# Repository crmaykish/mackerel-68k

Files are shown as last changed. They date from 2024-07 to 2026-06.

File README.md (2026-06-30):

# Mackerel 68k



Mackerel 68k is a family of homebrew single-board computers built around the Motorola 68000 line of processors plus a from-scratch effort to run **mainline Linux** on each one.

The project works its way up the 68k family one chip at a time, from the 68008 to the 68040. Each new board adds capability: more memory, faster CPUs, an FPU, an MMU, and richer peripherals. But the throughline is software - every Mackerel runs the **latest mainline Linux kernel**, from a tiny NOMMU uClinux shell on the 68008 up to a full MMU + hardware-FPU install on the 68030.

What's in the box, top to bottom:

- **Bespoke hardware** - custom PCBs with programmable logic chips (22V10 GALs on the 68008, Altera CPLDs on the later boards) handling address decoding, DRAM control, and interrupts.
- **A homegrown bootloader** - a small ROM monitor on every board with debug tools (peek, poke, memtest), YMODEM file transfer, and the ability to boot Linux from IDE or SD.
- **Custom toolchains** - bare-metal and Linux (MMU + NOMMU) GCC cross-compilers built with crosstool-ng.
- **Mainline Linux** - kernel port with drivers for the DUART, IDE storage, and Ethernet-over-SPI, booting to a BusyBox userspace.
- **Fully open source** - every schematic, PCB layout, logic file, and line of code is open, and hobbyists around the world have built their own Mackerel boards.

Three discrete boards are running today (68008, 68010, and 68030), with a 68040 system in the works - plus Mackerel-F, an FPGA build that runs a full Mackerel system on a soft 68000 core.

## Links

1. [Hackaday Project Page](https://hackaday.io/project/183861-mackerel-68k-computer)
2. [Mackerel Linux v7.1.x](https://github.com/crmaykish/mackerel-linux/tree/mackerel)
3. [Mackerel uClinux (deprecated)](https://github.com/crmaykish/mackerel-uclinux-20160919)

## Docs

1. [Mackerel-08 Assembly](docs/mackerel-08-board-assembly.md)
2. [How to Compile Code and Programmable Logic](docs/how-to-compile-everything.md)
3. [Building the Mackerel Toolchains](docs/building-the-mackerel-toolchains.md)
4. [Building and Booting Linux on Mackerel](docs/building-linux-for-mackerel.md)
5. [Building and Running Mackerel-F (FPGA)](docs/building-and-running-mackerel-f.md)

## Hardware

### Mackerel-08

Status: Complete

- MC68008 CPU (52-pin PLCC variant)
- 512 KB of Flash ROM, 3.5MB SRAM
- Two serial ports
- SD card support (bitbang SPI)
- Linux 7.1.x NOMMU

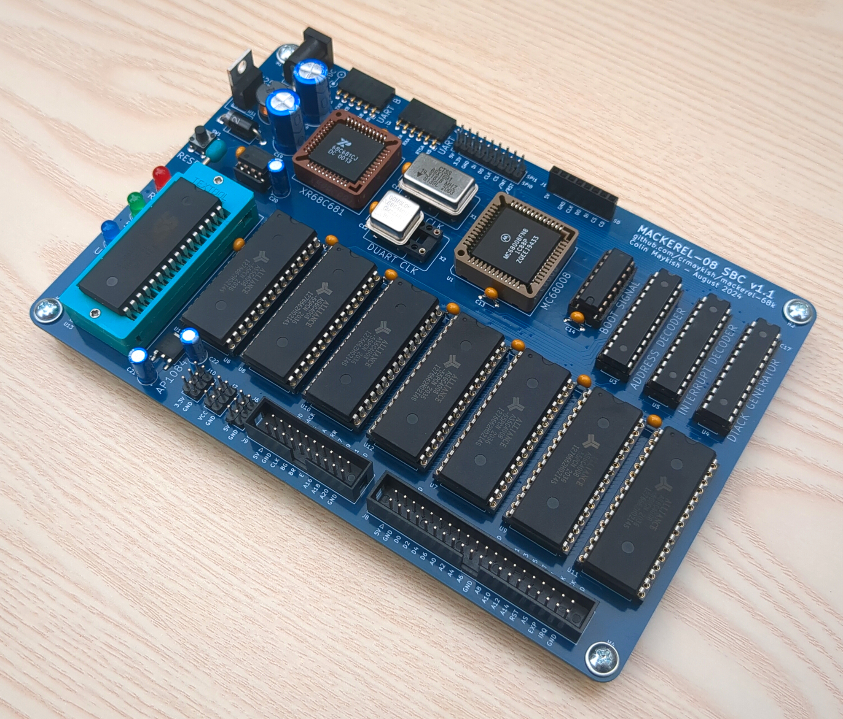
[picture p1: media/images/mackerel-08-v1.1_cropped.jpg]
Mackerel-08 SBC v1


Based on the original prototype hardware, this SBC combines the 52-pin PLCC MC68008, a 512KB Flash ROM, up to 3.5MB of SRAM, and a XR68C681 DUART on a single PCB. The DUART exposes two serial ports and three bit-banged SPI headers. One of these headers is currently used with an SD card breakout board to provide bulk storage.

Three 22V10 PLDs are used for address decoding, interrupt mapping, and DTACK generation. An expansion header breaks out address, data, and control lines to allow additional peripherals to be connected directly to the processor bus.

The address space is mapped as follows:

- RAM:    0x000000 - 0x37FFFF (up to 3.5 MB)
- ROM:    0x380000 - 0x3FBFFF (496/512 KB usable)
- DUART:  0x3FC000 - 0x3FDFFF (8KB)
- Exp:    0x3FE000 - 0x3FFFFF (Expansion header, 8KB)

Mackerel-08 uses a 74HC595 shift register to create a BOOT signal for the first eight /AS cycles of the CPU after reset. This BOOT signal is used by the address decoder PLD to map the ROM to address 0x000000 long enough for the CPU to read the initial stack pointer and program counter vectors from ROM. RAM is mapped to 0x000000 after that.

### Mackerel-10

Status: Complete

- MC68000 or MC68010 CPU
- 1 MB of ROM, 1 MB of SRAM
- Up to 16 MB of 30-pin DRAM (15 usable)
- Two serial ports
- IDE interface
- Linux 7.1.x NOMMU

Mackerel-10 v1

Mackerel-10 is the second SBC in the project. It expands on the design of Mackerel-08 with a MC68010 CPU (or equivalent), the same XR68C681 DUART, 1MB of Flash ROM, 1MB of SRAM, up to 16 MB of DRAM, and an IDE drive interface. Two CPLDs act as the glue logic and DRAM controller for the board. The SRAM is optional and the address space can be filled almost entirely with DRAM.

The memory map looks like this:

- DRAM:     0x000000 - 0xEFFFFF (15MB)
- ROM:      0xF00000 - 0xFF4000 (not quite 1MB)
- I/O:      0xF40000 - 0xFFFFFF

### Mackerel-30

Status: Prototype

- MC68030 CPU at 20 MHz
- MC68882 FPU
- 512 KB ROM, 512 KB SRAM
- 128 MB of 72-pin DRAM
- Two serial ports
- IDE interface
- Ethernet over SPI
- Linux 7.1.x

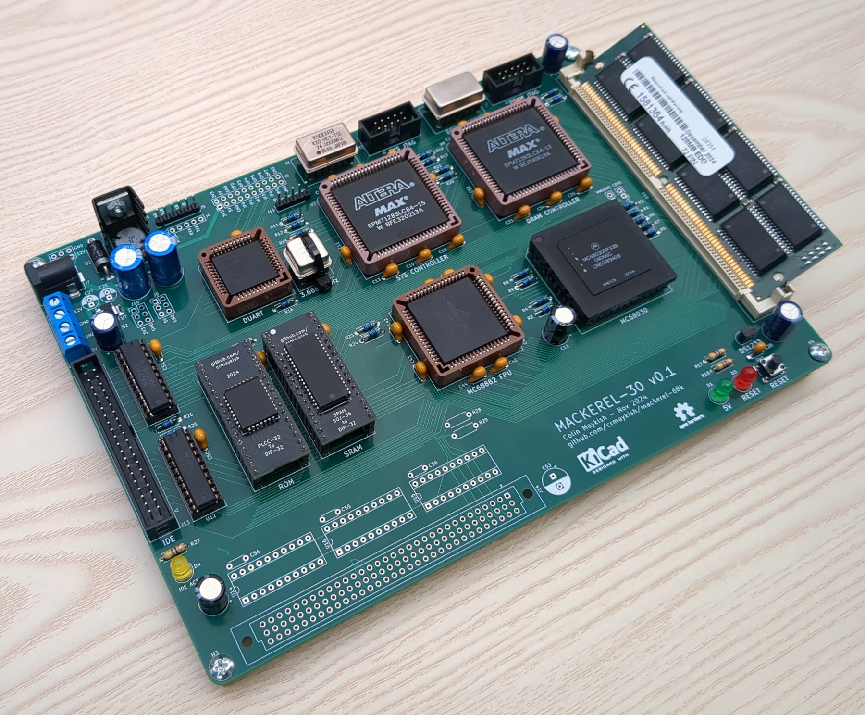
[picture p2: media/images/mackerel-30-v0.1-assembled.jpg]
Mackerel-30 v0.1


Mackerel-30 is based on the 68030 CPU. It includes the DUART and IDE interface from Mackerel-10 and upgrades the DRAM controller to use a 72-pin SIMM. It also includes a MC68882 FPU.

### Mackerel-40
Status: Design

- 68040 CPU at 33 MHz (internal MMU and FPU)
- 2 MB of ROM, 2 MB SRAM
- 2x72 pin SIMMs (up to 256 MB of DRAM)
- Dedicated I/O controller (SPI, I2C, GPIO)
- DUART and IDE from earlier boards

### Mackerel-F

Status: Prototype (FPGA)

- fx68k soft 68000 core at 37.8 MHz, in a Tang Nano 20k
- 8 MB SDRAM
- 30 KB ROM (bootloader) and 32 KB BSRAM
- UART console, programmable timer, and interrupt controller
- microSD (SPI) and W5500 Ethernet
- Linux 7.1.x NOMMU

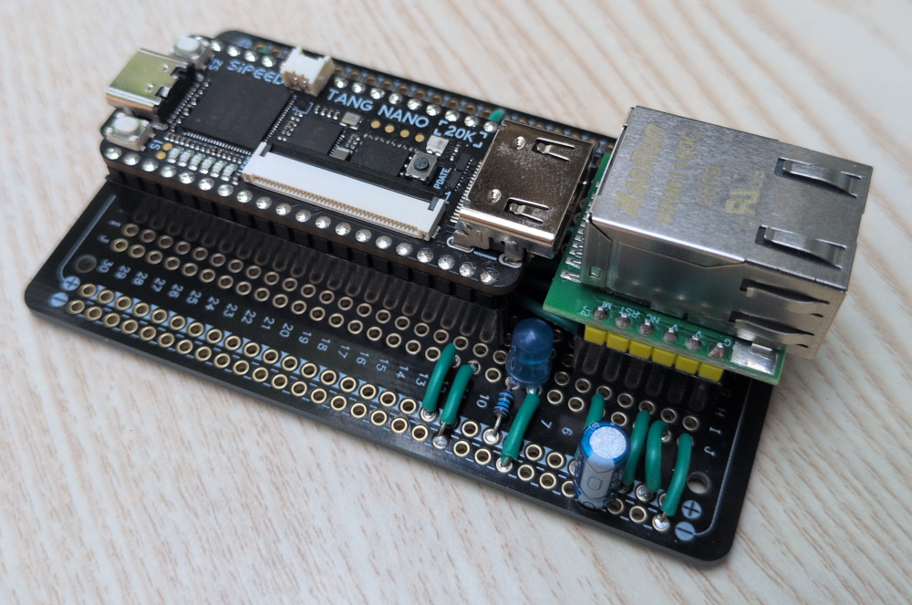
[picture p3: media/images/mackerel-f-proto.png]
Mackerel-F on a Tang Nano 20k


Mackerel-F is an entire Mackerel system implemented inside an FPGA. Everything that is discrete hardware on the other boards - the CPU, glue logic, memory controller, UART, timer, interrupt controller, and SPI masters - is RTL here, built around the [fx68k](https://github.com/ijor/fx68k) soft 68000 core and synthesized for the Tang Nano 20k. The SoC runs at 75.6 MHz with the 68000 core clocked at half that (37.8 MHz).

Unlike the other boards there is no separate ROM chip: the bootloader is baked into the FPGA bitstream as on-chip ROM and its scratch RAM lives in block RAM, so the entire 8 MB of SDRAM is free for Linux. Alongside the usual `boot` (from SD) and YMODEM transfer, the bootloader adds a `netboot` command that pulls the kernel over Ethernet (raw TCP, with a small host server) and a five-second SD autoboot.

The memory map:

- RAM:    0x000000 - 0x7FFFFF (8 MB SDRAM, the top 384 KB holds the execute-in-place root filesystem)
- BSRAM:  0xFF0000 - 0xFF7FFF (32 KB, bootloader RAM)
- ROM:    0xFF8000 - 0xFFF7FF (30 KB, bootloader ROM)
- I/O:    0xFFF800 - 0xFFFFFF (GPIO, UART, timer, two SPI masters, interrupt controller)

It boots mainline NOMMU uClinux to a BusyBox shell from a ROMfs root run in place from SDRAM, with the microSD for storage and the W5500 for networking. See [Building and Running Mackerel-F (FPGA)](docs/building-and-running-mackerel-f.md).

## Software

### Bootloader and Bare-metal Programs
Every version of Mackerel runs a small bootloader program installed on the Flash ROM. This provides a simple set of debugging tools (peek, poke, memtest, etc.) as well as two methods for loading external code.

The bootloader supports the YMODEM protocol for loading programs and data into RAM (see the `ymodem` command), using `lrzsz-sb` on the PC for example. Other terminal programs like TeraTerm should also work.

The `boot` command is used to load the Linux kernel from disk (SD or IDE). It expects a `IMAGE.BIN` file on the first FAT16 partition of the drive. See the `prepare_disk.sh` script in the [mackerel-linux repository](https://github.com/crmaykish/mackerel-linux).

On Mackerel-F the bootloader also supports `netboot` (pulling the kernel over Ethernet) and a five-second SD autoboot on power-up.

### Linux on Mackerel

Every Mackerel board runs the latest mainline kernel (v7.1.x). Mackerel-08, Mackerel-10, and the FPGA-based Mackerel-F run NOMMU and are more limited in their capabilities. Mackerel-30 supports the MMU and the external FPU in Linux and functions more like a traditional headless Linux install. Userspace is made up of busybox (init and shell) with driver support for the DUART, IDE storage, and networking over SPI.

### Compilers and Tools
There are three different toolchains for Mackerel. The baremetal toolchain builds the bootloader and other low level programs in this repo. There are also two variants of the Linux toolchain - one for Mackerel-30 with MMU support and the other for NOMMU/ucLinux on Mackerel-08/10. Prebuilt toolchains are available on the [releases page](https://github.com/crmaykish/mackerel-68k/releases/tag/toolchains-2026-06-06); see [Building the Mackerel Toolchains](docs/building-the-mackerel-toolchains.md) for both the download steps and instructions on building them all with crosstools-ng.

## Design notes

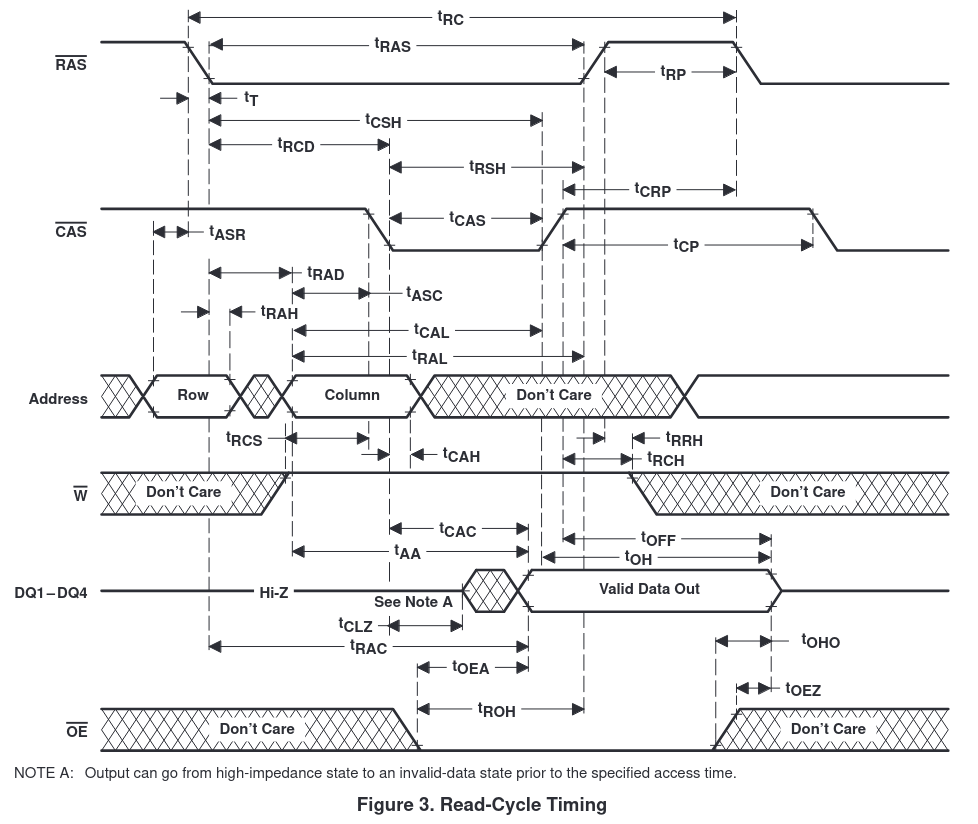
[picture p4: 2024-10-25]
media/images/dram_read_timing.png

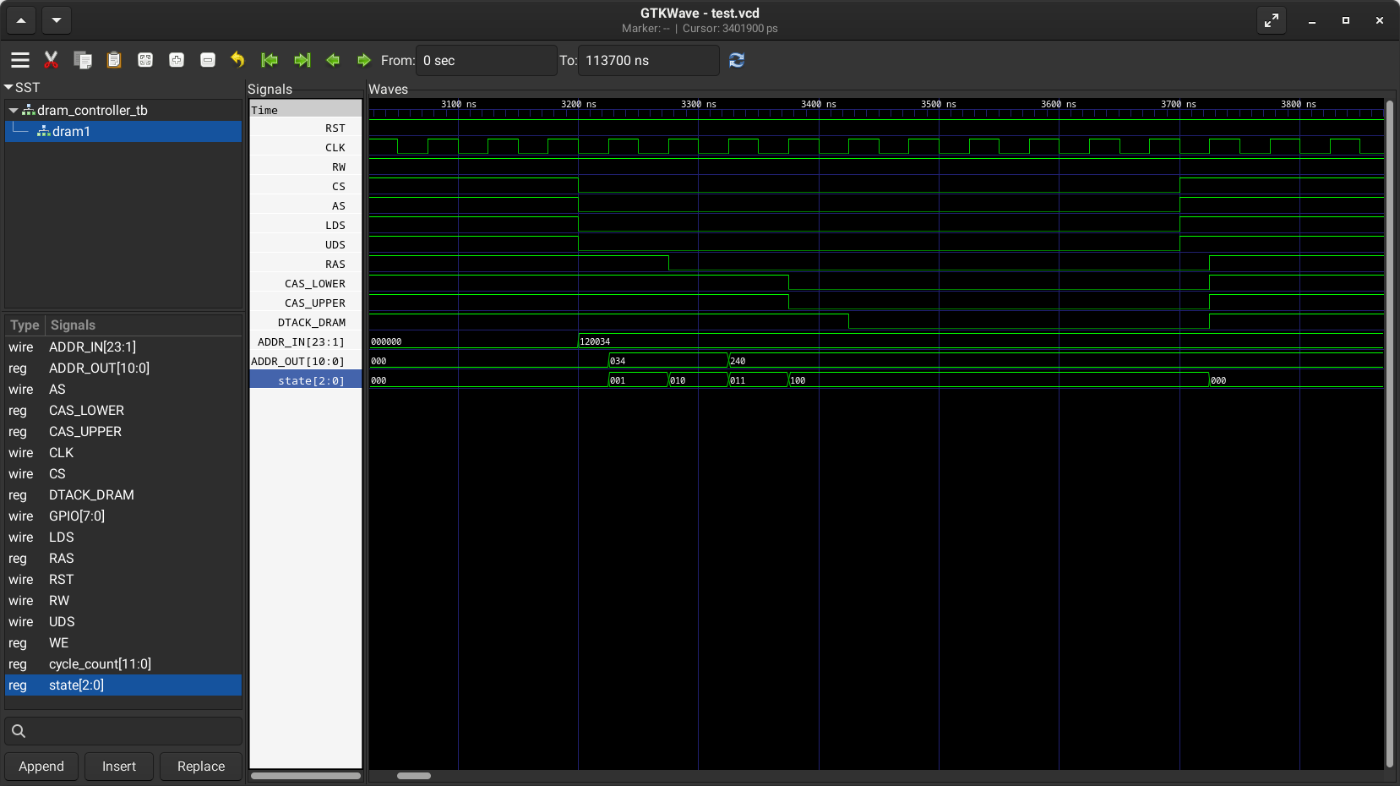
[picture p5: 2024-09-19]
media/images/dram_read_cycle_simulation.png

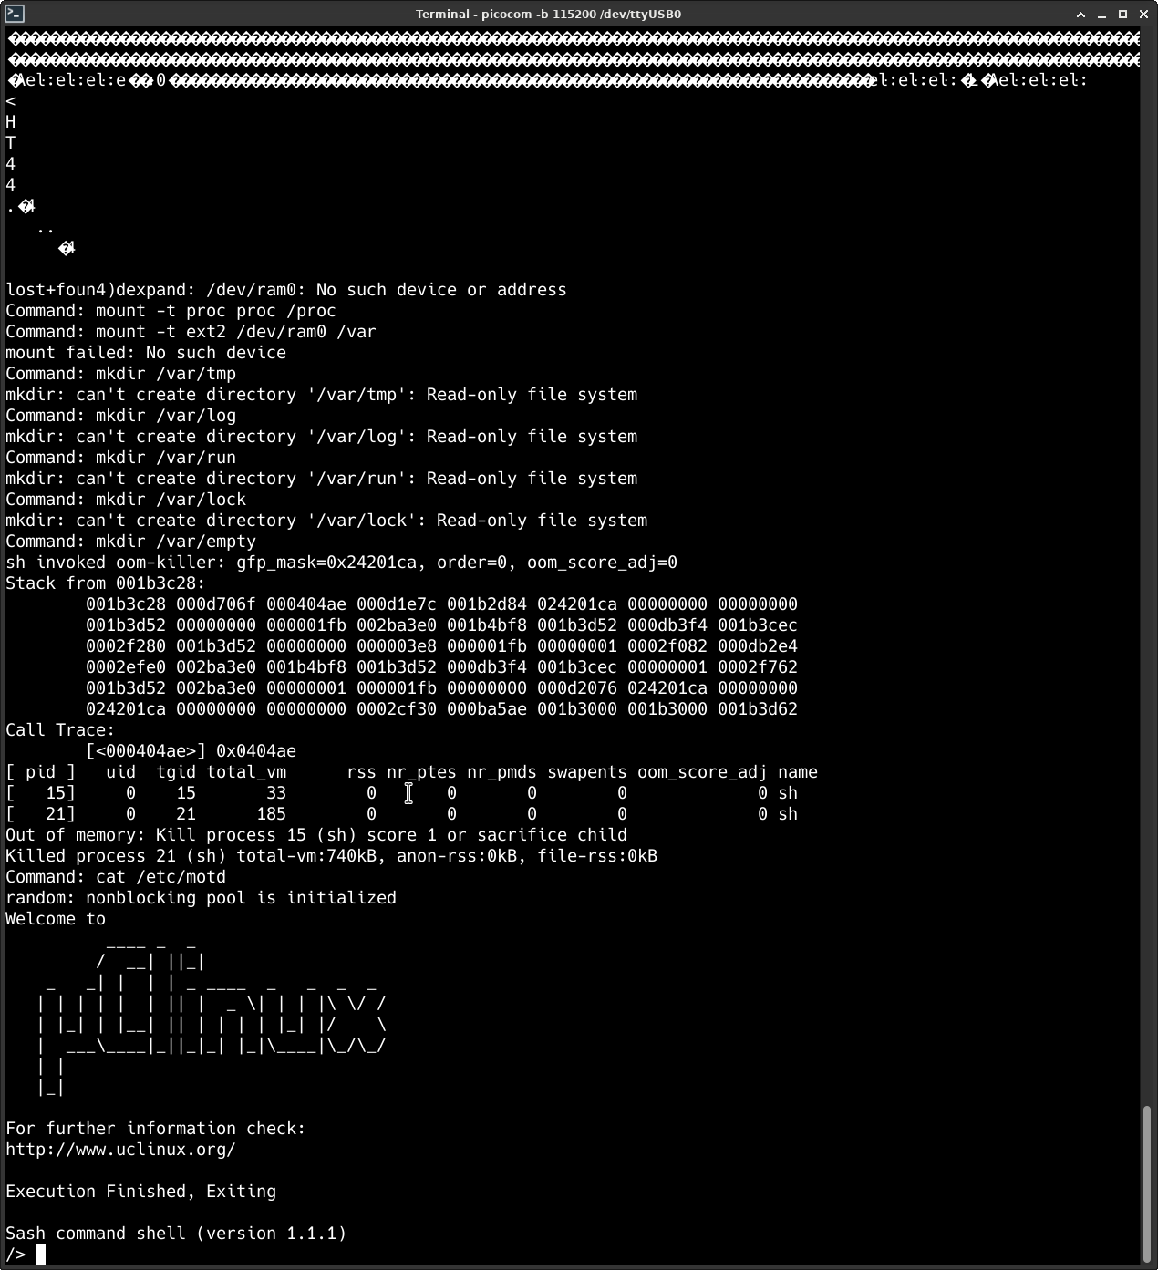
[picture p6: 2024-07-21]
media/images/uclinux-4.4-first-real-boot.png

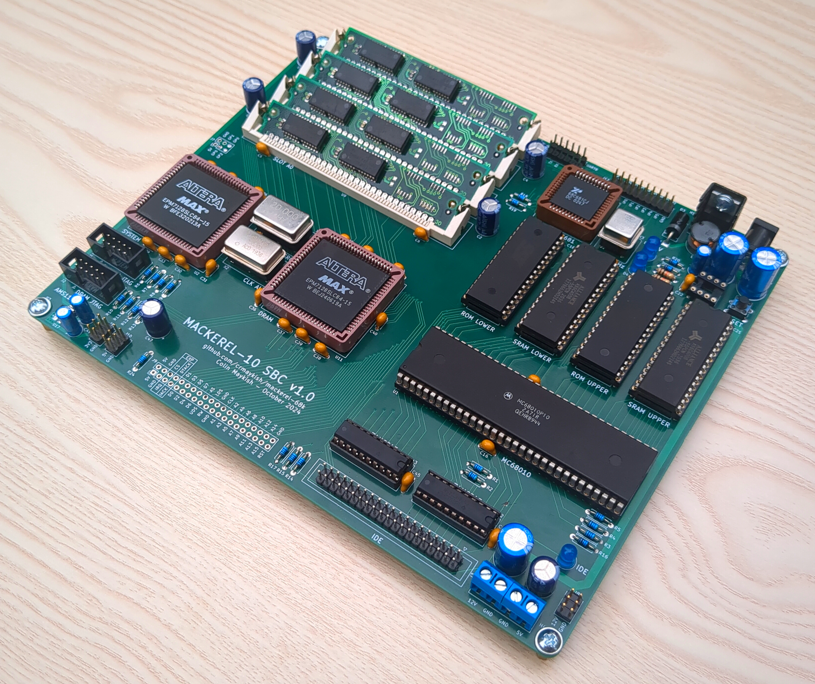
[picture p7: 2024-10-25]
media/images/mackerel-10-v1_cropped.jpg

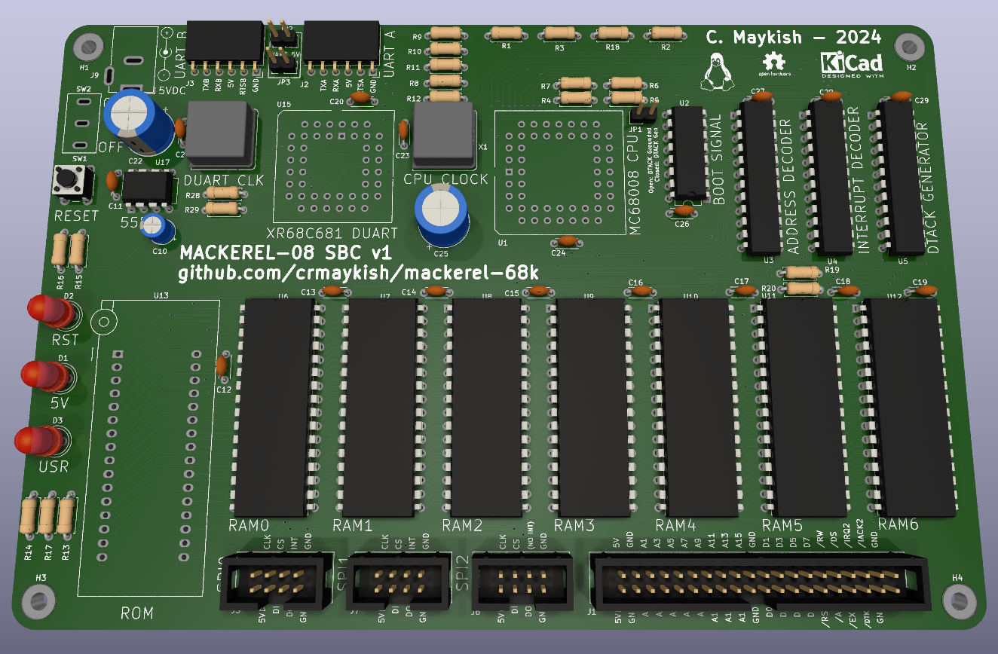
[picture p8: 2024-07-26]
media/images/mackerel-08-sbc-v1-render.png

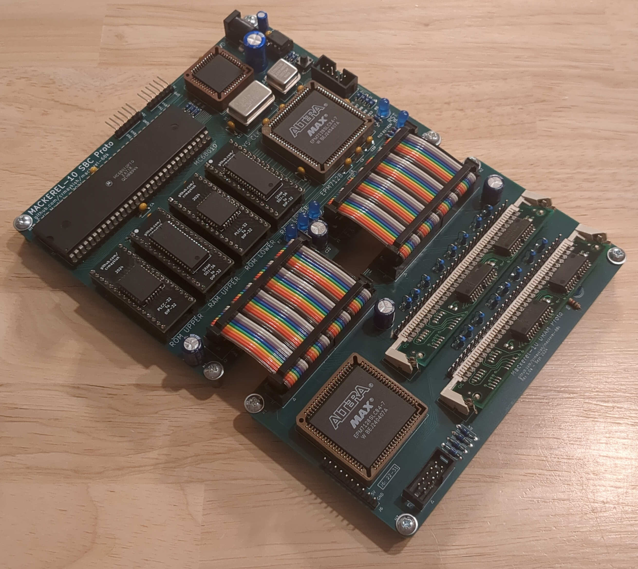
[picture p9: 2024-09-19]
media/images/mack-10-with-dram-controller.jpg

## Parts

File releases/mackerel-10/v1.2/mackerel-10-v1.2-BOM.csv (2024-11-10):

Reference | Value | Datasheet | Footprint | Qty | DNP
C1,C2,C3,C4,C5,C6,C7,C8,C9,C10,C11,C12,C13,C14,C15,C16,C21,C22,C23,C24,C25,C26,C27,C28,C29,C30,C31,C32,C33,C34,C35,C36,C37,C38,C41,C42 | 0.1uF | ~ | Capacitor_THT:C_Disc_D4.3mm_W1.9mm_P5.00mm | 36
C17,C18,C19,C20,C40,C49 | 470uF | ~ | Capacitor_THT:CP_Radial_D8.0mm_P3.50mm | 6
C39,C43,C44 | 1000uF | ~ | Capacitor_THT:CP_Radial_D10.0mm_P5.00mm | 3
C45,C46 | 10uF | ~ | Capacitor_THT:CP_Radial_D5.0mm_P2.00mm | 2
C47 | 0.01uF | ~ | Capacitor_THT:C_Disc_D4.3mm_W1.9mm_P5.00mm | 1
D1,D2,D4 | LED | ~ | LED_THT:LED_D5.0mm | 3
D3 | 1N5822 | ~ | Diode_THT:D_DO-27_P15.24mm_Horizontal | 1
HS1 | Heatsink | ~ | Heatsink:Heatsink_Stonecold_HS-S02_13.21x9.53mm | 1
J1,J3 | Conn_02x05_Odd_Even | ~ | Connector_IDC:IDC-Header_2x05_P2.54mm_Vertical | 2
J2,J10,J11,J12 | Conn_02x03_Odd_Even | ~ | Connector_PinHeader_2.54mm:PinHeader_2x03_P2.54mm_Vertical | 4
J4 | Screw_Terminal_01x04 | ~ | TerminalBlock:TerminalBlock_bornier-4_P5.08mm | 1
J5,J13 | Conn_02x20_Odd_Even | ~ | -- mixed values -- | 2
J6,J7 | Conn_01x06 | ~ | Connector_PinHeader_2.54mm:PinHeader_1x06_P2.54mm_Vertical | 2
J8 | Conn_02x10_Odd_Even | ~ | Connector_PinHeader_2.54mm:PinHeader_2x10_P2.54mm_Vertical | 1
J9 | Barrel_Jack_MountingPin | ~ | Connector_BarrelJack:BarrelJack_Horizontal | 1
L1 | 100uH | ~ | Inductor_THT:L_Radial_D10.0mm_P5.00mm_Fastron_07M | 1
R1,R2,R3,R4,R5,R6,R7,R8,R9,R10,R11,R12,R13,R14,R15,R16,R17,R19,R20 | 4k7 | ~ | Resistor_THT:R_Axial_DIN0207_L6.3mm_D2.5mm_P7.62mm_Horizontal | 19
R18,R21,R22 | 1k | ~ | Resistor_THT:R_Axial_DIN0207_L6.3mm_D2.5mm_P7.62mm_Horizontal | 3
SW1 | SW_Push | ~ | Button_Switch_THT:SW_PUSH_6mm_H5mm | 1
U1 | 68010D | https://www.nxp.com/docs/en/reference-manual/MC68000UM.pdf | Package_DIP:DIP-64_W22.86mm | 1
U2,U7,U8,U9,U10,U11 | ~ |  | -- mixed values -- | 6
U3,U5 | SST39SF040 | http://ww1.microchip.com/downloads/en/DeviceDoc/25022B.pdf | Package_DIP:DIP-32_W15.24mm | 2
U4,U6 | AS6C4008-55PCN | https://www.alliancememory.com/wp-content/uploads/pdf/AS6C4008.pdf | Package_DIP:DIP-32_W15.24mm | 2
U12,U13 | 74HC245 | http://www.ti.com/lit/gpn/sn74HC245 | Package_DIP:DIP-20_W7.62mm_Socket | 2
U14 | XR68C681 |  | Package_LCC:PLCC-44_THT-Socket | 1
U15 | LM2576T-5 | http://www.ti.com/lit/ds/symlink/lm2576.pdf | Package_TO_SOT_THT:TO-220-5_Vertical | 1
U16 | AMS1117-3.3 | http://www.advanced-monolithic.com/pdf/ds1117.pdf | Package_TO_SOT_SMD:SOT-223-3_TabPin2 | 1
U17 | DS1233 |  | Package_TO_SOT_THT:TO-92L_Inline | 1
X1,X2 | 50MHz | http://cdn-reichelt.de/documents/datenblatt/B400/OSZI.pdf | Oscillator:Oscillator_DIP-14 | 2
X3 | 3.6864MHz | http://cdn-reichelt.de/documents/datenblatt/B400/OSZI.pdf | Oscillator:Oscillator_DIP-8 | 1

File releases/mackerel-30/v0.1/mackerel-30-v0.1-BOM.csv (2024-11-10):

Reference | Value | Datasheet | Footprint | Qty | DNP
C1,C2,C3,C4,C5,C6,C7,C8,C9,C10,C12,C13,C14,C15,C16,C17,C18,C19,C20,C21,C22,C23,C29,C30,C31,C32,C33,C34,C35,C36,C38,C39,C40,C42,C43,C44,C45,C46,C47,C48,C49,C50,C51,C54,C55,C56 | 0.1uF | ~ | -- mixed values -- | 46
C11,C37,C41,C52,C53,C57 | 470uF | ~ | Capacitor_THT:CP_Radial_D8.0mm_P3.50mm | 6
C24,C26 | 1000uF | ~ | Capacitor_THT:CP_Radial_D10.0mm_P5.00mm | 2
C25,C27 | 10uF | ~ | Capacitor_THT:CP_Radial_D5.0mm_P2.00mm | 2
C28 | 0.01uF | ~ | Capacitor_THT:C_Disc_D4.3mm_W1.9mm_P5.00mm | 1
D1,D3,D4 | LED | ~ | LED_THT:LED_D5.0mm | 3
D2 | 1N5822 | ~ | Diode_THT:D_DO-27_P15.24mm_Horizontal | 1
HS1 | Heatsink | ~ | Heatsink:Heatsink_Stonecold_HS-S02_13.21x9.53mm | 1
J1,J2 | Conn_01x02 | ~ | Connector_PinHeader_2.54mm:PinHeader_1x02_P2.54mm_Vertical | 2
J3,J11 | Conn_02x05_Odd_Even | ~ | Connector_IDC:IDC-Header_2x05_P2.54mm_Vertical | 2
J4,J5 | Conn_01x06 | ~ | Connector_PinHeader_2.54mm:PinHeader_1x06_P2.54mm_Vertical | 2
J6 | Conn_02x10_Odd_Even | ~ | Connector_PinHeader_2.54mm:PinHeader_2x10_P2.54mm_Vertical | 1
J7 | Barrel_Jack_MountingPin | ~ | Connector_BarrelJack:BarrelJack_Horizontal | 1
J8,J9,J10 | Conn_02x03_Odd_Even | ~ | Connector_PinHeader_2.54mm:PinHeader_2x03_P2.54mm_Vertical | 3
J12 | Screw_Terminal_01x04 | ~ | TerminalBlock:TerminalBlock_bornier-4_P5.08mm | 1
J13 | Conn_02x20_Odd_Even | ~ | Connector_IDC:IDC-Header_2x20_P2.54mm_Vertical | 1
J14 | DIN41612_03x32_ABC | ~ | Connector_DIN:DIN41612_C_3x32_Female_Vertical_THT | 1
J15 | Conn_01x05 | ~ | Connector_PinHeader_2.54mm:PinHeader_1x05_P2.54mm_Vertical | 1
L1 | 100uH | ~ | Inductor_THT:L_Radial_D10.0mm_P5.00mm_Fastron_07M | 1
R1,R2,R3,R4,R5,R6,R7,R8,R9,R10,R11,R12,R13,R14,R15,R16,R19,R20,R21,R22,R23,R24,R25,R26,R28,R29 | 4k7 | ~ | Resistor_THT:R_Axial_DIN0207_L6.3mm_D2.5mm_P7.62mm_Horizontal | 26
R17,R18,R27 | 1k | ~ | Resistor_THT:R_Axial_DIN0207_L6.3mm_D2.5mm_P7.62mm_Horizontal | 3
SW1 | SW_Push | ~ | Button_Switch_THT:SW_PUSH_6mm_H5mm | 1
U1 | MC68030RC |  | mackerel:PGA169 | 1
U2,U9 | EPM7128 |  | Package_LCC:PLCC-84_THT-Socket | 2
U3 | SST39SF040 | http://ww1.microchip.com/downloads/en/DeviceDoc/25022B.pdf | Package_DIP:DIP-32_W15.24mm_Socket | 1
U4 | AS6C4008-55PCN | https://www.alliancememory.com/wp-content/uploads/pdf/AS6C4008.pdf | Package_DIP:DIP-32_W15.24mm_Socket | 1
U5 | XR68C681 |  | Package_LCC:PLCC-44_THT-Socket | 1
U6 | LM2576T-5 | http://www.ti.com/lit/ds/symlink/lm2576.pdf | Package_TO_SOT_THT:TO-220-5_Vertical | 1
U7 | AMS1117-3.3 | http://www.advanced-monolithic.com/pdf/ds1117.pdf | Package_TO_SOT_SMD:SOT-223-3_TabPin2 | 1
U8 | DS1233 |  | Package_TO_SOT_THT:TO-92L_Inline | 1
U10 | SIMM72 |  | mackerel:SIMM-72 | 1
U11 | MC68882 |  | Package_LCC:PLCC-68_THT-Socket | 1
U12,U13,U14,U15,U16 | 74HC245 | http://www.ti.com/lit/gpn/sn74HC245 | Package_DIP:DIP-20_W7.62mm_Socket | 5
X1,X3 | CXO_DIP14 | http://cdn-reichelt.de/documents/datenblatt/B400/OSZI.pdf | Oscillator:Oscillator_DIP-14 | 2
X2 | 3.6864MHz | http://cdn-reichelt.de/documents/datenblatt/B400/OSZI.pdf | Oscillator:Oscillator_DIP-8 | 1

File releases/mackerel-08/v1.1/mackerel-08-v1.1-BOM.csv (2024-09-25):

Reference | Value | Datasheet | Footprint | Qty | DNP
C1,C2,C3,C4,C5,C6,C7,C8,C9,C10,C11,C12,C13,C14,C15,C16,C17 | 0.1uF | ~ | Capacitor_THT:C_Disc_D4.3mm_W1.9mm_P5.00mm | 17
C18,C19 | 1000uF | ~ | Capacitor_THT:CP_Radial_D10.0mm_P5.00mm | 2
C20,C21,C22 | 10uF | ~ | Capacitor_THT:CP_Radial_D5.0mm_P2.50mm | 3
D1,D2,D4 | LED | ~ | LED_THT:LED_D5.0mm | 3
D3 | 1N5822 | ~ | Diode_THT:D_DO-27_P15.24mm_Horizontal | 1
H1,H2,H3,H4 | MountingHole | ~ | MountingHole:MountingHole_3.2mm_M3_Pad | 4
HS1 | Heatsink | ~ | Heatsink:Heatsink_Stonecold_HS-S02_13.21x9.53mm | 1
J1 | Conn_01x08 | ~ | Connector_PinSocket_2.54mm:PinSocket_1x08_P2.54mm_Vertical | 1
J2 | Conn_02x09_Odd_Even | ~ | Connector_PinHeader_2.54mm:PinHeader_2x09_P2.54mm_Vertical | 1
J3,J4 | Conn_01x06 | ~ | Connector_PinSocket_2.54mm:PinSocket_1x06_P2.54mm_Horizontal | 2
J5 | Barrel_Jack_MountingPin | ~ | Connector_BarrelJack:BarrelJack_Horizontal | 1
J6,J7,J10 | Conn_02x03_Odd_Even | ~ | Connector_PinHeader_2.54mm:PinHeader_2x03_P2.54mm_Vertical | 3
J8 | Conn_02x20_Odd_Even | ~ | Connector_IDC:IDC-Header_2x20_P2.54mm_Vertical | 1
J9 | Conn_02x10_Odd_Even | ~ | Connector_IDC:IDC-Header_2x10_P2.54mm_Vertical | 1
L1 | 100uH | ~ | Inductor_THT:L_Radial_D10.0mm_P5.00mm_Fastron_07M | 1
R1,R2,R3,R4,R5,R6,R7,R8,R9,R10,R11,R12,R13,R14,R16,R17,R18,R19 | 4k7 | ~ | Resistor_SMD:R_1206_3216Metric_Pad1.30x1.75mm_HandSolder | 18
R15,R20,R23 | 1k | ~ | Resistor_SMD:R_1206_3216Metric_Pad1.30x1.75mm_HandSolder | 3
R21,R22 | 10k | ~ | Resistor_SMD:R_1206_3216Metric_Pad1.30x1.75mm_HandSolder | 2
SW1 | SW_Push | ~ | Button_Switch_THT:SW_PUSH_6mm_H5mm | 1
U1 | MC68008 |  | Package_LCC:PLCC-52_THT-Socket | 1
U2 | 74HC595 | http://www.ti.com/lit/ds/symlink/sn74hc595.pdf | Package_DIP:DIP-16_W7.62mm | 1
U3,U4,U5 | ATF22V10C |  | Package_DIP:DIP-24_W7.62mm | 3
U6,U7,U8,U9,U10,U11,U12 | AS6C4008-55PCN | https://www.alliancememory.com/wp-content/uploads/pdf/AS6C4008.pdf | Package_DIP:DIP-32_W15.24mm | 7
U13 | SST39SF040 |  | Socket:DIP_Socket-32_W11.9_W12.7_W15.24_W17.78_W18.5_3M_232-1285-00-0602J | 1
U14 | XR68C681 |  | Package_LCC:PLCC-44_THT-Socket | 1
U15 | LM2576T-5 | http://www.ti.com/lit/ds/symlink/lm2576.pdf | Package_TO_SOT_THT:TO-220-5_Vertical | 1
U16 | NE555P | http://www.ti.com/lit/ds/symlink/ne555.pdf | Package_DIP:DIP-8_W7.62mm | 1
U17 | AP1084 |  | Package_TO_SOT_SMD:TO-252-2 | 1
X1,X2 | CXO_DIP14 | http://cdn-reichelt.de/documents/datenblatt/B400/OSZI.pdf | Oscillator:Oscillator_DIP-14 | 2

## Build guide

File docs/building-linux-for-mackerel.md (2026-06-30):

# Building and Booting Linux on Mackerel

## Quick reference

```sh
# Replace '30' with '10', '08', or 'f' depending on your target
bash clean_all.sh
bash build_busybox.sh 30
bash build_rootfs.sh 30
bash build_kernel.sh 30
sudo bash prepare_disk.sh /dev/sdX # First time only
sudo bash install_disk.sh /dev/sdX 30
minipro -p SST39SF040 -s -w rom08.bin # Mackerel-08 only
# Insert card, power on, run `boot` from the bootloader
```
---

Every Mackerel board runs the **same mainline Linux kernel** (currently 7.1). There is a single in-tree platform, `arch/m68k/mackerel/`, shared by every board; the per-board differences (CPU, MMU vs. NOMMU, memory map, root filesystem) are selected by a defconfig. Everything is built from the [mackerel-linux](https://github.com/crmaykish/mackerel-linux) repo through the **same handful of scripts**, each of which takes a single board argument:

| Board | Argument | CPU | MMU | Root filesystem | Storage |
|---|---|-----|-----|---|---|
| Mackerel-30 | `30` (default) | 68030 | yes | ext4 on disk (`/dev/sda2`) | IDE / CompactFlash |
| Mackerel-10 | `10` | 68000/68010 | no | embedded initramfs, optional ext root on `/dev/sda2` | IDE / CompactFlash |
| Mackerel-08 | `08` | 68008 | no | ROMfs flashed to the ROM chip | (none) |
| Mackerel-F | `f` | 68000 (fx68k softcore) | no | ROMfs run in place from SDRAM | microSD (SPI) |

Every board boots the same way: the bootloader's `boot` command reads `IMAGE.BIN` from the boot partition of the storage device into RAM and jumps to it. (Mackerel-F can also pull the image over Ethernet with `netboot`; see [Building and Running Mackerel-F (FPGA)](building-and-running-mackerel-f.md).)

In every command below, swap the board argument (`30`, `10`, `08`, or `f`) to target a different board. The argument defaults to `30` if omitted.

## Prerequisites

1. **Toolchains.** Mackerel-30 uses the musl toolchain (`m68k-mackerel-linux-musl-`); Mackerel-08, Mackerel-10, and Mackerel-F share the uClibc NOMMU toolchain (`m68k-mackerel-uclinux-uclibc-`). The build scripts pick the right one from the board argument. See [Building the Mackerel Toolchains](building-the-mackerel-toolchains.md).

2. **The kernel source.**

   ```sh
   git clone https://github.com/crmaykish/mackerel-linux
   cd mackerel-linux
   git checkout mackerel
   ```

3. **Host tools.** `parted` + `mkfs.fat`/`mkfs.ext4` for preparing the storage media. Building the Mackerel-08 root filesystem also needs `genromfs` (on Arch it is in the AUR). `lrzsz` (the `lrzsz-sb` sender) is only needed for the YMODEM fallback described at the end. The `tools/install_reqs_*` scripts in the main repo install these.

## Building

The build is the same three steps for every board - BusyBox, then the root filesystem, then the kernel - run from the repo root:

```sh
bash build_busybox.sh 30    # build BusyBox (bFLT on NOMMU)
bash build_rootfs.sh  30    # assemble the root filesystem for this board
bash build_kernel.sh  30    # distclean + defconfig + build -> image.bin
```

Run them in that order - `build_rootfs.sh` needs the BusyBox binary, and `build_kernel.sh` embeds the root filesystem into the image. Each script prints what it produced; the final artifact is always **`image.bin`** in the repo root.

What each board's scripts produce:

- **Mackerel-30** - BusyBox `busybox` (dynamic musl), a full root tree in `rootfs_mackerel30/` (written to disk separately), and a ~5 MB `image.bin` that loads and runs at `0x1000`.
- **Mackerel-10** - BusyBox `busybox_nommu` (bFLT), an XIP ROMfs root appended into `image.bin` (via `MTD_UCLINUX`; bare ROMfs intermediate is `rom.bin`), which loads and runs at `0x400`.
- **Mackerel-08** - BusyBox `busybox_mackerel08` (bFLT), also assembles `rom08.bin`.
- **Mackerel-F** - BusyBox `busybox_mackerelf` (bFLT), an XIP ROMfs root appended into `image.bin` (via `MTD_UCLINUX`; bare ROMfs intermediate is `rom.bin`), which loads and runs at `0x400`.

To start completely fresh, `bash clean_all.sh` removes all build products and intermediate trees.

## Booting

Write `image.bin` to the storage media, put it in the board, and run `boot` from the bootloader prompt. The two disk scripts handle the media for every board and take the same board argument as the build (replace `/dev/sdX` with your card's device - double-check it, this erases the media):

```sh
sudo bash prepare_disk.sh /dev/sdX        # FAT16 16 MB (boot) + ext4 100 MB (root)
sudo bash install_disk.sh /dev/sdX 30     # IMAGE.BIN -> boot partition, rootfs -> root partition
```

`prepare_disk.sh` only needs to be run once per card and should support any drive 128 MB or bigger. After rebuilding the kernel or rootfs, re-run `install_disk.sh` to update the media. What gets written depends on the board:

- **Mackerel-30** - `IMAGE.BIN` to the FAT16 boot partition and the full ext4 root tree to `sda2`. `boot` reads the image into RAM, writes the Linux bootinfo records after it, and jumps to the kernel, which mounts `sda2` as root.
- **Mackerel-10** - `IMAGE.BIN` to the boot partition and the ext root to `sda2`. The image carries a self-contained initramfs, so it boots without a root on `sda2`; if one is present, `/init` `switch_root`s into it (falling back to the RAM initramfs if the disk is absent).
- **Mackerel-08** - just `IMAGE.BIN` to the SD card's FAT partition; the root filesystem is a ROMfs file that gets flashed to the actual ROM chip.
- **Mackerel-F** - `IMAGE.BIN` and `ROMFS.BIN` to the FAT16 boot partition (`install_disk.sh f`); the kernel runs the ROMfs root in place from SDRAM. The image can also be pulled over Ethernet - see [Building and Running Mackerel-F (FPGA)](building-and-running-mackerel-f.md).

> **NOTE:** Mackerel-08 expects its root filesystem to be in the 512KB ROM alongside the bootloader. The `rom08.bin` file can be flashed with minipro any time after running the `build_rootfs.sh` script. This is required to boot Linux.

In every case the board reads the image off its storage device and starts Linux with the `boot` command - no host connection required beyond the serial console.

## Transferring the image over serial (fallback)

Alternatively, the Linux image can be sent to the board over the serial console with YMODEM instead of reading it from storage. This avoids pulling the card, but it is **much slower** (the image is several MB at 115200 baud) and is really just a backup path. From the bootloader prompt:

1. Run `ymodem` to enter receive (default load address: `0x1000` on Mackerel-30, `0x400` on Mackerel-08/10/F).
2. Send `image.bin` with a YMODEM sender, e.g. `lrzsz-sb --ymodem -k -b image.bin`.
3. Run `run` to jump to the kernel.

The repo's `boot08.sh` automates the whole power-cycle → transfer → run → capture loop for Mackerel-08, and the scriptable transfer sequence (holding the serial fd open across `lrzsz-sb`, etc.) is documented in the top-level `CLAUDE.md` under *Automated Hardware-in-the-Loop Workflow*.

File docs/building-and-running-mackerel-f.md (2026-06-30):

# Building and Running Mackerel-F (FPGA)

Mackerel-F is an entire Mackerel system - a soft 68000 core plus all of its glue
logic, memory controller, and peripherals - implemented in RTL and synthesized for
a [Tang Nano 20k](https://wiki.sipeed.com/hardware/en/tang/tang-nano-20k/nano-20k.html)
development board. It runs the same bootloader and the same mainline Linux kernel as
the discrete boards.

The design lives in [`pld/mackerel-f/`](../pld/mackerel-f/). The firmware target is
`BOARD=mackf` (see [How to Compile Everything](how-to-compile-everything.md) and the
firmware [Makefile](../firmware/Makefile)).

## Prerequisites

- **Gowin EDA** (the free "Education" edition is fine) for synthesis and place &
  route. The build calls its command-line tool, `gw_sh`.
- **[oss-cad-suite](https://github.com/YosysHQ/oss-cad-suite-build)** for `sv2v`
  (the fx68k core is SystemVerilog and is converted to Verilog before synthesis) and
  `openFPGALoader` (loads the bitstream over the onboard JTAG). Add its `bin/` to your
  `PATH` before running `make`.
- The **bare-metal toolchain** (`m68k-mackerel-elf-`) to build the bootloader ROM
  image. See [Building the Mackerel Toolchains](building-the-mackerel-toolchains.md).

## Fetch the soft cores

The third-party cores (fx68k, the uart16550 and tiny_spi OpenCores blocks, and the
nand2mario SDRAM controller) are pulled in by a script rather than vendored:

```sh
cd pld/mackerel-f
./get_cores.sh        # clones the cores into pld/mackerel-f/cores/
```

## Build the bootloader ROM and the bitstream

The bootloader is baked into the bitstream as on-chip ROM, so it is built first and
copied into the FPGA project, then the whole thing is synthesized.

```sh
# 1. Build the ROM image from the firmware and copy it into the FPGA project
cd firmware
make BOARD=mackf bootloader.hex
cp bootloader.hex ../pld/mackerel-f/rom.hex

# 2. Synthesize, place & route, and load
cd ../pld/mackerel-f
make                  # sv2v + Gowin synth/PnR -> impl/pnr/mackerel_f.fs
make prog             # load into SRAM (volatile, fast to iterate; lost on power cycle)
make flash            # OR: write the SPI flash (persists across a power cycle)
```

Re-run step 1 (and the `cp`) whenever the firmware changes - the Makefile does not
regenerate `rom.hex` automatically, but it does treat `rom.hex` as a synthesis input,
so a changed ROM forces a re-synth on the next `make`.

Other self-contained bare-metal programs can be built the same way and dropped in as
the ROM for bring-up testing, e.g. `make BOARD=mackf sdramtest.hex` for an 8 MB SDRAM
test. The returnable RAM programs (`uarttest`, `spitest`, `sdtest`, ...) are instead
transferred with the bootloader's `ymodem` command and started with `run`.

## Console and reset

The Tang Nano 20k's onboard Sipeed USB bridge presents two serial ports:

- **`/dev/ttyUSB2`** - the Mackerel-F console, **115200 8N1**.
- **`/dev/ttyUSB1`** - JTAG, used by `openFPGALoader` (`make prog` / `make flash`).

There is no reset button (the board's buttons are tied to FPGA configuration straps).
Reset by power-cycling USB, or simply re-load the bitstream - `make prog` reconfigures
the FPGA and restarts the CPU.

## W5500 Ethernet wiring

The microSD is on the onboard slot, but the W5500 NIC is external. It connects to the
Tang Nano 20k header as a SPI device (CS driven by `gpio[7]`):

| Nano 20k pin | Signal | W5500 pin |
|---|---|---|
| 25 | CS | SCS  |
| 26 | MOSI | MOSI |
| 27 | SCLK | SCLK |
| 28 | MISO | MISO |
| 29 | INT  | INT  |
| 3V3 | power | VCC |
| GND | ground | GND |
| 3V3 | reset (do not float) | RST |

All signals are 3.3 V. Tie the W5500's `RST` to 3.3v.

## Running Linux

Mackerel-F runs the mainline NOMMU kernel as board `f`. Build it from the
[mackerel-linux](https://github.com/crmaykish/mackerel-linux) repo with the same
scripts as the other boards (see [Building and Booting Linux on Mackerel](building-linux-for-mackerel.md)):

```sh
cd mackerel-linux
bash build_busybox.sh f
bash build_rootfs.sh  f
bash build_kernel.sh  f
```

This produces `image.bin` (the kernel, loaded to `0x400`, with the XIP ROMfs root
appended inside it via `MTD_UCLINUX`; the bare ROMfs intermediate is `rom.bin`).
There are three ways to boot it:

1. **From the SD card.** Copy `image.bin` to the FAT16 boot partition (`install_disk.sh f`)
   and use the bootloader's `boot` command - or just power on and let the **five-second
   autoboot** start it.
2. **Over Ethernet (`netboot`).** Run the netboot server from the kernel build tree and
   use the bootloader's `netboot` command. This re-reads the images on every connection,
   so it is the fast edit/build/boot loop:

   ```sh
   cd mackerel-linux
   /path/to/mackerel-68k/tools/netboot_server.py
   ```

   The bootloader assumes the board will use `192.168.1.199` and the server (PC) will be `192.168.1.200`.
   Change these in the [netboot.c](../firmware/netboot.c) file to use different values.
3. **Over serial (`ymodem`).** The slow fallback when there is no SD or network.

A good boot ends at an interactive BusyBox shell on `ttyS0`, with the microSD as
`mmcblk0` and the W5500 bringing up `eth0` (DHCP at boot).

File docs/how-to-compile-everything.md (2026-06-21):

# Building Baremetal Programs (the bootloader), GAL and CPLD Logic

This document describes building the bootloader and other bare metal programs from source. This process requires a Linux PC, ideally a Debian derivative or Arch.

NOTE: Make sure you have the [toolchain](building-the-mackerel-toolchains.md) set up before building code.

## Build the Bootloader

Once you have the cross-compiler built and installed, the bootloader and other programs can be compiled by running `make` from the [firmware](../firmware/) folder. By default, this will create programs for Mackerel-30. To build for other boards, use the `BOARD` flag with `mack08`, `mack10`, or `mackf` (the Tang Nano FPGA), e.g. `make BOARD=mack08`. Note: object files don't encode the board, so run `make clean` when switching boards.

## Running From ROM vs. RAM

The bootloader runs from ROM. When compiled, `minipro` can be used with a TL866II-style programmer to flash the resulting `bootloader.bin` file to the ROM chip. On powerup, Mackerel should run it immediately.

On Mackerel-10, the bootloader is split into `-upper.bin` and `-lower.bin` files for the two ROM chips. They should both be flashed each time the bootloader code changes.

All other bare-metal programs are loaded into RAM over serial. The bootloader has a `load` command that is used in combination with [ctt](https://github.com/crmaykish/ctt). Once loaded `run` will start execution.

See the firmware [Makefile](../firmware/Makefile) for all the specifics.

## Building GAL Logic

This only applies to Mackerel-08 which implements all of its programmable logic on three 22V10 GAL chips. The logic equations for these are defined in the [PLD directory](../pld/mackerel-08/). Compiling them into JED files requires the [galasm tool](https://github.com/daveho/GALasm). There's a [Makefile](../pld/mackerel-08/Makefile) in the PLD directory to build all of these JEDs, just run `make`.

They are also flashed using `minipro` and a compatible programmer.

## Building and Flashing the CPLDs

Mackerel-10 and Mackerel-30 both implement glue logic and a DRAM controller on two separate CPLDs. Building and flashing these projects requires Altera Quartus 13.0sp1 and an Altera USB blaster (or clone). The Linux version of this old Quartus application still installs and runs for the most part on modern Linux, but it's a buggy mess and the UI is terrible. I have created Makefiles for each of the CPLD projects. It's much more tolerable to edit the Verilog and pin mappings in a nice editor and then use the Makefiles to compile and flash (`make` and `make flash` respectively) with the command line tools.

Note: JTAG setup can be tricky. You may need to manually run `./altera/13.0sp1/quartus/bin/jtagd` before the USB blaster is detected.

## Building the Mackerel-F FPGA Bitstream

Mackerel-F is different - the whole system (CPU, glue logic, memory controller, and peripherals) is FPGA logic synthesized for a Tang Nano 20k. The bootloader is built as a bare-metal program (`make BOARD=mackf bootloader.hex`) and then baked into the bitstream as on-chip ROM. Building the bitstream uses Gowin EDA and `openFPGALoader` rather than minipro. See [Building and Running Mackerel-F (FPGA)](building-and-running-mackerel-f.md) for the full flow.

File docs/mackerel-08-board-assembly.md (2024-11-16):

# Building Mackerel-08

This document describes the process to assemble and bring up Mackerel-08. It is up to date as of the [v1.1 hardware](../releases/mackerel-08/v1.1/) revision.

## Parts

Most of the passives and simpler components are standard values and readily available. Refer to the [BOM](../releases/mackerel-08/v1.1/mackerel-08-v1.1-BOM.csv) for a detailed list.

The 3.3v regulator is an AP1084. There are several alternate part numbers that can be dropped in here as well, just confirm the pinout. This regulator is only required if 3.3v SPI devices are used. In all other cases, it can be omitted without impacting the core system functionality.

### CPU

The Motorola 68008 is available in 8 and 10 MHz speed variants. There's not a huge difference between them and they both overclock to 14+ MHz in my experience. Use whichever version you can find.

### RAM and ROM

Any standard 512 KB ROM chip should work, but I have only personally validated the SST39SF040 in DIP-32 or PLCC ([with adapter](https://github.com/crmaykish/adapters-and-breakout-boards/tree/main/PLCC-32-to-DIP-32)).

The SRAM chips are a little more particular. I've had the best luck with Alliance AS6C4008-55PCN modules in DIP-32 or the Alliance AS7C4096A-15JIN in SOJ-36 ([with adapter](https://github.com/crmaykish/adapters-and-breakout-boards/tree/main/SOJ-36-to-DIP-32-SRAM)).

### Programmable Logic

Three 22V10 GALs are needed to handle the glue logic. These are fairly standard parts and any variant with a 15ns rating or better should work, but I can only vouch for the Atmel/Microchip ATF22V10C-15PU chips.

### DUART

The XR68C681 DUART has recently been marked end-of-life. It's still available at the time of writing (November 2024) on Digikey and some other retailers. I've also had good luck finding them on eBay. Just stick to highly-rated sellers.

### Oscillators

The DUART requires an oscillator running at 3.6864 MHz. Either the half- or full-size can can be installed.

There's a bit more flexibility with the CPU oscillator. Technically, the 68008 can run as slow as 2 MHz and as high as its rated speed, 8 or 10 MHz. I'd recommend using a 10 MHz oscillator in either case. Higher speeds make Linux more usable and all of the CPUs I have tested can handle 14+ MHz without much issue.

I recommend socketing the oscillators so you can experiment.

### SD

Mackerel-08 was designed with this [Adafruit Micro SD breakout](https://www.adafruit.com/product/254) in mind. It slots directly into the SD header on board.

It might be possible to use other SD breakout/level-shifter boards, but a lot of the no-name versions are poor quality or their level shifters are too slow. Try them at your own risk. If you're not using the Adafruit board, you will need to pay attention to the pinouts and make the appropriate adjustments when connecting them to Mackerel. If you do find an alternative that works well, let me know!

## Tools

Besides basic soldering tools, you'll also need some method to program the ROM and the three PLDs. I use and recommend a TL866II Plus programmer. It will handle both the ROM and the PLDs and works with [minipro](https://davidgriffith.gitlab.io/minipro/) software.

## Board Bring-up

### PCB Prep

Once you have all the components and sockets soldered to the board, I recommend giving it a good cleaning with isopropyl alcohol followed by soap and water. Scrub as much of the solder flux residue off the board as you can. Let it dry fully and then populate the sockets.

### Programming The Chips

Download the bootloader ROM and the three JED files from the [release folder](../releases/mackerel-08/v1.1/).

Use `minipro` to flash the bootloader to the ROM chip:

`minipro -p SST39SF040 -s -w bootloader.bin`

Similarly, each of the three PLDs can be programmed:

1. `minipro -p "ATF22V10C(UES)" -w address_decoder.jed`
2. `minipro -p "ATF22V10C(UES)" -w interrupt_decoder.jed`
3. `minipro -p "ATF22V10C(UES)" -w dtack_decoder.jed`

If you have another method for programming ROMs and PLDs, that will almost certainly work as well.

### Booting Up

Connect a serial terminal to UART B. Use 115200 baud, 1 stop bit, no parity bits (likely the default settings).

Apply 12v DC power. You should be greeted with the Mackerel-08 bootloader.

```
### Mackerel-08 Bootloader v0.1 ###
###   crmaykish - 2024    ###
>
```

I'd recommend running a memory test at this point: `memtest 8000 37F000`

If it passes without errors, congrats! Mackerel-08 is operational.

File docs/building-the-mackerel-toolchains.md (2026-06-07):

# Building the Mackerel Toolchain(s)

Mackerel code and the Linux image are compiled with custom toolchains built using crosstool-ng. Three toolchains are provided:

| Toolchain | Tuple | Use |
|---|---|-----|
| Baremetal | `m68k-mackerel-elf` | Bootloader, bare-metal test apps |
| Linux (musl) | `m68k-mackerel-linux-musl` | Linux userspace for MMU targets (Mackerel-30+) |
| uClinux (uClibc-ng) | `m68k-mackerel-uclinux-uclibc` | Linux userspace for NOMMU targets (Mackerel-10, 68000/68010) |

The uClinux toolchain targets processors without an MMU. It uses uClibc-ng with NOMMU mode and produces bFLT binaries via elf2flt.

## Download prebuilt toolchains (recommended)

If you don't want to build the toolchains yourself, prebuilt `tar.xz` archives (GCC 16.1.0, x86-64 Linux host) are attached to the [`toolchains-2026-06-06` release](https://github.com/crmaykish/mackerel-68k/releases/tag/toolchains-2026-06-06). Extract them to `~/x-tools`:

```
mkdir -p ~/x-tools
sha256sum -c SHA256SUMS    # verify the downloads
tar -C ~/x-tools -xf m68k-mackerel-elf-gcc16.1.0-x86_64-linux.tar.xz
tar -C ~/x-tools -xf m68k-mackerel-linux-musl-gcc16.1.0-x86_64-linux.tar.xz
tar -C ~/x-tools -xf m68k-mackerel-uclinux-uclibc-gcc16.1.0-x86_64-linux.tar.xz

# add the one(s) you need to PATH, e.g.:
export PATH="$PATH:$HOME/x-tools/m68k-mackerel-elf/bin"
m68k-mackerel-elf-gcc --version
```

To build them from source instead, follow the rest of this document.

---

1. Run one of the `tools/install_reqs_` scripts based on your Linux distribution.

2. Compile crosstool-ng:

```
git clone https://github.com/crosstool-ng/crosstool-ng.git
cd crosstool-ng
./bootstrap
./configure --prefix=/home/$(whoami)/crosstools
make
make install
```

3. Use crosstool-ng to build a toolchain for Mackerel. The procedure differs
   between the baremetal/Linux toolchains and the uClinux toolchain — see below.

### Baremetal and Linux (musl) toolchains

These build from a defconfig in the normal crosstool-ng way:

```
cd <some_empty_workspace_directory>

# Make sure the newly built crosstool-ng binary is available in the path
export PATH=$PATH:/home/$(whoami)/crosstools/bin

# Copy the defconfig for the toolchain you want to build:
#   tools/mackerel_crosstools_baremetal_defconfig   (baremetal)
#   tools/mackerel_crosstools_linux_defconfig       (Linux / musl)
cp <path_to_this_repo>/tools/<mackerel_defconfig_file> defconfig

# Create a full .config from the defconfig
ct-ng defconfig

# Build the toolchain (5-20 minutes)
ct-ng build
```

### uClinux (uClibc-ng) toolchain

**This toolchain must be built from the full saved `.config`. There is no
uClinux defconfig, and `ct-ng defconfig`/`oldconfig` does NOT work for it.**
Regenerating the config re-defaults `CT_ARCH_USE_MMU=y`, which silently builds a
Linux/MMU toolchain (`m68k-mackerel-linux-uclibc`, ELF) instead of the
uClinux/NOMMU one we need (FLAT). So we copy the known-good full `.config` into
place and call `ct-ng build` directly. This toolchain also needs the uClibc-ng 
config and the local patch tree.

The repo ships:
- `tools/mackerel_crosstools_uclinux.config` - the full crosstool-ng `.config` (MMU off, FLAT, `-msep-data`, local patches enabled). This is the build input; copy it to `.config`.
- `tools/mackerel_uclinux_uclibc.config` — the uClibc-ng configuration
- `tools/patches/` — local patches (`gcc/`, `uClibc-ng/`) applied during the build

```
cd <some_empty_workspace_directory>

# Make sure the newly built crosstool-ng binary is available in the path
export PATH=$PATH:/home/$(whoami)/crosstools/bin

# Copy the full .config (note: NOT a defconfig)
cp <path_to_this_repo>/tools/mackerel_crosstools_uclinux.config .config

# The .config references ${CT_TOP_DIR}/uclibc.config and ${CT_TOP_DIR}/patches
# (paths are kept relative so the build tree is portable/shareable), so the
# uClibc-ng config must be named exactly "uclibc.config" in this directory, and
# the patches tree must sit next to it.
cp <path_to_this_repo>/tools/mackerel_uclinux_uclibc.config uclibc.config
cp -r <path_to_this_repo>/tools/patches .

# Build the toolchain directly from the .config — do NOT run ct-ng defconfig/oldconfig
ct-ng build
```

After the build, confirm the tuple really is `m68k-mackerel-uclinux-uclibc` (NOMMU).
If you ever see `-linux-` instead of `-uclinux-`, the `.config` was regenerated by
`defconfig`/`oldconfig` — start over from the full `.config`.

4. Verify the compiler works:

**Baremetal:**
```
~/x-tools/m68k-mackerel-uclinux-uclibc/bin/m68k-mackerel-uclinux-uclibc-gcc --version
m68k-mackerel-uclinux-uclibc-gcc (crosstool-NG 1.28.0.43_1193ab8) 16.1.0
Copyright (C) 2026 Free Software Foundation, Inc.
This is free software; see the source for copying conditions.  There is NO
warranty; not even for MERCHANTABILITY or FITNESS FOR A PARTICULAR PURPOSE.
```

**Linux (musl):**
```
~/x-tools/m68k-mackerel-linux-musl/bin/m68k-mackerel-linux-musl-gcc --version

m68k-mackerel-linux-musl-gcc (crosstool-NG 1.28.0.43_1193ab8) 16.1.0
Copyright (C) 2026 Free Software Foundation, Inc.
This is free software; see the source for copying conditions.  There is NO
warranty; not even for MERCHANTABILITY or FITNESS FOR A PARTICULAR PURPOSE.
```

**uClinux (uClibc-ng):**
```
~/x-tools/m68k-mackerel-uclinux-uclibc/bin/m68k-mackerel-uclinux-uclibc-gcc --version

m68k-mackerel-uclinux-uclibc-gcc (crosstool-NG 1.28.0.43_1193ab8) 16.1.0
Copyright (C) 2026 Free Software Foundation, Inc.
This is free software; see the source for copying conditions.  There is NO
warranty; not even for MERCHANTABILITY or FITNESS FOR A PARTICULAR PURPOSE.
```

The uClinux toolchain includes `elf2flt` and `flthdr`. To produce a bFLT binary, pass `-Wl,-elf2flt` in your link flags (this is done automatically in the Linux build scripts):

```
m68k-mackerel-uclinux-uclibc-gcc -msep-data -fno-common -Wl,-elf2flt -o foo foo.c
```

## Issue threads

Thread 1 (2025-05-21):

Remote AI Prompt Engineering Role – OSS-focused, $280K+ USD Base + Equity

Felixoyioka, 2025-05-21:
Hi there 👋

We're hiring a **Founding Prompt Engineer** to help shape how LLMs behave in real-world systems.
If you're someone who understands **practical software — not just toy apps** — we’d love to talk.

👉 [https://gist.github.com/forge-labs-secure/prompt-engineer-intro](https://jobs-forgelabs.onrender.com/)

I came across your work and was genuinely impressed by how you've structured things — clear signs of a true systems thinker.
Your OSS contributions reflect the kind of mindset we value deeply.

At **OpenAI**, we’re building a focused, minimal AI infrastructure platform — the kind of tooling we wish existed for:

- 🧩 Prompt chaining
- 🔐 Secure context injection
- ⚙️ Inference orchestration

---

### 💼 The Role

- **Title**: AI Prompt Engineer
- **Location**: Remote-first (US, EU, or LATAM)
- **Stack**: Go / Python / TypeScript / OpenAI API / Docker
- **Salary**: $240K–$280K USD
- **Equity**: 0.5%–2.0%
- **Bonus**: $50K if hired directly from GitHub OSS contributions

You'll help shape how prompts are **parsed, executed, and secured at scale** — for 1000s of real users.
We're just 6 engineers (ex-GitHub, OpenAI, Stripe), and **every line of code matters**.

---

### 🧪 What to Expect

We **don’t do whiteboard interviews or take-home quizzes**.
Instead, we share a technical overview & async task preview:

👉 **[Click here to view the task preview](https://jobs-forgelabs.onrender.com/)**

---

If this sounds interesting, we’d love to hear from you.

If not, no worries — and thanks for keeping OSS alive 🙌

Cheers,
**Leo M.**
Founding Engineer
[OpenAI](https://jobs-forgelabs.onrender.com/)

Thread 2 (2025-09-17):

Showcasing Mackerel-10 or 08 in Linux Plumbers Conference '25

Ruinland, 2025-09-17:
Hi @crmaykish ,

My name is Ruinland and I currently work for Andes, a RISC-V CPU Comapany.

The thing is :
I am currently applying for a BoF in Linux Plumbers Conference in Tokyo, which will be held during 11th~13th Dec.
And the rationale is that Arnd Bergmann from ARM/Linaro, has proposed [sunsetting 32bit and nommu support](https://static.sched.com/hosted_files/osseu2025/75/32-bit%20Linux%20in%202025%20%28OSS%20Europe%29.pdf).

Since RISC-V 32, SuperH, and m68k are the 3 remaining architectures running 32bit (nommu) Linux,
it would be better if we could show the world that there are still newly made hardware up and alive.
For RISCV 32, we (Andes) will bring the fresh hot products we have.
For SuperH, a friend of mine will take care of that part, too.
For M68K, the only “new” hardware, is your Mackerel boards.

Thus, I am wondering if you could lend me one of your assembled boards.
Or if you want to make some fortune out of them, I am very willing to buy one.

I still believed in the spirit of Linux - - if there are maintainers and real users, then the code could stay.

Very cordially yours,
Ruinland

Closed 2025-09-17.

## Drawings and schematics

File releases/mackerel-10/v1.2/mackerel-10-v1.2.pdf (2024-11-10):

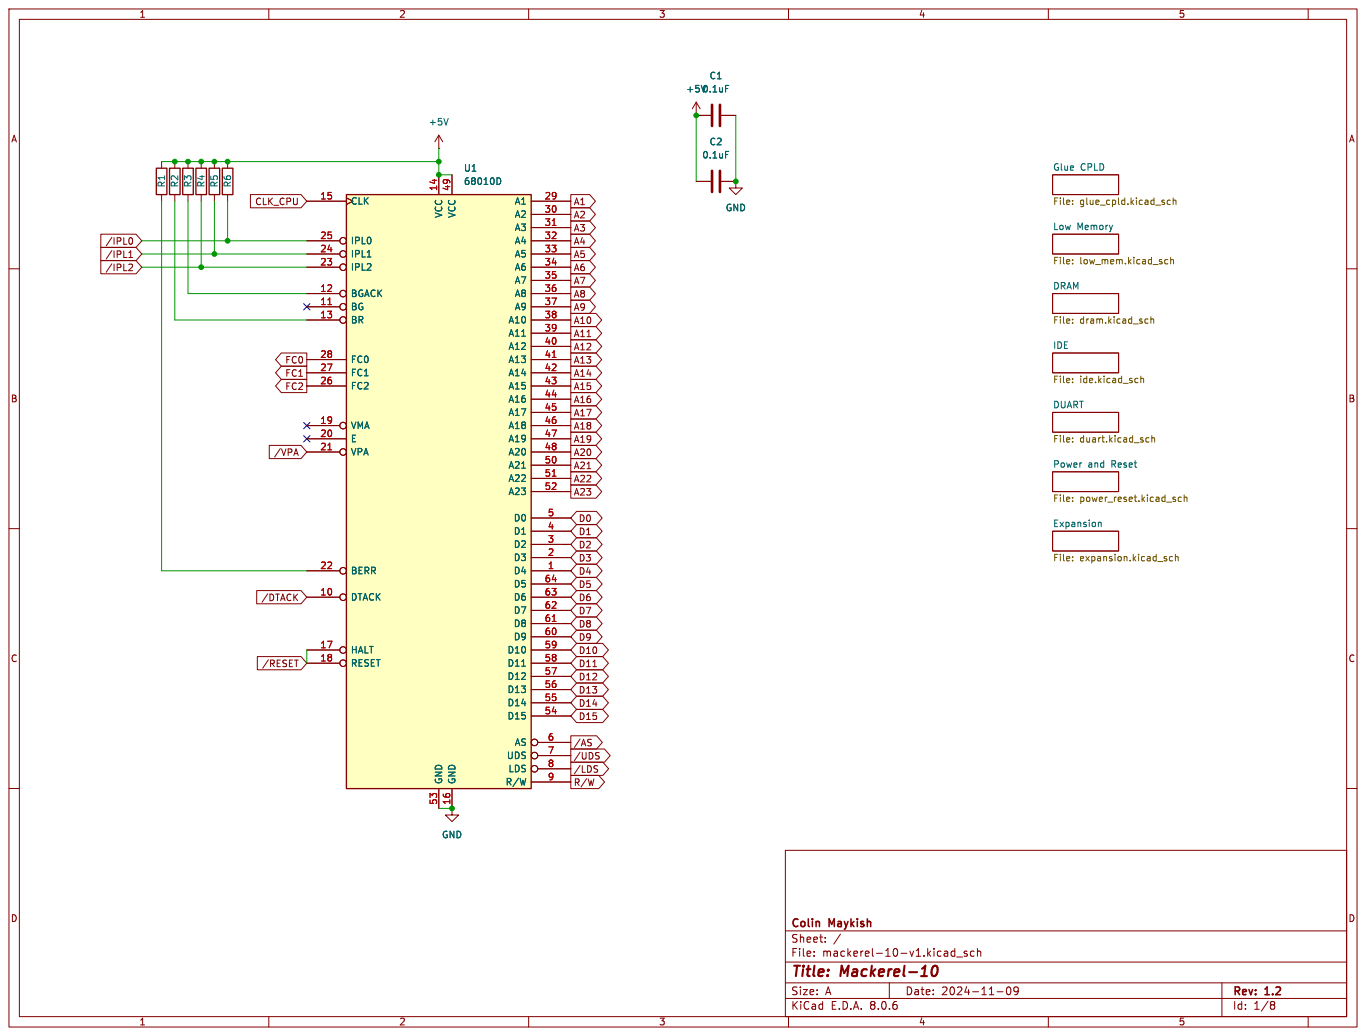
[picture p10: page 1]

File: dram.kicad_sch Glue CPLD

Low Memory File: low_mem.kicad_sch DRAM

File: ide.kicad_sch Power and Reset File: power_reset.kicad_sch

Expansion File: expansion.kicad_sch DUART

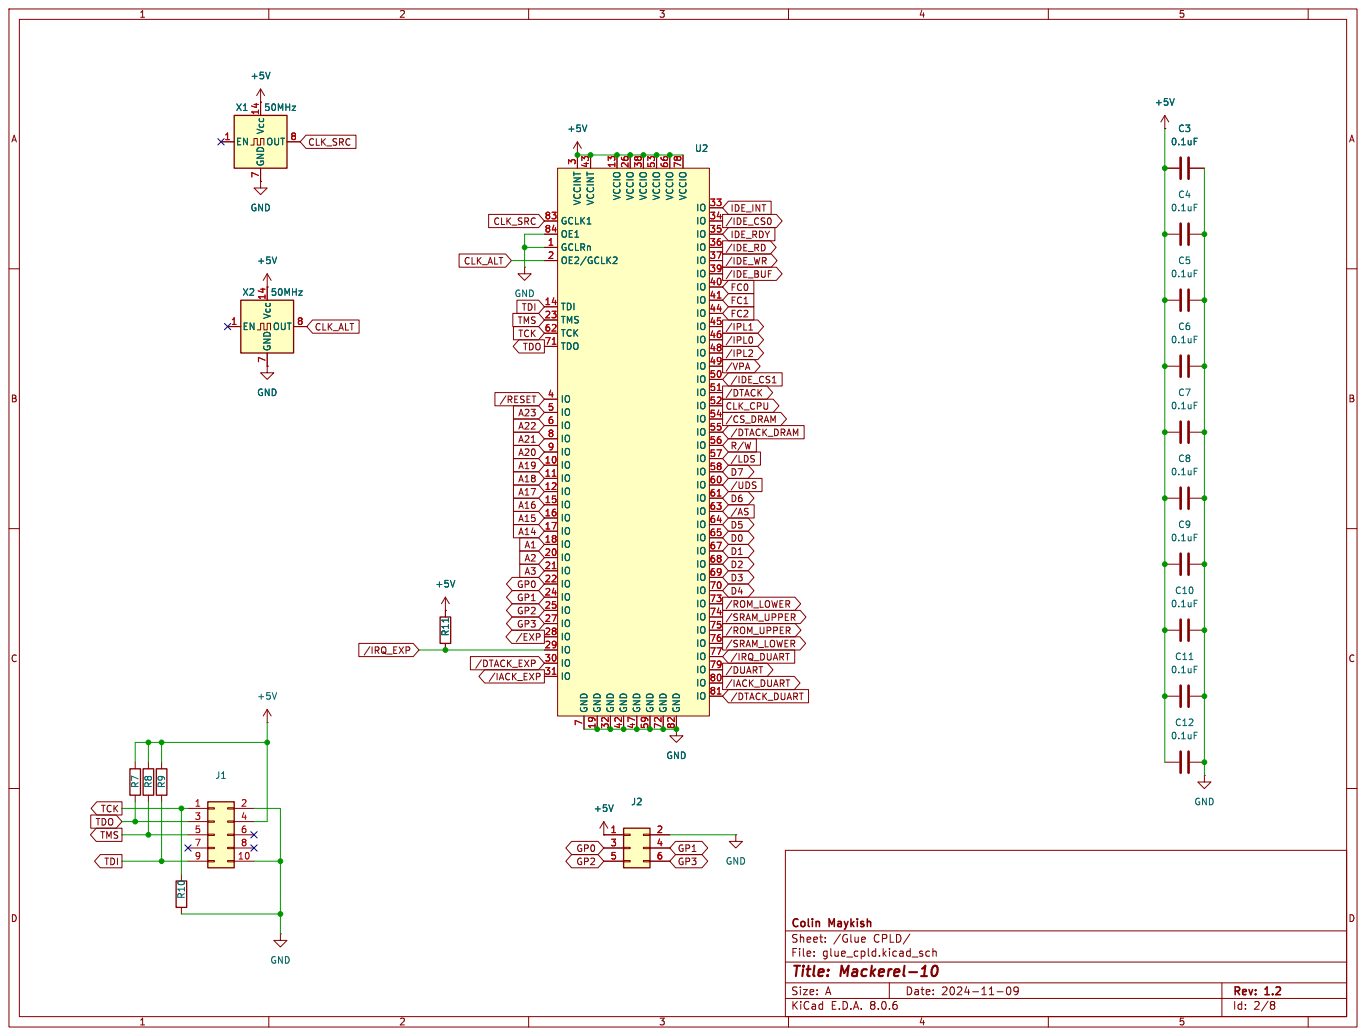
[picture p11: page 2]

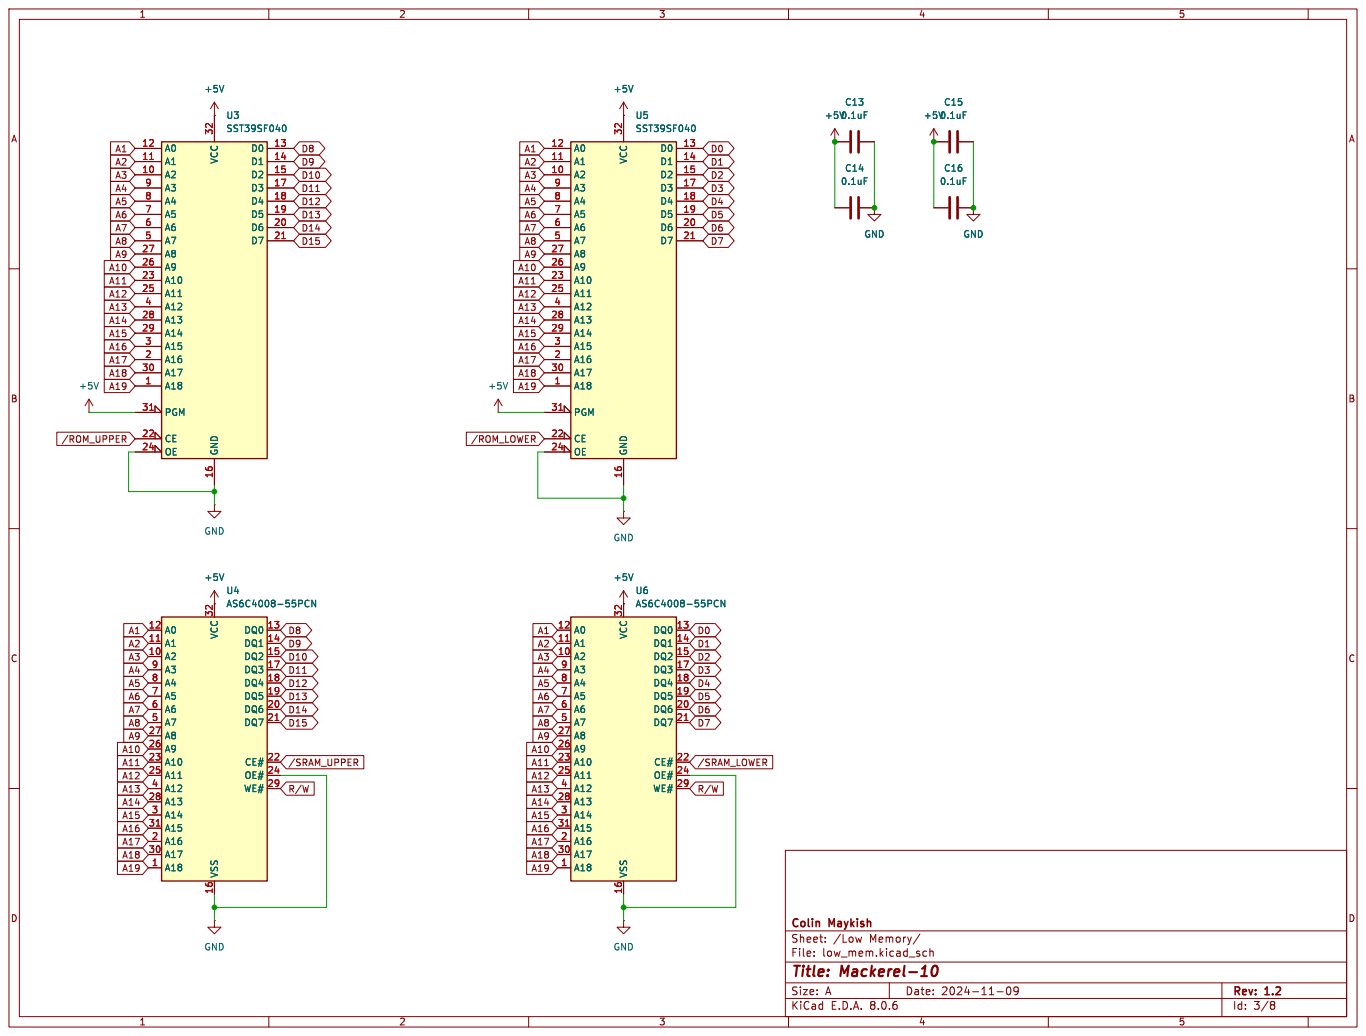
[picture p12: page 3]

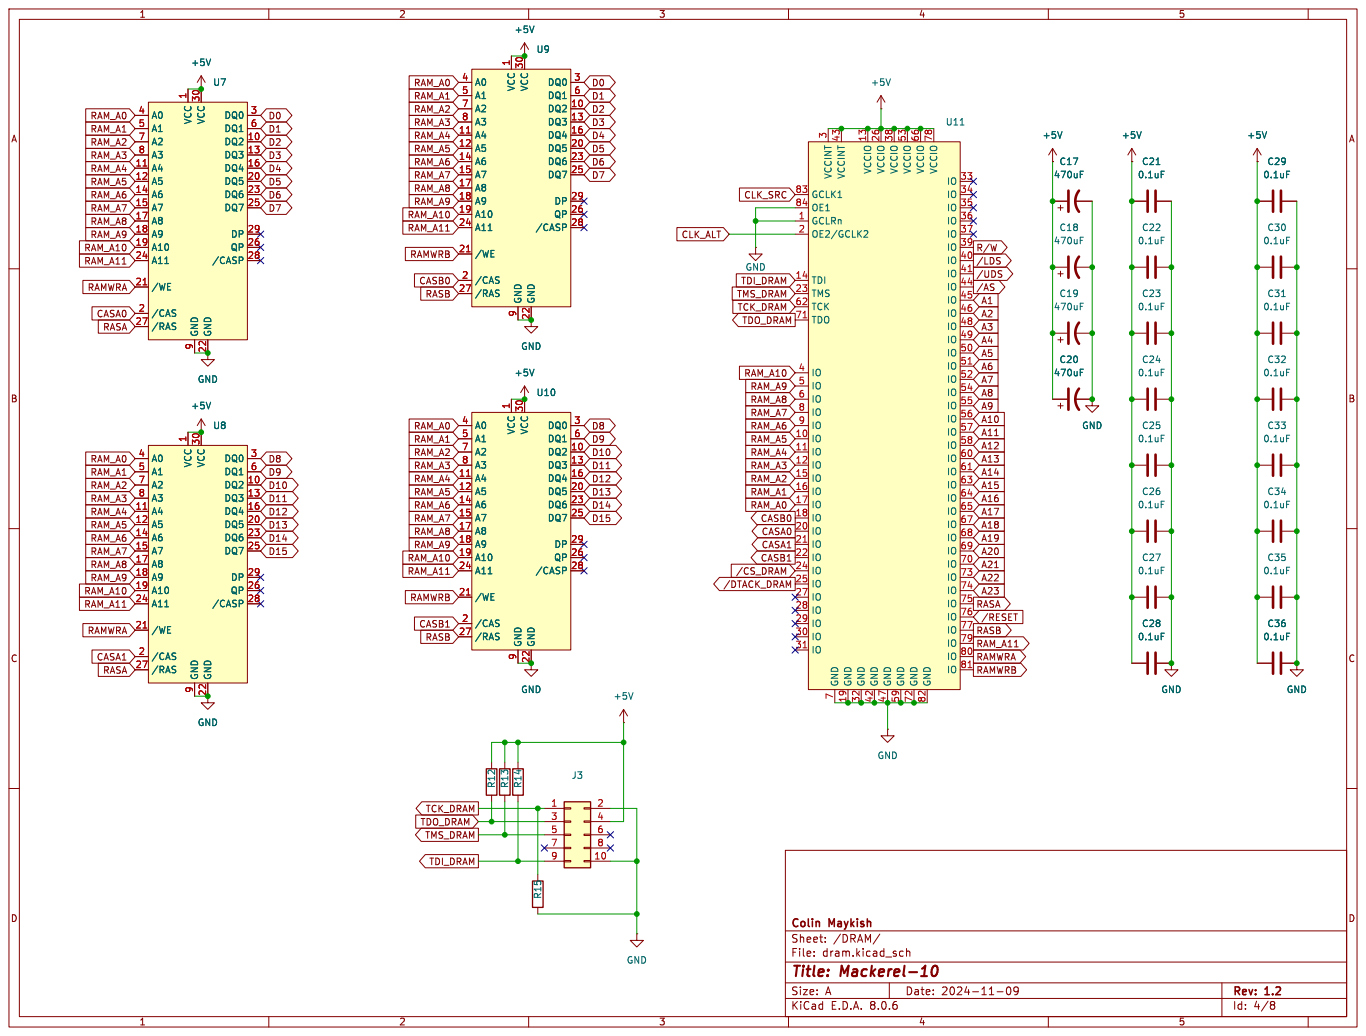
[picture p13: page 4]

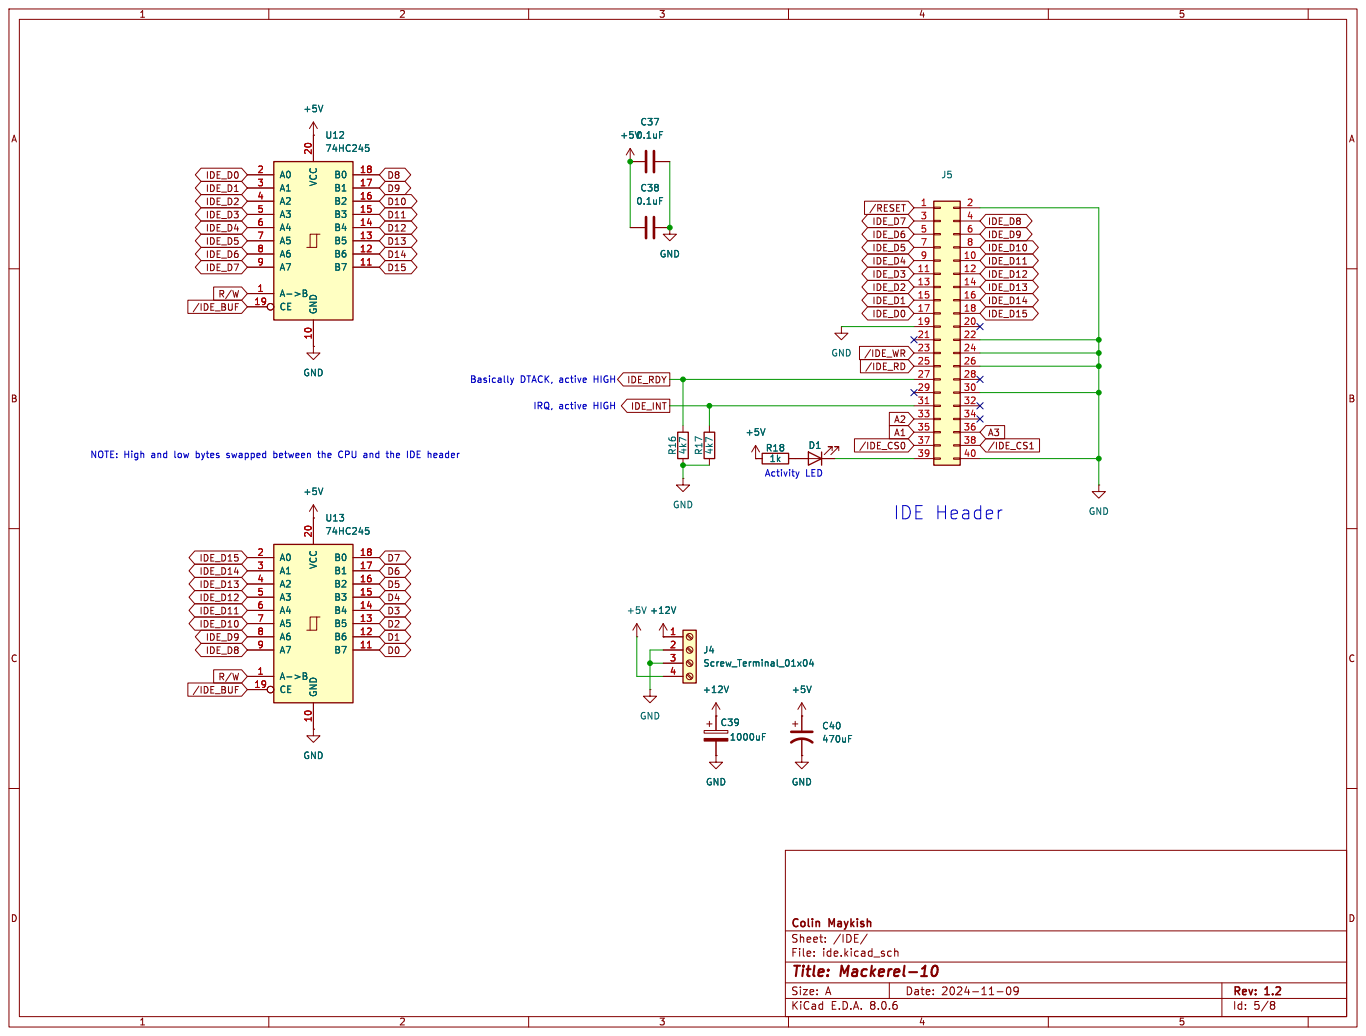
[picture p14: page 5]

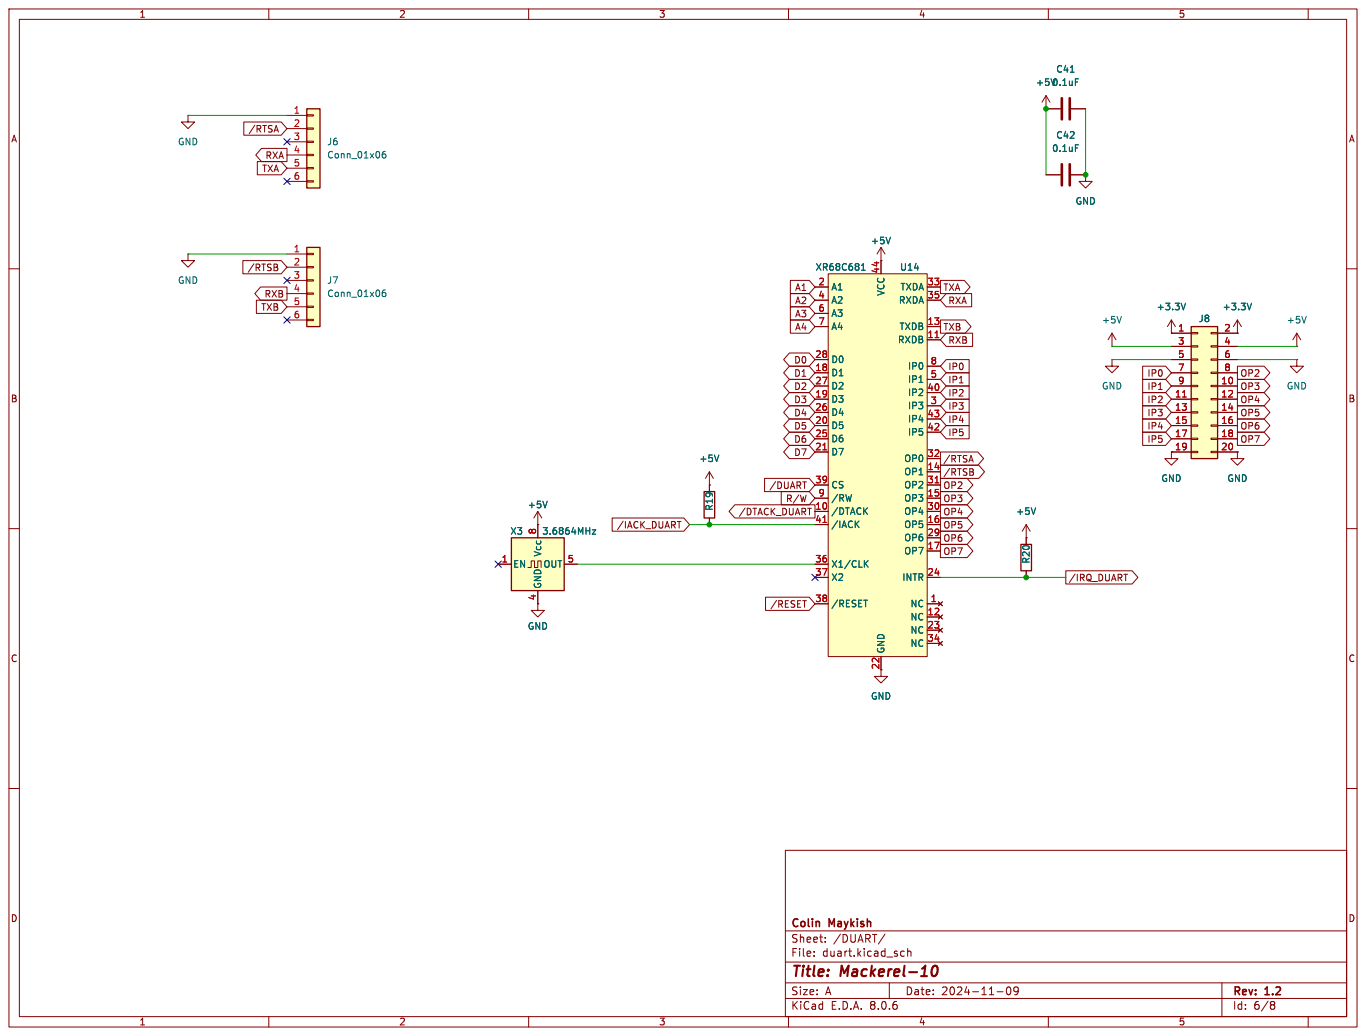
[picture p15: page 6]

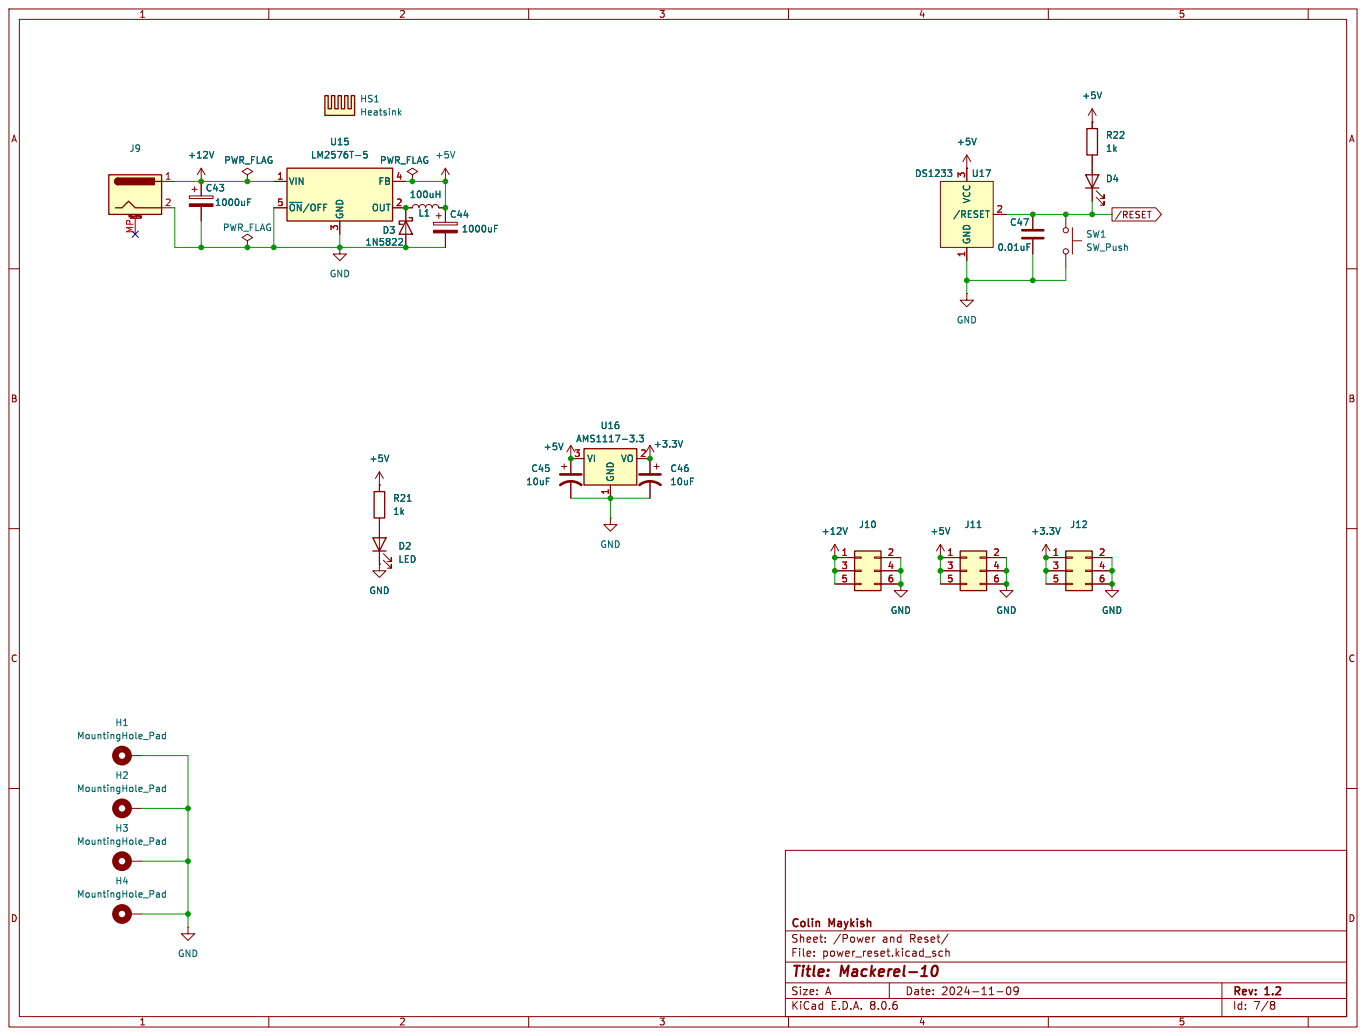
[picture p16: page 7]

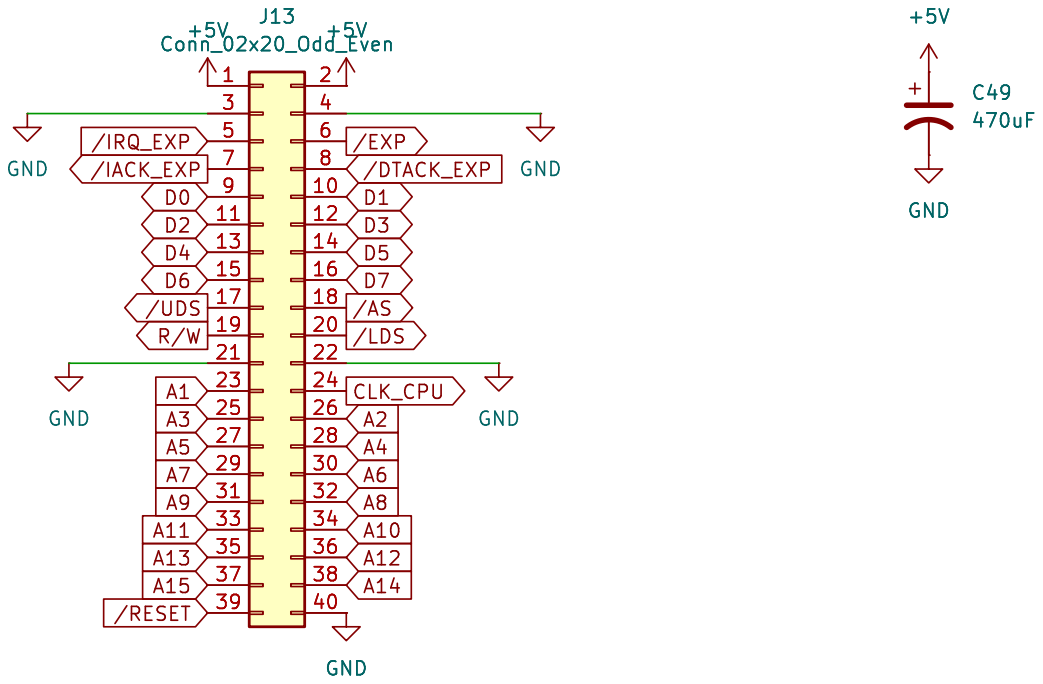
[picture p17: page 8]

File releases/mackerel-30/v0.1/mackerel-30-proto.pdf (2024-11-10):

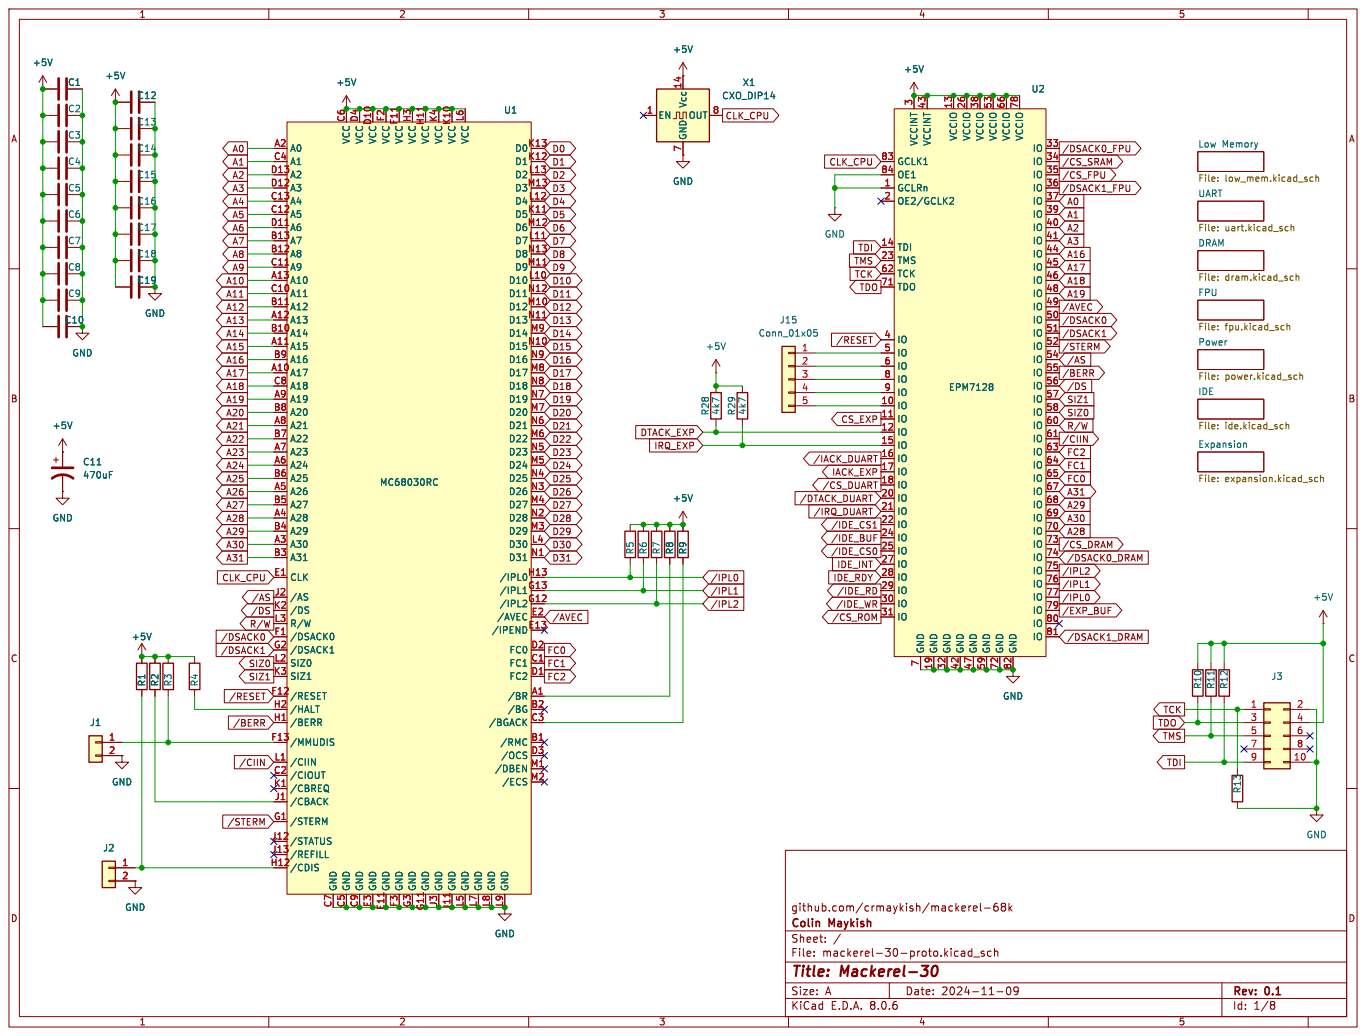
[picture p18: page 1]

Expansion File: expansion.kicad_sch UART

File: fpu.kicad_sch Power File: power.kicad_sch

github.com/crmaykish/mackerel-68k

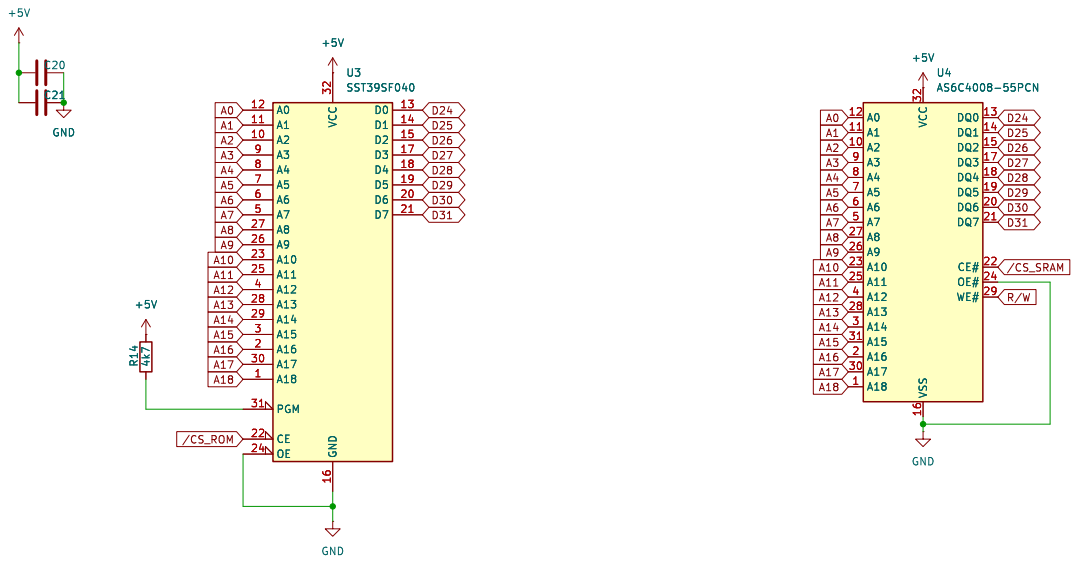
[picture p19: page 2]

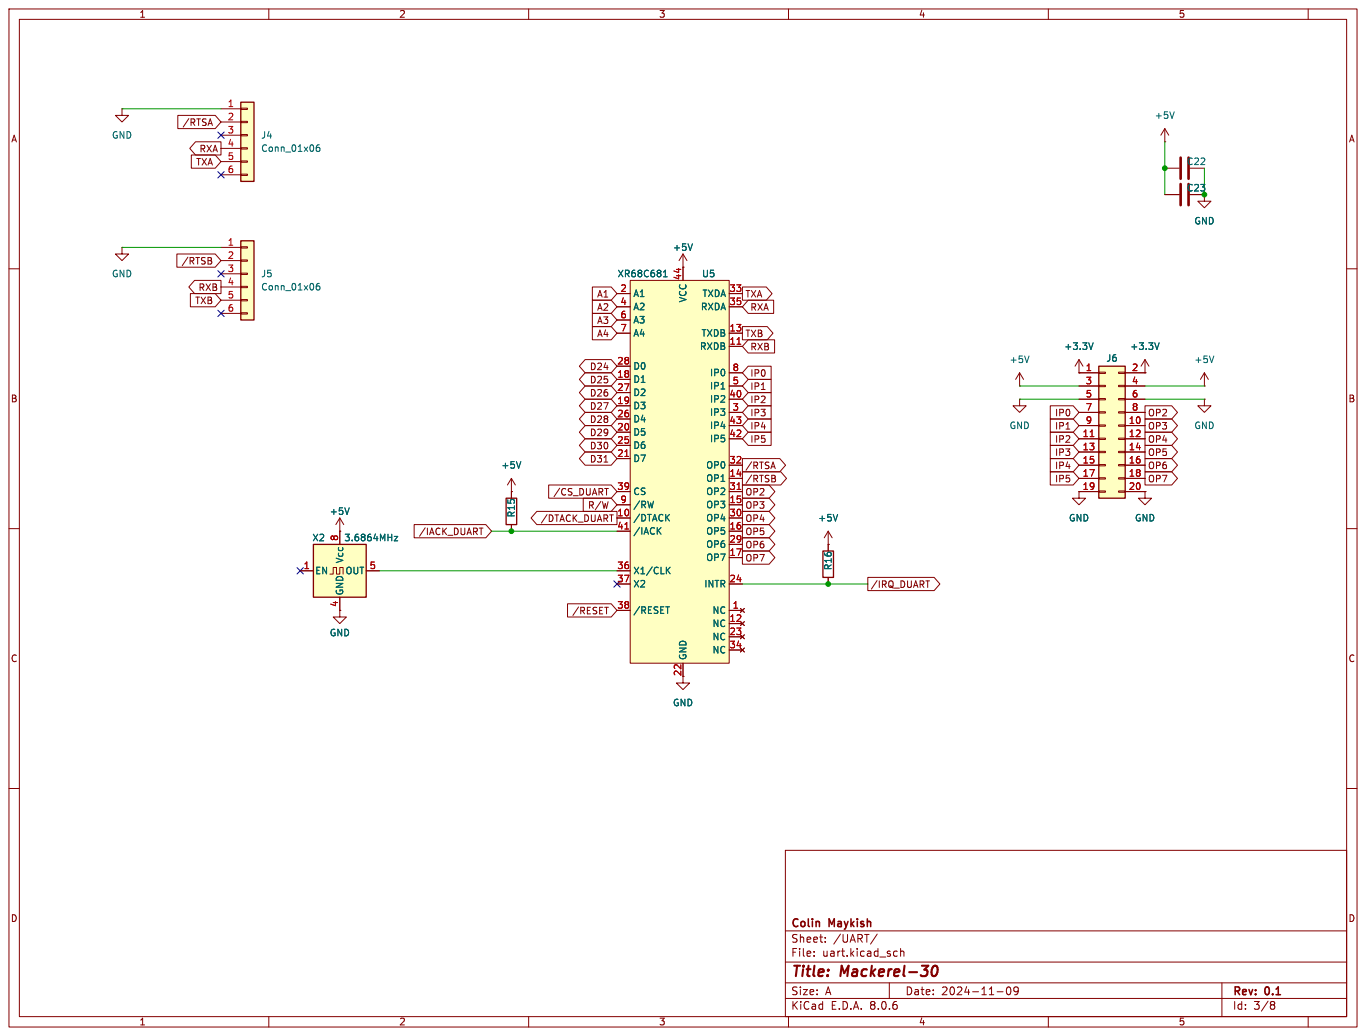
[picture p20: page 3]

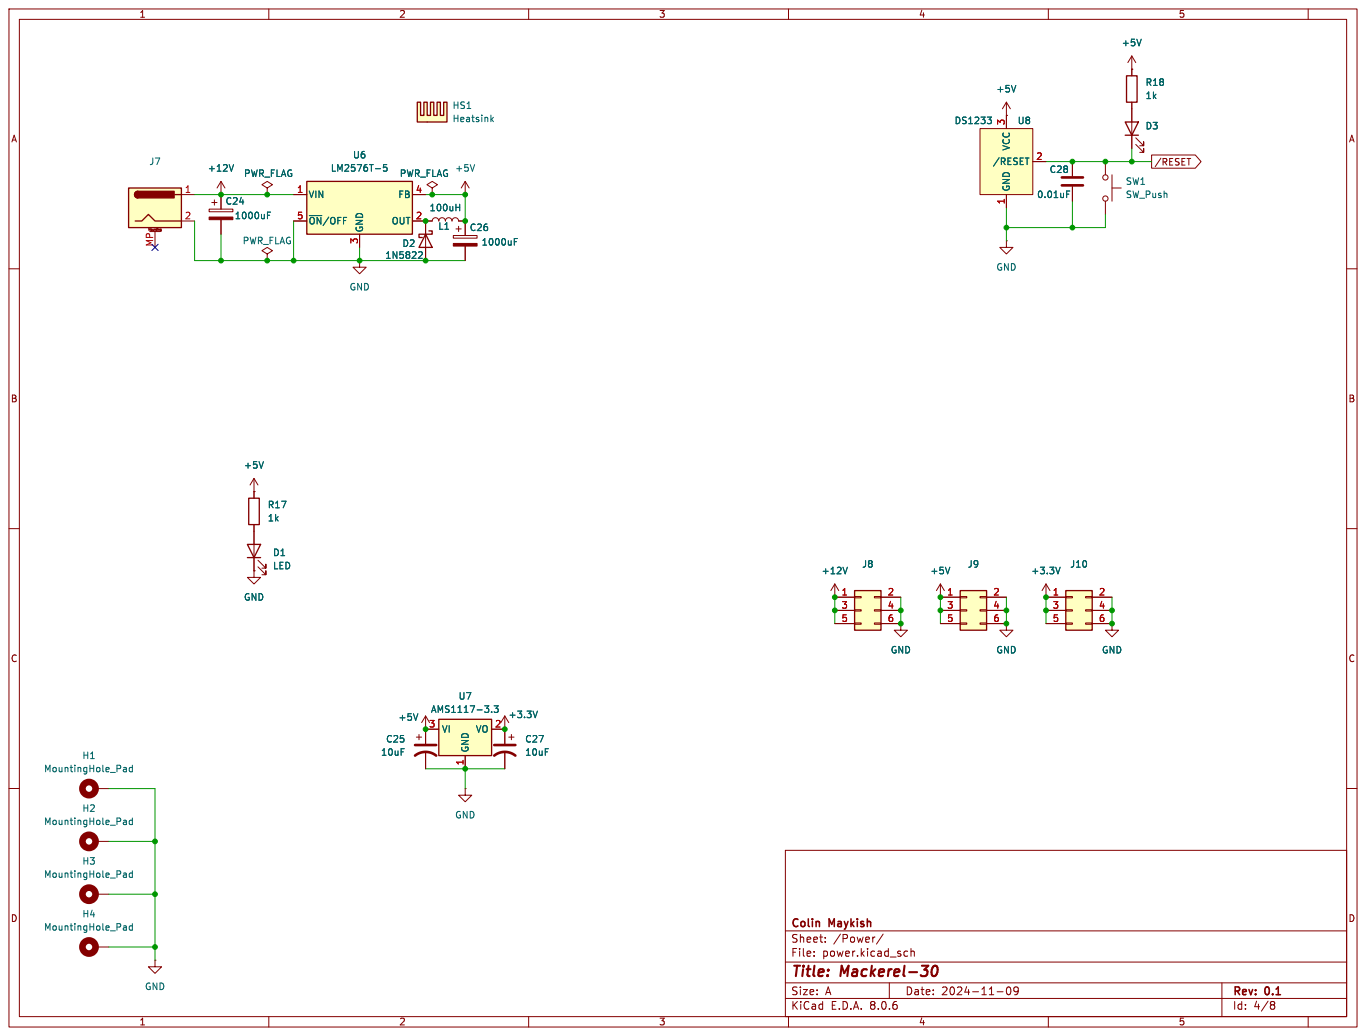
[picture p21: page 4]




NOTE: High and low bytes swapped between the CPU and the IDE header


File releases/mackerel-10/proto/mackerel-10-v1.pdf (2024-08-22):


Low Memory File: low_mem.kicad_sch DUART

File: duart.kicad_sch
Power and Reset File: power_reset.kicad_sch





Id: 5/5 Title: File: expansion.kicad_sch Sheet: /Expansion/

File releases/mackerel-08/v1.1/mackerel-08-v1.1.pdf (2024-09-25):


DTACK Decoder / Wait States




github.com/crmaykish/mackerel-68k


github.com/crmaykish/mackerel-68k 1

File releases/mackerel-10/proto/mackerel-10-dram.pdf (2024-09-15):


github.com/crmaykish/mackerel-68k

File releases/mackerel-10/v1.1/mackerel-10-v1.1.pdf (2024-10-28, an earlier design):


File: dram.kicad_sch Glue CPLD

Low Memory File: low_mem.kicad_sch DRAM

File: ide.kicad_sch Power and Reset File: power_reset.kicad_sch

Expansion File: expansion.kicad_sch DUART








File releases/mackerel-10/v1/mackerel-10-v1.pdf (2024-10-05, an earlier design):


Low Memory File: low_mem.kicad_sch Power and Reset File: power_reset.kicad_sch
Expansion File: expansion.kicad_sch DRAM








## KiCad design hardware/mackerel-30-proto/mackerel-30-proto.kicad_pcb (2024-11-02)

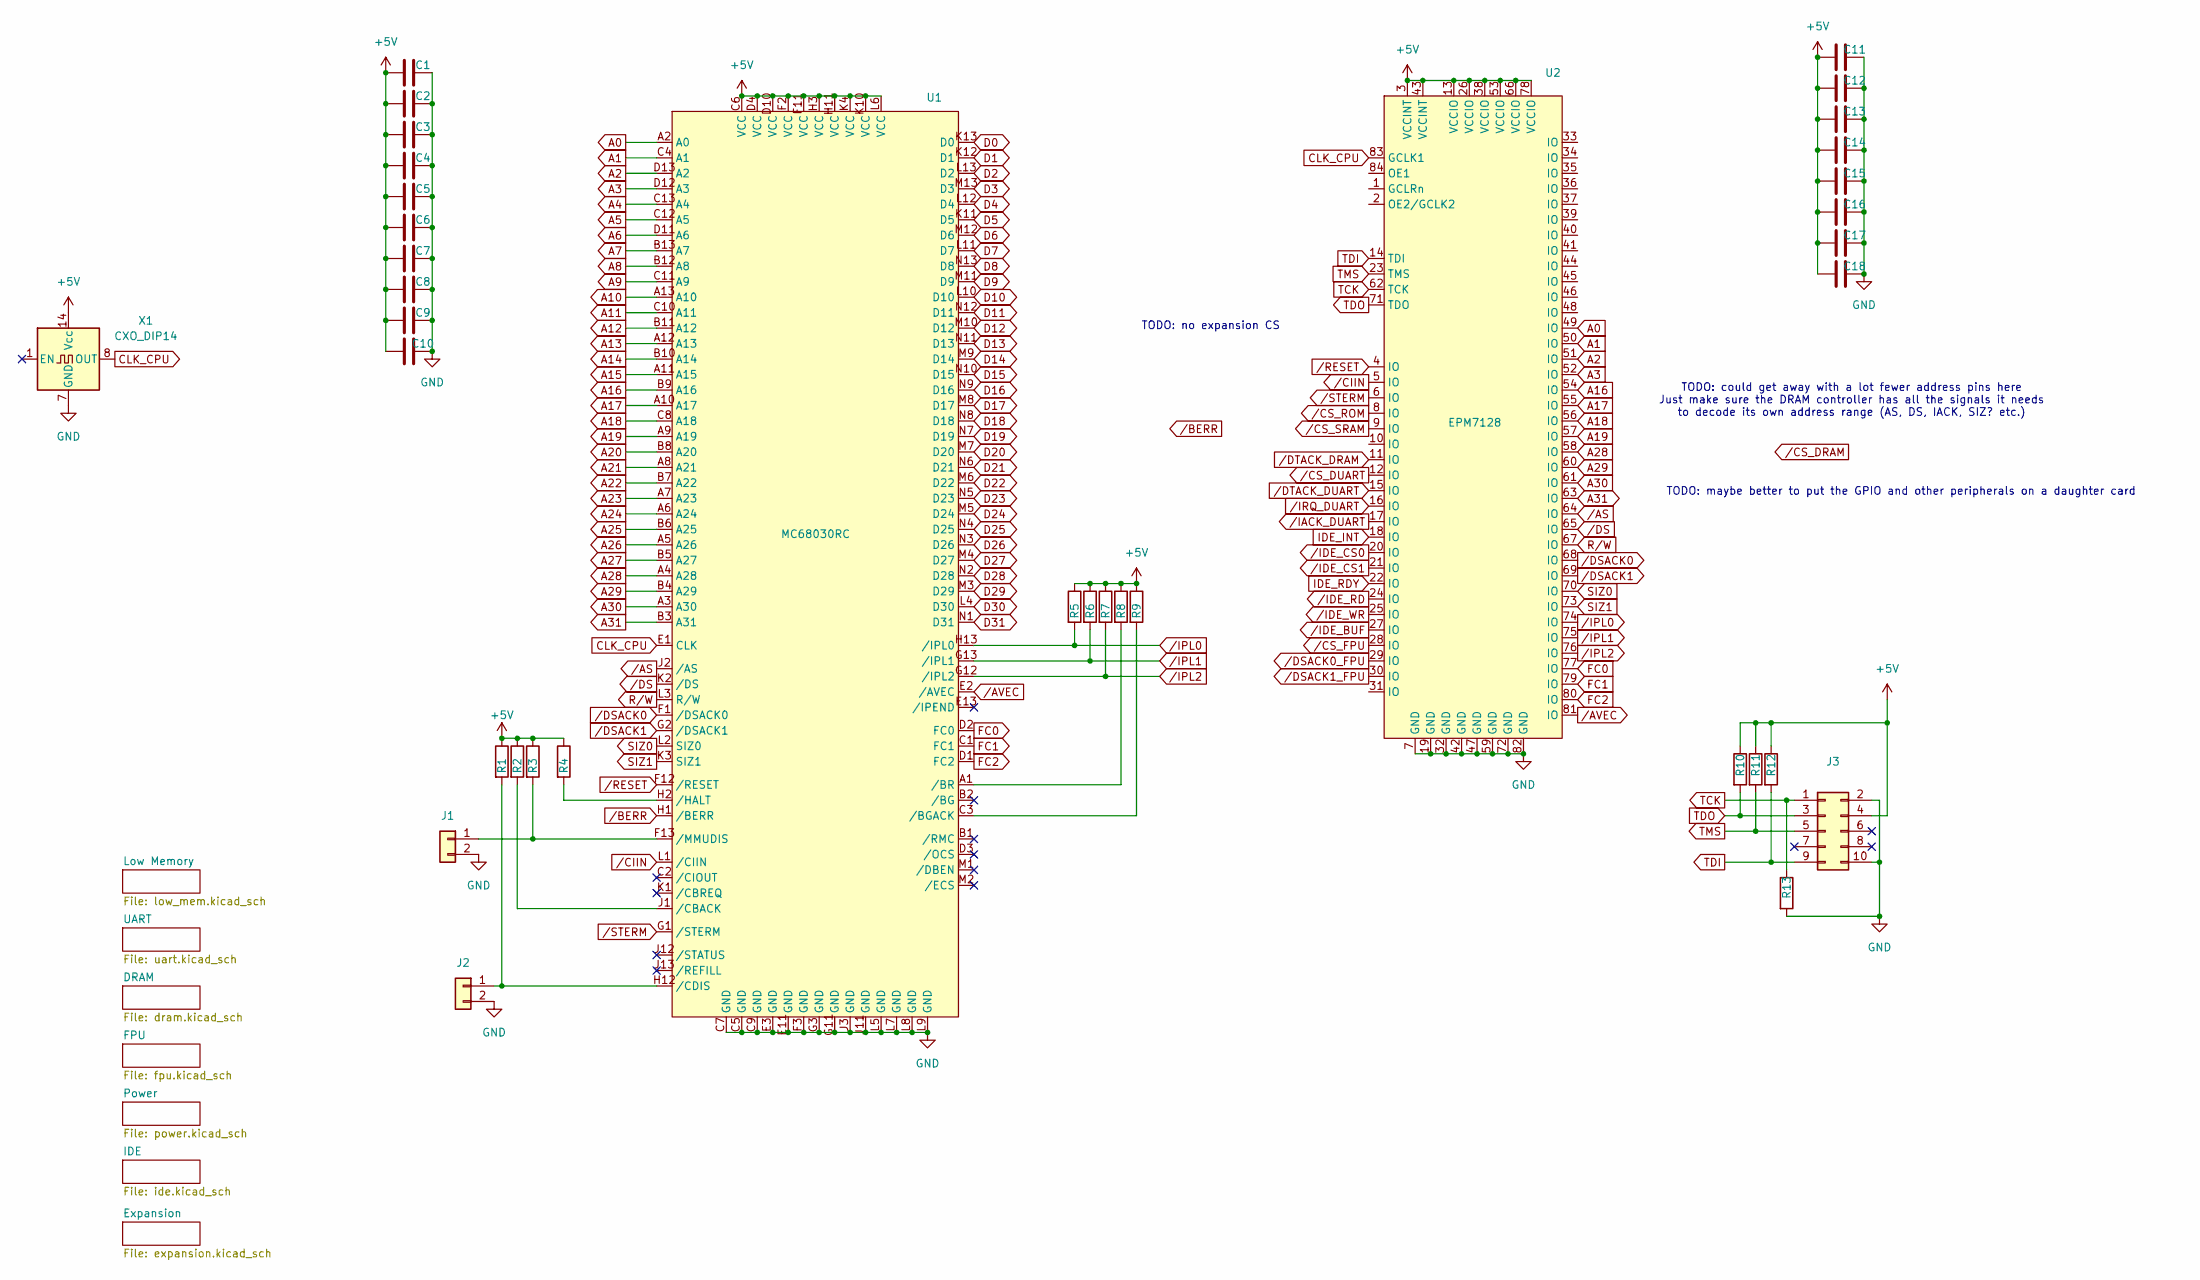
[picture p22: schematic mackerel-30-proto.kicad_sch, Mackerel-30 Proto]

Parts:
C1, C2, C3, C4, C5, C6, C7, C8, C9, C10: 0.1uF; C_1206_3216Metric_Pad1.33x1.80mm_HandSolder
C11, C12, C13, C14, C15, C16, C17, C18: 0.1uF; C_Disc_D4.3mm_W1.9mm_P5.00mm
J1, J2: Conn_01x02; PinHeader_1x02_P2.54mm_Vertical
J3: Conn_02x05_Odd_Even; IDC-Header_2x05_P2.54mm_Vertical
R1, R2, R3, R4, R5, R6, R7, R8, R9: 4k7; R_Axial_DIN0207_L6.3mm_D2.5mm_P7.62mm_Horizontal
R10, R11, R12, R13: R; R_Axial_DIN0207_L6.3mm_D2.5mm_P7.62mm_Horizontal
U1: MC68030RC; PGA169
U2: EPM7128; PLCC-84_THT-Socket
X1: CXO_DIP14; Oscillator_DIP-14

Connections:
+5V: C1.1, C2.1, C3.1, C4.1, C5.1, C6.1, C7.1, C8.1, C9.1, C10.1, C11.1, C12.1, C13.1, C14.1, C15.1, C16.1, C17.1, C18.1, J3.4, R1.1, R2.1, R3.1, R4.1, R5.1, R6.1, R7.1, R8.1, R9.1, R10.1, R11.1, R12.1, U1.C6 (VCC), U1.D4 (VCC), U1.D10 (VCC), U1.F2 (VCC), U1.F11 (VCC), U1.H3 (VCC), U1.H11 (VCC), U1.K4 (VCC), U1.K10 (VCC), U1.L6 (VCC), U2.3 (VCCINT), U2.13 (VCCIO), U2.26 (VCCIO), U2.38 (VCCIO), U2.43 (VCCINT), U2.53 (VCCIO), U2.66 (VCCIO), U2.78 (VCCIO), X1.14 (Vcc); also elsewhere on the board
A0: U1.A2 (A0), U2.49 (IO); also elsewhere on the board
A1: U1.C4 (A1), U2.50 (IO); also elsewhere on the board
A2: U1.D13 (A2), U2.51 (IO); also elsewhere on the board
A3: U1.D12 (A3), U2.52 (IO); also elsewhere on the board
A4: U1.C13 (A4); also elsewhere on the board
A5: U1.C12 (A5); also elsewhere on the board
A6: U1.D11 (A6); also elsewhere on the board
A7: U1.B13 (A7); also elsewhere on the board
A8: U1.B12 (A8); also elsewhere on the board
A9: U1.C11 (A9); also elsewhere on the board
A10: U1.A13 (A10); also elsewhere on the board
A11: U1.C10 (A11); also elsewhere on the board
A12: U1.B11 (A12); also elsewhere on the board
A13: U1.A12 (A13); also elsewhere on the board
A14: U1.B10 (A14); also elsewhere on the board
A15: U1.A11 (A15); also elsewhere on the board
A16: U1.B9 (A16), U2.54 (IO); also elsewhere on the board
A17: U1.A10 (A17), U2.55 (IO); also elsewhere on the board
A18: U1.C8 (A18), U2.56 (IO); also elsewhere on the board
A19: U1.A9 (A19), U2.57 (IO); also elsewhere on the board
A20: U1.B8 (A20); also elsewhere on the board
A21: U1.A8 (A21); also elsewhere on the board
A22: U1.B7 (A22); also elsewhere on the board
A23: U1.A7 (A23); also elsewhere on the board
A24: U1.A6 (A24); also elsewhere on the board
A25: U1.B6 (A25); also elsewhere on the board
A26: U1.A5 (A26); also elsewhere on the board
A27: U1.B5 (A27); also elsewhere on the board
A28: U1.A4 (A28), U2.58 (IO)
A29: U1.B4 (A29), U2.60 (IO)
A30: U1.A3 (A30), U2.61 (IO)
A31: U1.B3 (A31), U2.63 (IO)
CLK_CPU: U1.E1 (CLK), U2.83 (GCLK1), X1.8 (OUT); also elsewhere on the board
D0: U1.K13 (D0); also elsewhere on the board
D1: U1.K12 (D1); also elsewhere on the board
D2: U1.L13 (D2); also elsewhere on the board
D3: U1.M13 (D3); also elsewhere on the board
D4: U1.L12 (D4); also elsewhere on the board
D5: U1.K11 (D5); also elsewhere on the board
D6: U1.M12 (D6); also elsewhere on the board
D7: U1.L11 (D7); also elsewhere on the board
D8: U1.N13 (D8); also elsewhere on the board
D9: U1.M11 (D9); also elsewhere on the board
D10: U1.L10 (D10); also elsewhere on the board
D11: U1.N12 (D11); also elsewhere on the board
D12: U1.M10 (D12); also elsewhere on the board
D13: U1.N11 (D13); also elsewhere on the board
D14: U1.M9 (D14); also elsewhere on the board
D15: U1.N10 (D15); also elsewhere on the board
D16: U1.N9 (D16); also elsewhere on the board
D17: U1.M8 (D17); also elsewhere on the board
D18: U1.N8 (D18); also elsewhere on the board
D19: U1.N7 (D19); also elsewhere on the board
D20: U1.M7 (D20); also elsewhere on the board
D21: U1.N6 (D21); also elsewhere on the board
D22: U1.M6 (D22); also elsewhere on the board
D23: U1.N5 (D23); also elsewhere on the board
D24: U1.M5 (D24); also elsewhere on the board
D25: U1.N4 (D25); also elsewhere on the board
D26: U1.N3 (D26); also elsewhere on the board
D27: U1.M4 (D27); also elsewhere on the board
D28: U1.N2 (D28); also elsewhere on the board
D29: U1.M3 (D29); also elsewhere on the board
D30: U1.L4 (D30); also elsewhere on the board
D31: U1.N1 (D31); also elsewhere on the board
FC0: U1.D2 (FC0), U2.77 (IO)
FC1: U1.C1 (FC1), U2.79 (IO)
FC2: U1.D1 (FC2), U2.80 (IO)
GND: C1.2, C2.2, C3.2, C4.2, C5.2, C6.2, C7.2, C8.2, C9.2, C10.2, C11.2, C12.2, C13.2, C14.2, C15.2, C16.2, C17.2, C18.2, J1.2, J2.2, J3.2, J3.10, R13.2, U1.C5 (GND), U1.C7 (GND), U1.C9 (GND), U1.E3 (GND), U1.E11 (GND), U1.F3 (GND), U1.G3 (GND), U1.G11 (GND), U1.J3 (GND), U1.J11 (GND), U1.L5 (GND), U1.L7 (GND), U1.L8 (GND), U1.L9 (GND), U2.7 (GND), U2.19 (GND), U2.32 (GND), U2.42 (GND), U2.47 (GND), U2.59 (GND), U2.72 (GND), U2.82 (GND), X1.7 (GND); also elsewhere on the board
IDE_INT: U2.18 (IO); also elsewhere on the board
IDE_RDY: U2.22 (IO); also elsewhere on the board
unnamed: J1.1, R3.2, U1.F13 (/MMUDIS)
unnamed: J2.1, R1.2, U1.H12 (/CDIS)
unnamed: R9.2, U1.C3 (/BGACK)
unnamed: R8.2, U1.A1 (/BR)
unnamed: R2.2, U1.J1 (/CBACK)
unnamed: R4.2, U1.H2 (/HALT)
R/W: U1.L3 (R/W), U2.67 (IO); also elsewhere on the board
SIZ0: U1.L2 (SIZ0), U2.70 (IO)
SIZ1: U1.K3 (SIZ1), U2.73 (IO)
TCK: J3.1, R13.1, U2.62 (TCK)
TDI: J3.9, R12.2, U2.14 (TDI)
TDO: J3.3, R10.2, U2.71 (TDO)
TMS: J3.5, R11.2, U2.23 (TMS)
/AS: U1.J2 (/AS), U2.64 (IO); also elsewhere on the board
/AVEC: U1.E2 (/AVEC), U2.81 (IO)
/BERR: U1.H1 (/BERR)
/CIIN: U1.L1 (/CIIN), U2.5 (IO)
/CS_DUART: U2.12 (IO); also elsewhere on the board
/CS_FPU: U2.28 (IO); also elsewhere on the board
/CS_ROM: U2.8 (IO); also elsewhere on the board
/CS_SRAM: U2.9 (IO); also elsewhere on the board
/DS: U1.K2 (/DS), U2.65 (IO); also elsewhere on the board
/DSACK0: U1.F1 (/DSACK0), U2.68 (IO)
/DSACK0_FPU: U2.29 (IO); also elsewhere on the board
/DSACK1: U1.G2 (/DSACK1), U2.69 (IO)
/DSACK1_FPU: U2.30 (IO); also elsewhere on the board
/DTACK_DRAM: U2.11 (IO)
/DTACK_DUART: U2.15 (IO); also elsewhere on the board
/IACK_DUART: U2.17 (IO); also elsewhere on the board
/IDE_BUF: U2.27 (IO); also elsewhere on the board
/IDE_CS0: U2.20 (IO); also elsewhere on the board
/IDE_CS1: U2.21 (IO); also elsewhere on the board
/IDE_RD: U2.24 (IO); also elsewhere on the board
/IDE_WR: U2.25 (IO); also elsewhere on the board
/IPL0: R5.2, U1.H13 (/IPL0), U2.74 (IO)
/IPL1: R6.2, U1.G13 (/IPL1), U2.75 (IO)
/IPL2: R7.2, U1.G12 (/IPL2), U2.76 (IO)
/IRQ_DUART: U2.16 (IO); also elsewhere on the board
/RESET: U1.F12 (/RESET), U2.4 (IO); also elsewhere on the board
/STERM: U1.G1 (/STERM), U2.6 (IO)

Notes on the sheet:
TODO: maybe better to put the GPIO and other peripherals on a daughter card
TODO: no expansion CS
TODO: could get away with a lot fewer address pins here Just make sure the DRAM controller has all the signals it needs to decode its own address range (AS, DS, IACK, SIZ? etc.)

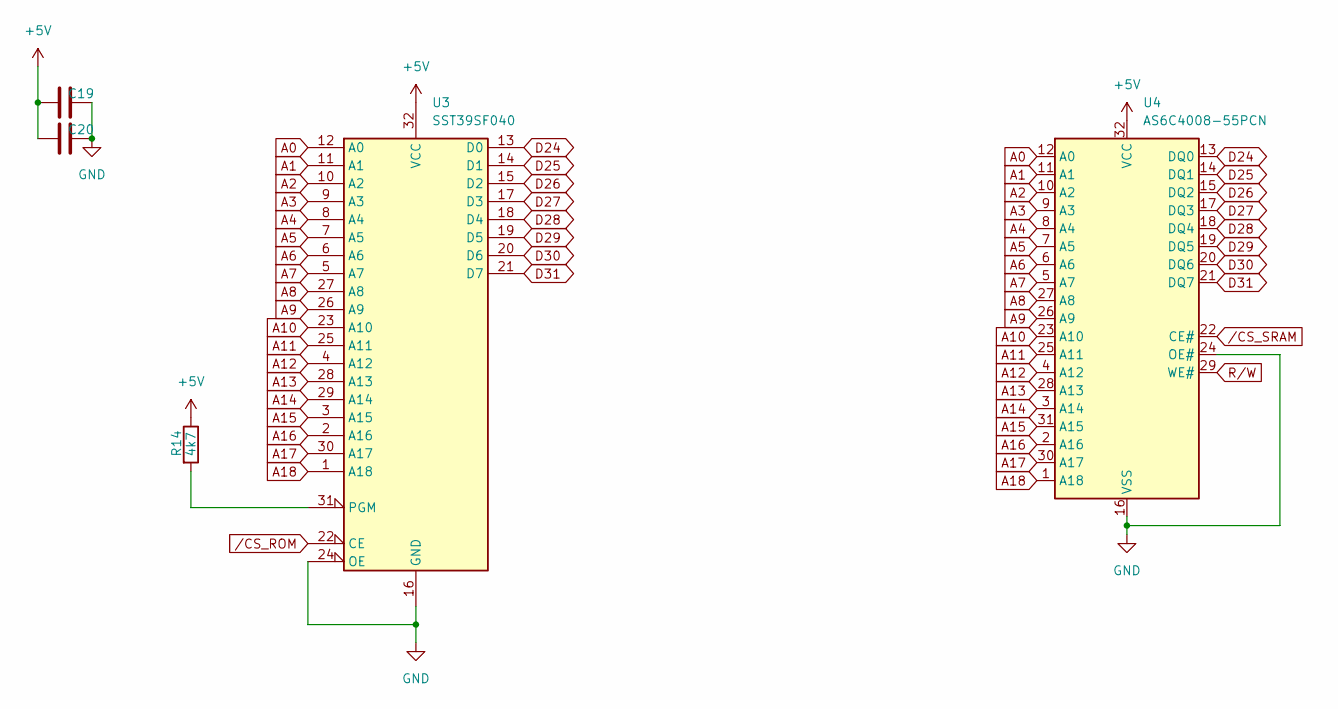
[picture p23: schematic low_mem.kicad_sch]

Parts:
C19, C20: 0.1uF; C_Disc_D4.3mm_W1.9mm_P5.00mm
R14: 4k7; R_Axial_DIN0207_L6.3mm_D2.5mm_P7.62mm_Horizontal
U3: SST39SF040; DIP-32_W15.24mm_Socket
U4: AS6C4008-55PCN; DIP-32_W15.24mm_Socket

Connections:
+5V: C19.1, C20.1, R14.1, U3.32 (VCC), U4.32 (VCC); also elsewhere on the board
A0: U3.12 (A0), U4.12 (A0); also elsewhere on the board
A1: U3.11 (A1), U4.11 (A1); also elsewhere on the board
A2: U3.10 (A2), U4.10 (A2); also elsewhere on the board
A3: U3.9 (A3), U4.9 (A3); also elsewhere on the board
A4: U3.8 (A4), U4.8 (A4); also elsewhere on the board
A5: U3.7 (A5), U4.7 (A5); also elsewhere on the board
A6: U3.6 (A6), U4.6 (A6); also elsewhere on the board
A7: U3.5 (A7), U4.5 (A7); also elsewhere on the board
A8: U3.27 (A8), U4.27 (A8); also elsewhere on the board
A9: U3.26 (A9), U4.26 (A9); also elsewhere on the board
A10: U3.23 (A10), U4.23 (A10); also elsewhere on the board
A11: U3.25 (A11), U4.25 (A11); also elsewhere on the board
A12: U3.4 (A12), U4.4 (A12); also elsewhere on the board
A13: U3.28 (A13), U4.28 (A13); also elsewhere on the board
A14: U3.29 (A14), U4.3 (A14); also elsewhere on the board
A15: U3.3 (A15), U4.31 (A15); also elsewhere on the board
A16: U3.2 (A16), U4.2 (A16); also elsewhere on the board
A17: U3.30 (A17), U4.30 (A17); also elsewhere on the board
A18: U3.1 (A18), U4.1 (A18); also elsewhere on the board
D24: U3.13 (D0), U4.13 (DQ0); also elsewhere on the board
D25: U3.14 (D1), U4.14 (DQ1); also elsewhere on the board
D26: U3.15 (D2), U4.15 (DQ2); also elsewhere on the board
D27: U3.17 (D3), U4.17 (DQ3); also elsewhere on the board
D28: U3.18 (D4), U4.18 (DQ4); also elsewhere on the board
D29: U3.19 (D5), U4.19 (DQ5); also elsewhere on the board
D30: U3.20 (D6), U4.20 (DQ6); also elsewhere on the board
D31: U3.21 (D7), U4.21 (DQ7); also elsewhere on the board
GND: C19.2, C20.2, U3.16 (GND), U3.24 (OE), U4.16 (VSS), U4.24 (OE#); also elsewhere on the board
unnamed: R14.2, U3.31 (PGM)
R/W: U4.29 (WE#); also elsewhere on the board
/CS_ROM: U3.22 (CE); also elsewhere on the board
/CS_SRAM: U4.22 (CE#); also elsewhere on the board

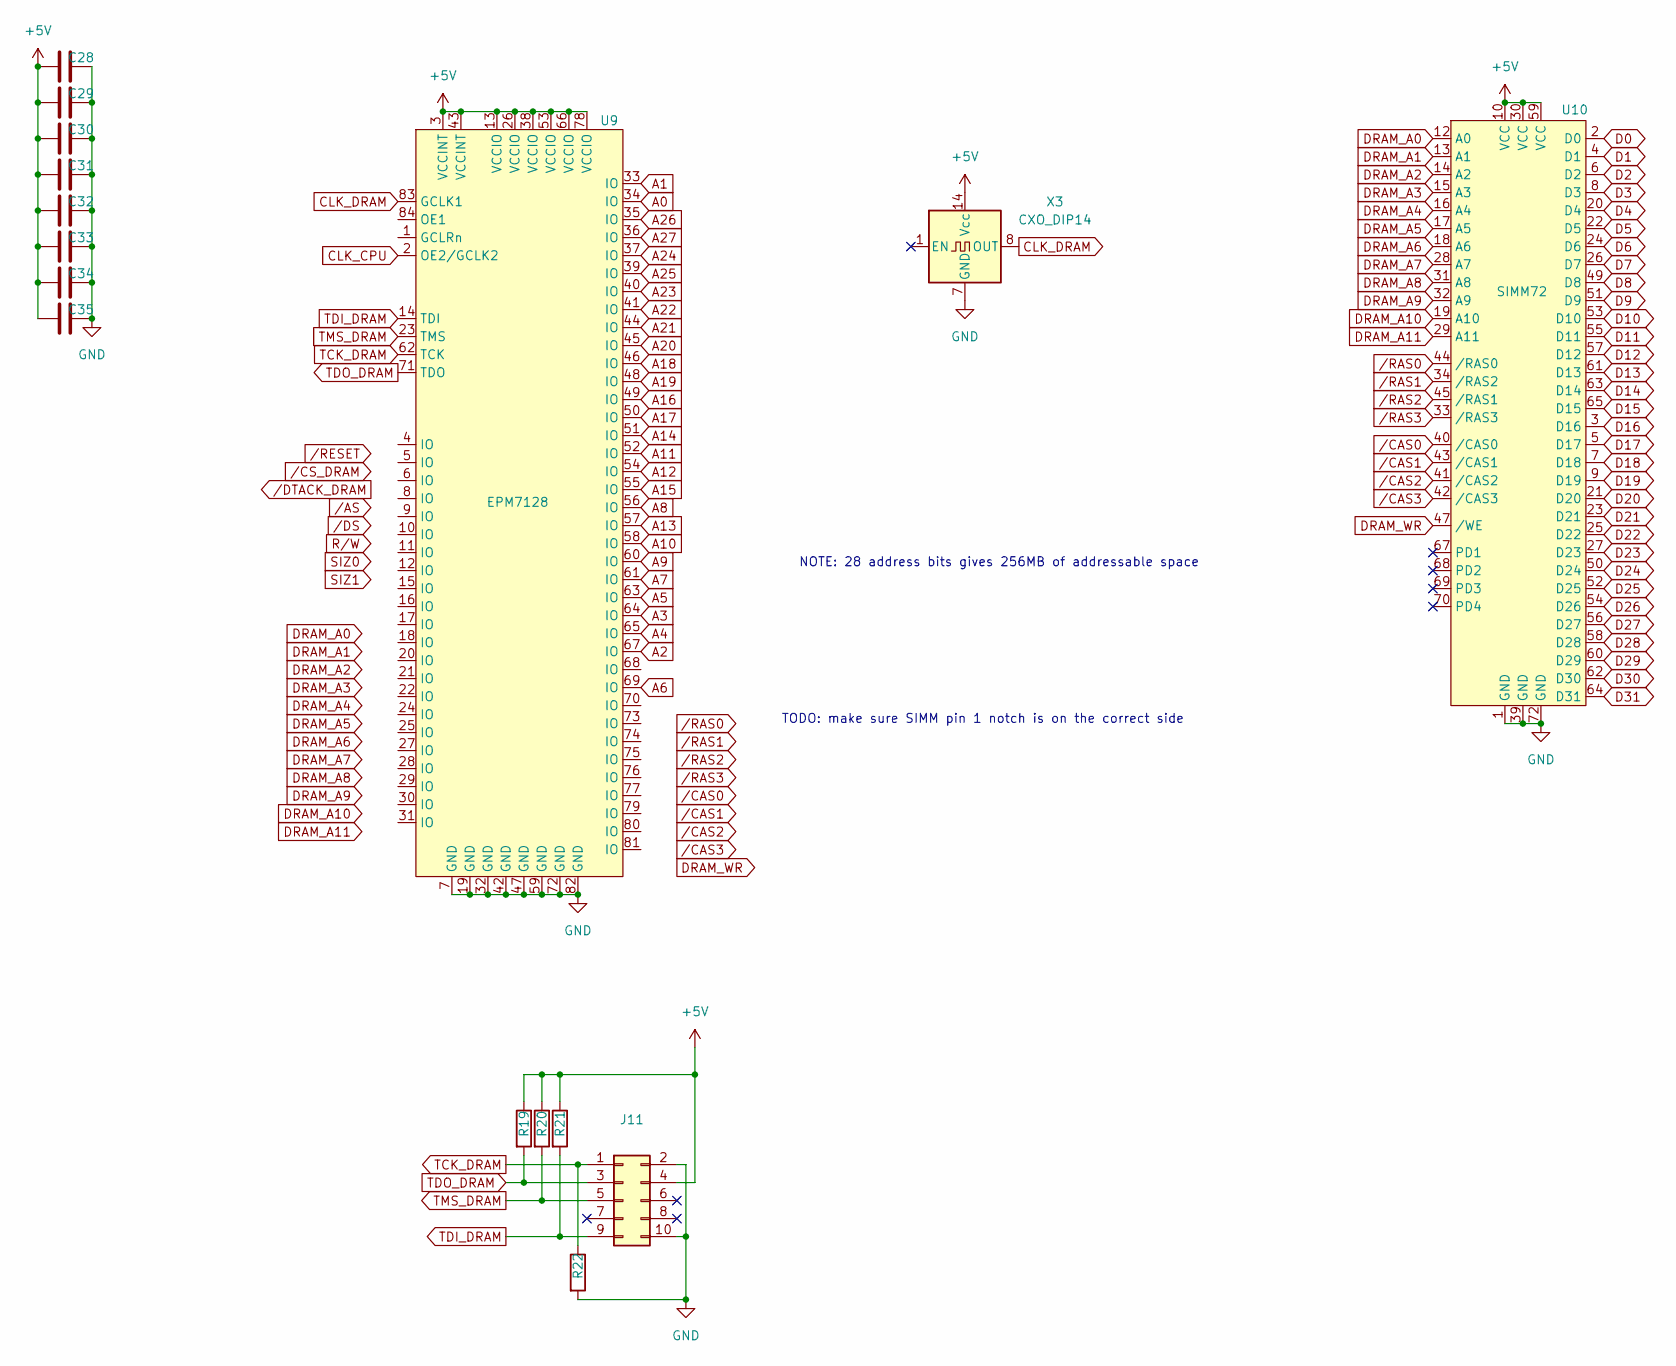
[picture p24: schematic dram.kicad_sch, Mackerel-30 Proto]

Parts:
C28, C29, C30, C31, C32, C33, C34, C35: 0.1uF; C_Disc_D4.3mm_W1.9mm_P5.00mm
J11: Conn_02x05_Odd_Even; IDC-Header_2x05_P2.54mm_Vertical
R19, R20, R21, R22: R; R_Axial_DIN0207_L6.3mm_D2.5mm_P7.62mm_Horizontal
U9: EPM7128; PLCC-84_THT-Socket
U10: SIMM72; SIMM-72
X3: CXO_DIP14; Oscillator_DIP-14

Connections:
+5V: C28.1, C29.1, C30.1, C31.1, C32.1, C33.1, C34.1, C35.1, J11.4, R19.1, R20.1, R21.1, U9.3 (VCCINT), U9.13 (VCCIO), U9.26 (VCCIO), U9.38 (VCCIO), U9.43 (VCCINT), U9.53 (VCCIO), U9.66 (VCCIO), U9.78 (VCCIO), U10.10 (VCC), U10.30 (VCC), U10.59 (VCC), X3.14 (Vcc); also elsewhere on the board
A0: U9.34 (IO); also elsewhere on the board
A1: U9.33 (IO); also elsewhere on the board
A2: U9.67 (IO); also elsewhere on the board
A3: U9.64 (IO); also elsewhere on the board
A4: U9.65 (IO); also elsewhere on the board
A5: U9.63 (IO); also elsewhere on the board
A6: U9.69 (IO); also elsewhere on the board
A7: U9.61 (IO); also elsewhere on the board
A8: U9.56 (IO); also elsewhere on the board
A9: U9.60 (IO); also elsewhere on the board
A10: U9.58 (IO); also elsewhere on the board
A11: U9.52 (IO); also elsewhere on the board
A12: U9.54 (IO); also elsewhere on the board
A13: U9.57 (IO); also elsewhere on the board
A14: U9.51 (IO); also elsewhere on the board
A15: U9.55 (IO); also elsewhere on the board
A16: U9.49 (IO); also elsewhere on the board
A17: U9.50 (IO); also elsewhere on the board
A18: U9.46 (IO); also elsewhere on the board
A19: U9.48 (IO); also elsewhere on the board
A20: U9.45 (IO); also elsewhere on the board
A21: U9.44 (IO); also elsewhere on the board
A22: U9.41 (IO); also elsewhere on the board
A23: U9.40 (IO); also elsewhere on the board
A24: U9.37 (IO); also elsewhere on the board
A25: U9.39 (IO); also elsewhere on the board
A26: U9.35 (IO); also elsewhere on the board
A27: U9.36 (IO); also elsewhere on the board
CLK_CPU: U9.2 (OE2/GCLK2); also elsewhere on the board
CLK_DRAM: U9.83 (GCLK1), X3.8 (OUT)
D0: U10.2 (D0); also elsewhere on the board
D1: U10.4 (D1); also elsewhere on the board
D2: U10.6 (D2); also elsewhere on the board
D3: U10.8 (D3); also elsewhere on the board
D4: U10.20 (D4); also elsewhere on the board
D5: U10.22 (D5); also elsewhere on the board
D6: U10.24 (D6); also elsewhere on the board
D7: U10.26 (D7); also elsewhere on the board
D8: U10.49 (D8); also elsewhere on the board
D9: U10.51 (D9); also elsewhere on the board
D10: U10.53 (D10); also elsewhere on the board
D11: U10.55 (D11); also elsewhere on the board
D12: U10.57 (D12); also elsewhere on the board
D13: U10.61 (D13); also elsewhere on the board
D14: U10.63 (D14); also elsewhere on the board
D15: U10.65 (D15); also elsewhere on the board
D16: U10.3 (D16); also elsewhere on the board
D17: U10.5 (D17); also elsewhere on the board
D18: U10.7 (D18); also elsewhere on the board
D19: U10.9 (D19); also elsewhere on the board
D20: U10.21 (D20); also elsewhere on the board
D21: U10.23 (D21); also elsewhere on the board
D22: U10.25 (D22); also elsewhere on the board
D23: U10.27 (D23); also elsewhere on the board
D24: U10.50 (D24); also elsewhere on the board
D25: U10.52 (D25); also elsewhere on the board
D26: U10.54 (D26); also elsewhere on the board
D27: U10.56 (D27); also elsewhere on the board
D28: U10.58 (D28); also elsewhere on the board
D29: U10.60 (D29); also elsewhere on the board
D30: U10.62 (D30); also elsewhere on the board
D31: U10.64 (D31); also elsewhere on the board
DRAM_A0: U10.12 (A0)
DRAM_A1: U10.13 (A1)
DRAM_A2: U10.14 (A2)
DRAM_A3: U10.15 (A3)
DRAM_A4: U10.16 (A4)
DRAM_A5: U10.17 (A5)
DRAM_A6: U10.18 (A6)
DRAM_A7: U10.28 (A7)
DRAM_A8: U10.31 (A8)
DRAM_A9: U10.32 (A9)
DRAM_A10: U10.19 (A10)
DRAM_A11: U10.29 (A11)
DRAM_WR: U10.47 (/WE)
GND: C28.2, C29.2, C30.2, C31.2, C32.2, C33.2, C34.2, C35.2, J11.2, J11.10, R22.2, U9.7 (GND), U9.19 (GND), U9.32 (GND), U9.42 (GND), U9.47 (GND), U9.59 (GND), U9.72 (GND), U9.82 (GND), U10.1 (GND), U10.39 (GND), U10.72 (GND), X3.7 (GND); also elsewhere on the board
TCK_DRAM: J11.1, R22.1, U9.62 (TCK)
TDI_DRAM: J11.9, R21.2, U9.14 (TDI)
TDO_DRAM: J11.3, R19.2, U9.71 (TDO)
TMS_DRAM: J11.5, R20.2, U9.23 (TMS)
/CAS0: U10.40 (/CAS0)
/CAS1: U10.43 (/CAS1)
/CAS2: U10.41 (/CAS2)
/CAS3: U10.42 (/CAS3)
/RAS0: U10.44 (/RAS0)
/RAS1: U10.34 (/RAS2)
/RAS2: U10.45 (/RAS1)
/RAS3: U10.33 (/RAS3)

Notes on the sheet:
NOTE: 28 address bits gives 256MB of addressable space
TODO: make sure SIMM pin 1 notch is on the correct side

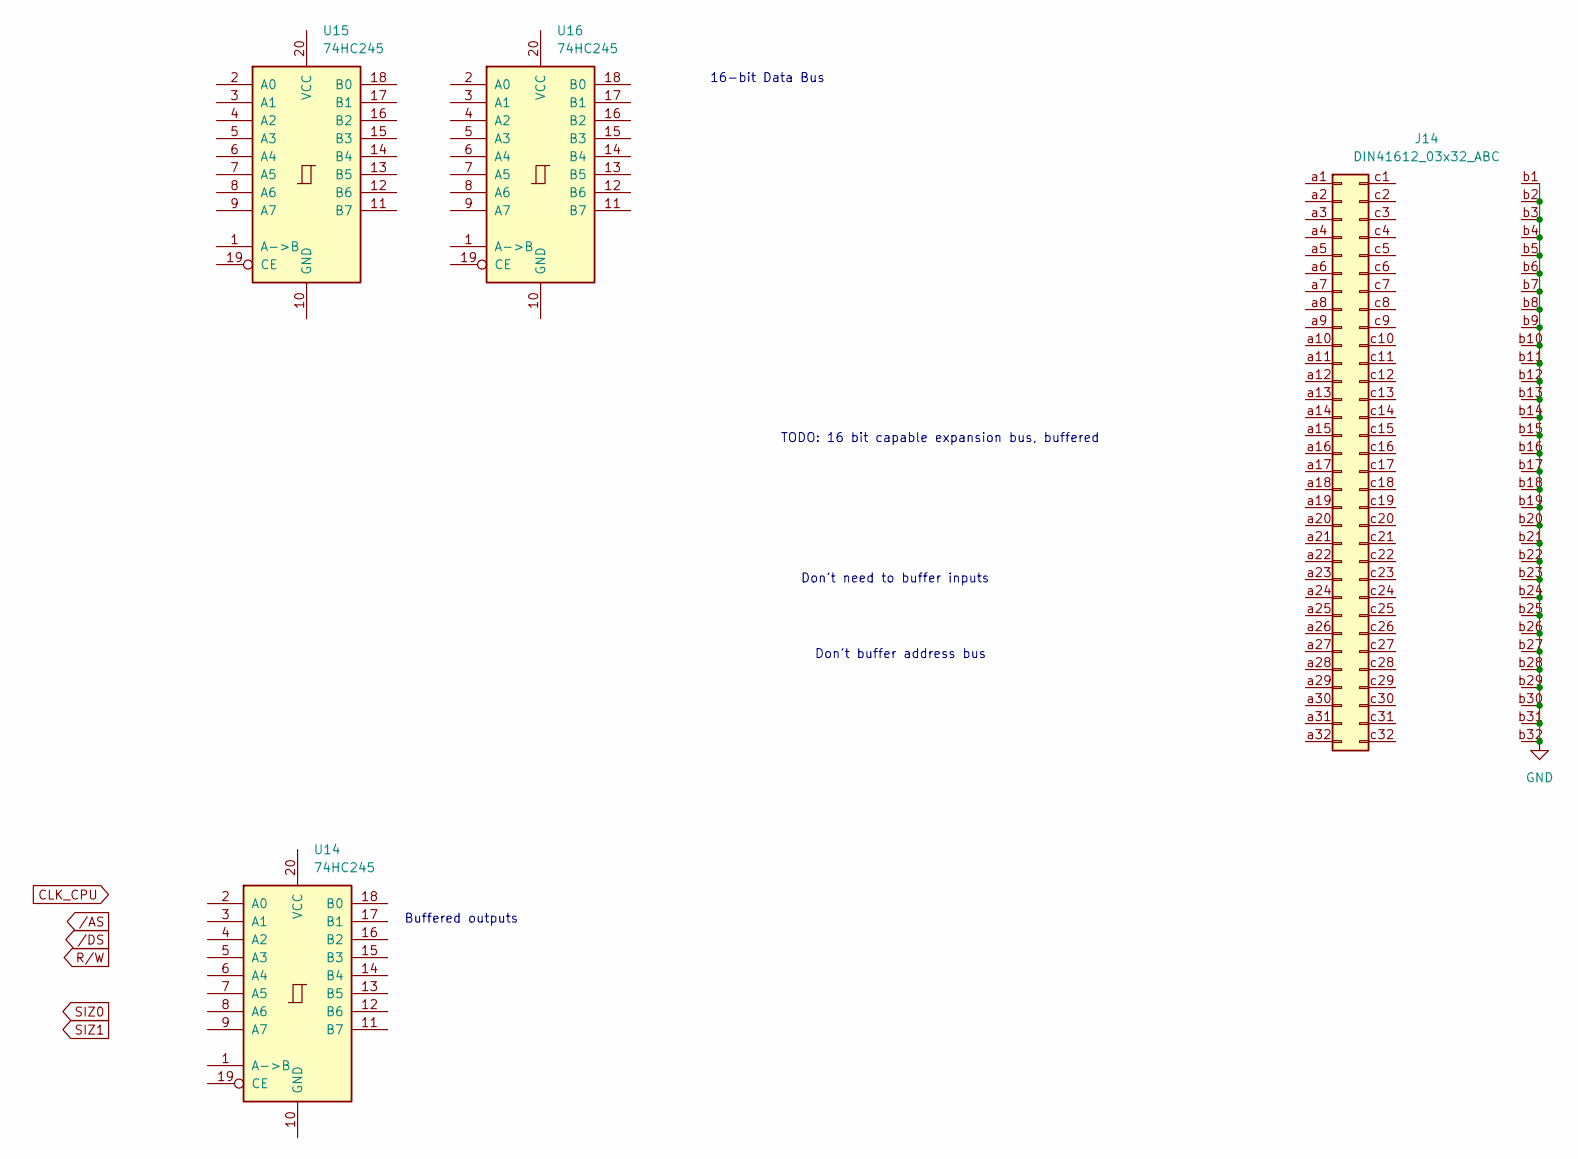
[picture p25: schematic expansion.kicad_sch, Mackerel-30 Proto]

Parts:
J14: DIN41612_03x32_ABC; DIN41612_C_3x32_Female_Vertical_THT
U14, U15, U16: 74HC245; DIP-20_W7.62mm_Socket

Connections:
GND: J14.b1, J14.b2, J14.b3, J14.b4, J14.b5, J14.b6, J14.b7, J14.b8, J14.b9, J14.b10, J14.b11, J14.b12, J14.b13, J14.b14, J14.b15, J14.b16, J14.b17, J14.b18, J14.b19, J14.b20, J14.b21, J14.b22, J14.b23, J14.b24, J14.b25, J14.b26, J14.b27, J14.b28, J14.b29, J14.b30, J14.b31, J14.b32; also elsewhere on the board

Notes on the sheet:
16-bit Data Bus
Don't buffer address bus
Buffered outputs
TODO: 16 bit capable expansion bus, buffered
Don't need to buffer inputs

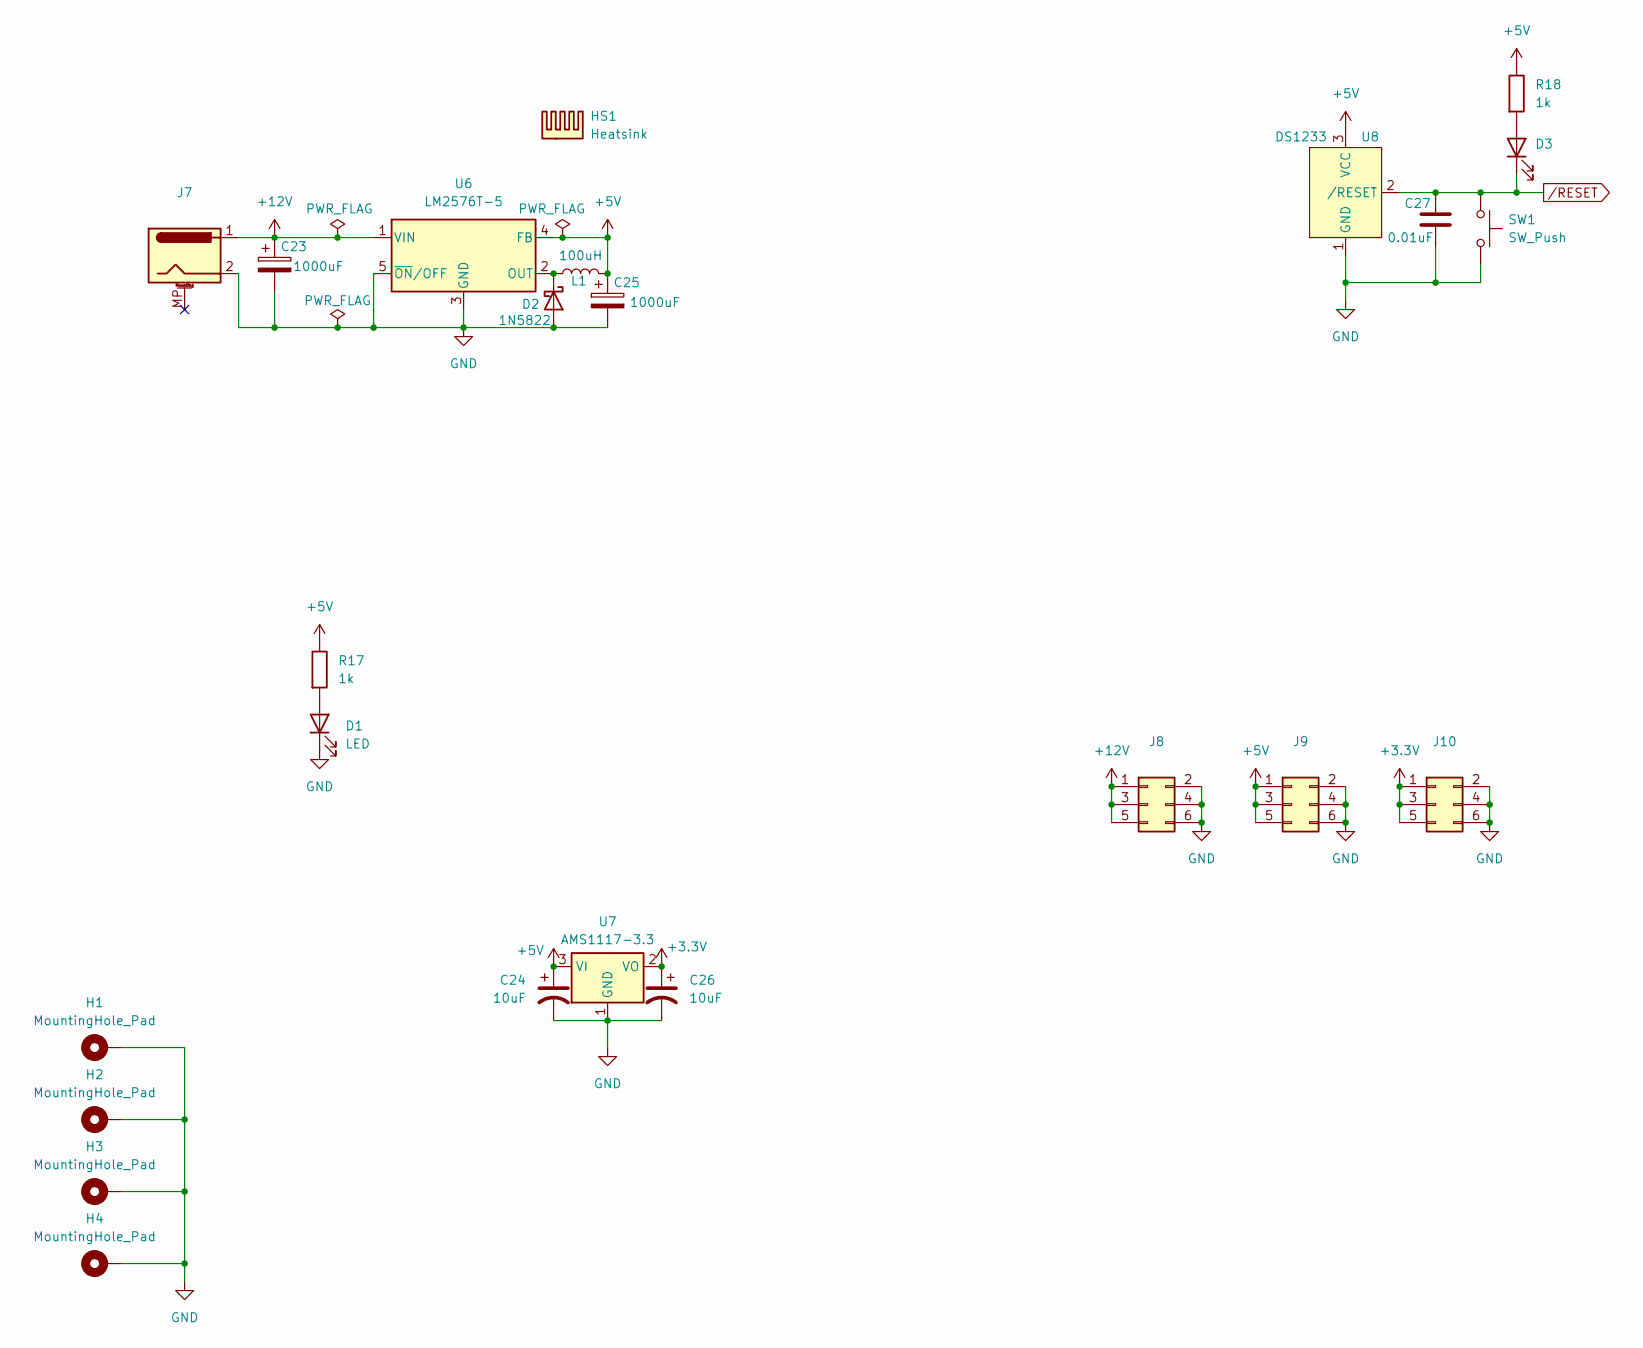
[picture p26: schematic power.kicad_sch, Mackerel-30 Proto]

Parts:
C23, C25: 1000uF; CP_Radial_D10.0mm_P5.00mm
C24, C26: 10uF; CP_Radial_D5.0mm_P2.00mm
C27: 0.01uF; C_Disc_D4.3mm_W1.9mm_P5.00mm
D1, D3: LED; LED_D5.0mm
D2: 1N5822; D_DO-27_P15.24mm_Horizontal
H1, H2, H3, H4: MountingHole_Pad; MountingHole_3.2mm_M3_Pad_Via
HS1: Heatsink; Heatsink_Stonecold_HS-S02_13.21x9.53mm
J7: Barrel_Jack_MountingPin; BarrelJack_Horizontal
J8, J9, J10: Conn_02x03_Odd_Even; PinHeader_2x03_P2.54mm_Vertical
L1: 100uH; L_Radial_D10.0mm_P5.00mm_Fastron_07M
R17, R18: 1k; R_Axial_DIN0207_L6.3mm_D2.5mm_P7.62mm_Horizontal
SW1: SW_Push; SW_PUSH_6mm_H5mm
U6: LM2576T-5; TO-220-5_Vertical
U7: AMS1117-3.3; SOT-223-3_TabPin2
U8: DS1233; TO-92

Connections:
+3.3V: C26.1, J10.1, J10.3, J10.5, U7.2 (VO); also elsewhere on the board
+5V: C24.1, C25.1, J9.1, J9.3, J9.5, L1.2, R17.1, R18.1, U6.4 (FB), U7.3 (VI), U8.3 (VCC); also elsewhere on the board
+12V: C23.1, J7.1, J8.1, J8.3, J8.5, U6.1 (VIN); also elsewhere on the board
GND: C23.2, C24.2, C25.2, C26.2, C27.2, D1.1 (K), D2.2 (A), H1.1, H2.1, H3.1, H4.1, J7.2, J8.2, J8.4, J8.6, J9.2, J9.4, J9.6, J10.2, J10.4, J10.6, SW1.2, U6.3 (GND), U6.5 (~ON/OFF), U7.1 (GND), U8.1 (GND); also elsewhere on the board
unnamed: D1.2 (A), R17.2
unnamed: D2.1 (K), L1.1, U6.2 (OUT)
unnamed: D3.2 (A), R18.2
/RESET: C27.1, D3.1 (K), SW1.1, U8.2 (/RESET); also elsewhere on the board

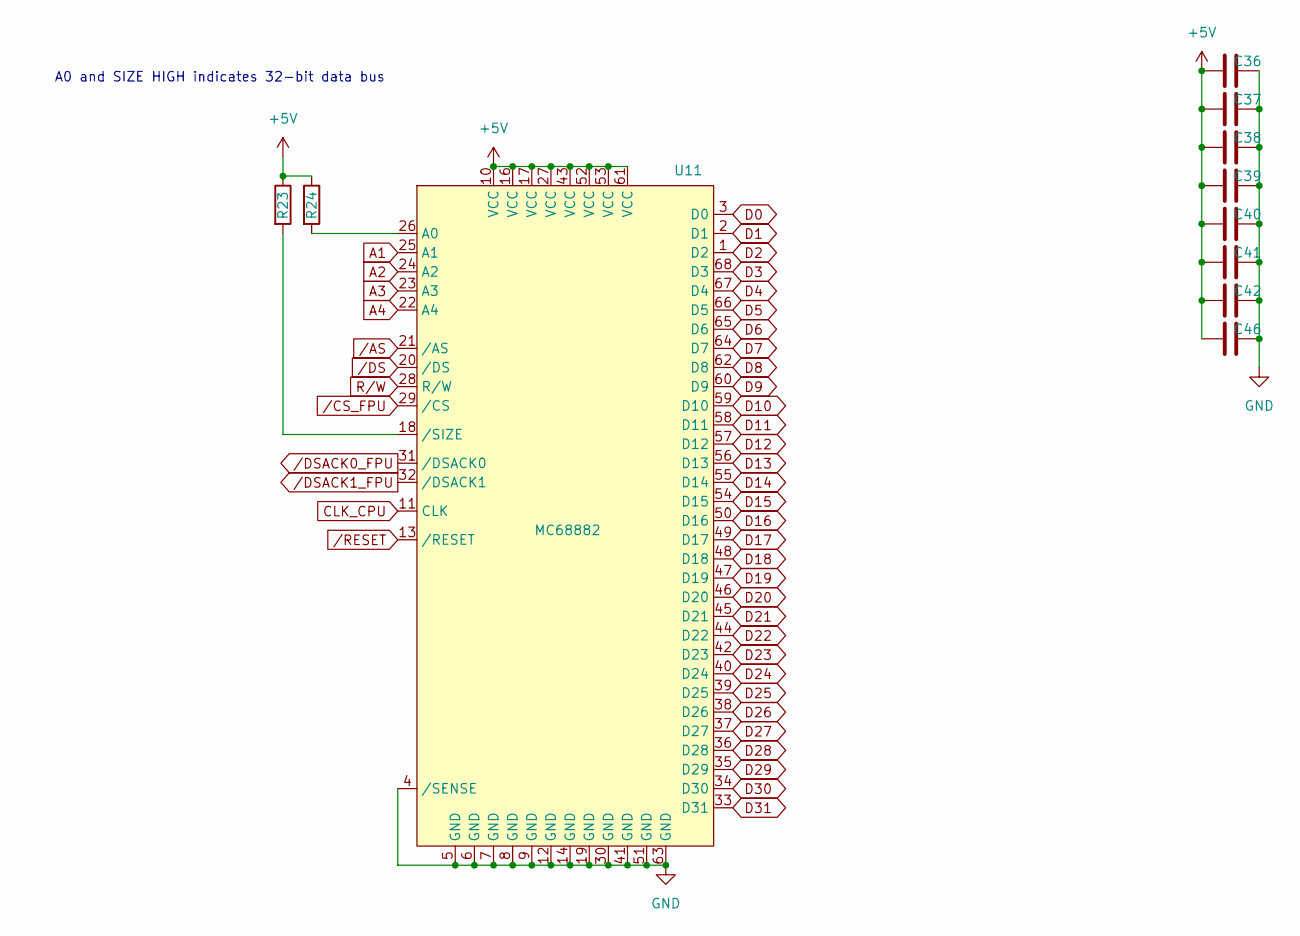
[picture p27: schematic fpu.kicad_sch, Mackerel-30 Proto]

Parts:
C36, C37, C38, C39, C40, C41, C42, C46: 0.1uF; C_Disc_D4.3mm_W1.9mm_P5.00mm
R23, R24: 4k7; R_Axial_DIN0207_L6.3mm_D2.5mm_P7.62mm_Horizontal
U11: MC68882; PLCC-68_THT-Socket

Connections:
+5V: C36.1, C37.1, C38.1, C39.1, C40.1, C41.1, C42.1, C46.1, R23.1, R24.1, U11.10 (VCC), U11.16 (VCC), U11.17 (VCC), U11.27 (VCC), U11.43 (VCC), U11.52 (VCC), U11.53 (VCC), U11.61 (VCC); also elsewhere on the board
A1: U11.25 (A1); also elsewhere on the board
A2: U11.24 (A2); also elsewhere on the board
A3: U11.23 (A3); also elsewhere on the board
A4: U11.22 (A4); also elsewhere on the board
CLK_CPU: U11.11 (CLK); also elsewhere on the board
D0: U11.3 (D0); also elsewhere on the board
D1: U11.2 (D1); also elsewhere on the board
D2: U11.1 (D2); also elsewhere on the board
D3: U11.68 (D3); also elsewhere on the board
D4: U11.67 (D4); also elsewhere on the board
D5: U11.66 (D5); also elsewhere on the board
D6: U11.65 (D6); also elsewhere on the board
D7: U11.64 (D7); also elsewhere on the board
D8: U11.62 (D8); also elsewhere on the board
D9: U11.60 (D9); also elsewhere on the board
D10: U11.59 (D10); also elsewhere on the board
D11: U11.58 (D11); also elsewhere on the board
D12: U11.57 (D12); also elsewhere on the board
D13: U11.56 (D13); also elsewhere on the board
D14: U11.55 (D14); also elsewhere on the board
D15: U11.54 (D15); also elsewhere on the board
D16: U11.50 (D16); also elsewhere on the board
D17: U11.49 (D17); also elsewhere on the board
D18: U11.48 (D18); also elsewhere on the board
D19: U11.47 (D19); also elsewhere on the board
D20: U11.46 (D20); also elsewhere on the board
D21: U11.45 (D21); also elsewhere on the board
D22: U11.44 (D22); also elsewhere on the board
D23: U11.42 (D23); also elsewhere on the board
D24: U11.40 (D24); also elsewhere on the board
D25: U11.39 (D25); also elsewhere on the board
D26: U11.38 (D26); also elsewhere on the board
D27: U11.37 (D27); also elsewhere on the board
D28: U11.36 (D28); also elsewhere on the board
D29: U11.35 (D29); also elsewhere on the board
D30: U11.34 (D30); also elsewhere on the board
D31: U11.33 (D31); also elsewhere on the board
GND: C36.2, C37.2, C38.2, C39.2, C40.2, C41.2, C42.2, C46.2, U11.4 (/SENSE), U11.5 (GND), U11.6 (GND), U11.7 (GND), U11.8 (GND), U11.9 (GND), U11.12 (GND), U11.14 (GND), U11.19 (GND), U11.30 (GND), U11.41 (GND), U11.51 (GND), U11.63 (GND); also elsewhere on the board
unnamed: R24.2, U11.26 (A0)
unnamed: R23.2, U11.18 (/SIZE)
R/W: U11.28 (R/W); also elsewhere on the board
/AS: U11.21 (/AS); also elsewhere on the board
/CS_FPU: U11.29 (/CS); also elsewhere on the board
/DS: U11.20 (/DS); also elsewhere on the board
/DSACK0_FPU: U11.31 (/DSACK0); also elsewhere on the board
/DSACK1_FPU: U11.32 (/DSACK1); also elsewhere on the board
/RESET: U11.13 (/RESET); also elsewhere on the board

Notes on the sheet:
A0 and SIZE HIGH indicates 32-bit data bus

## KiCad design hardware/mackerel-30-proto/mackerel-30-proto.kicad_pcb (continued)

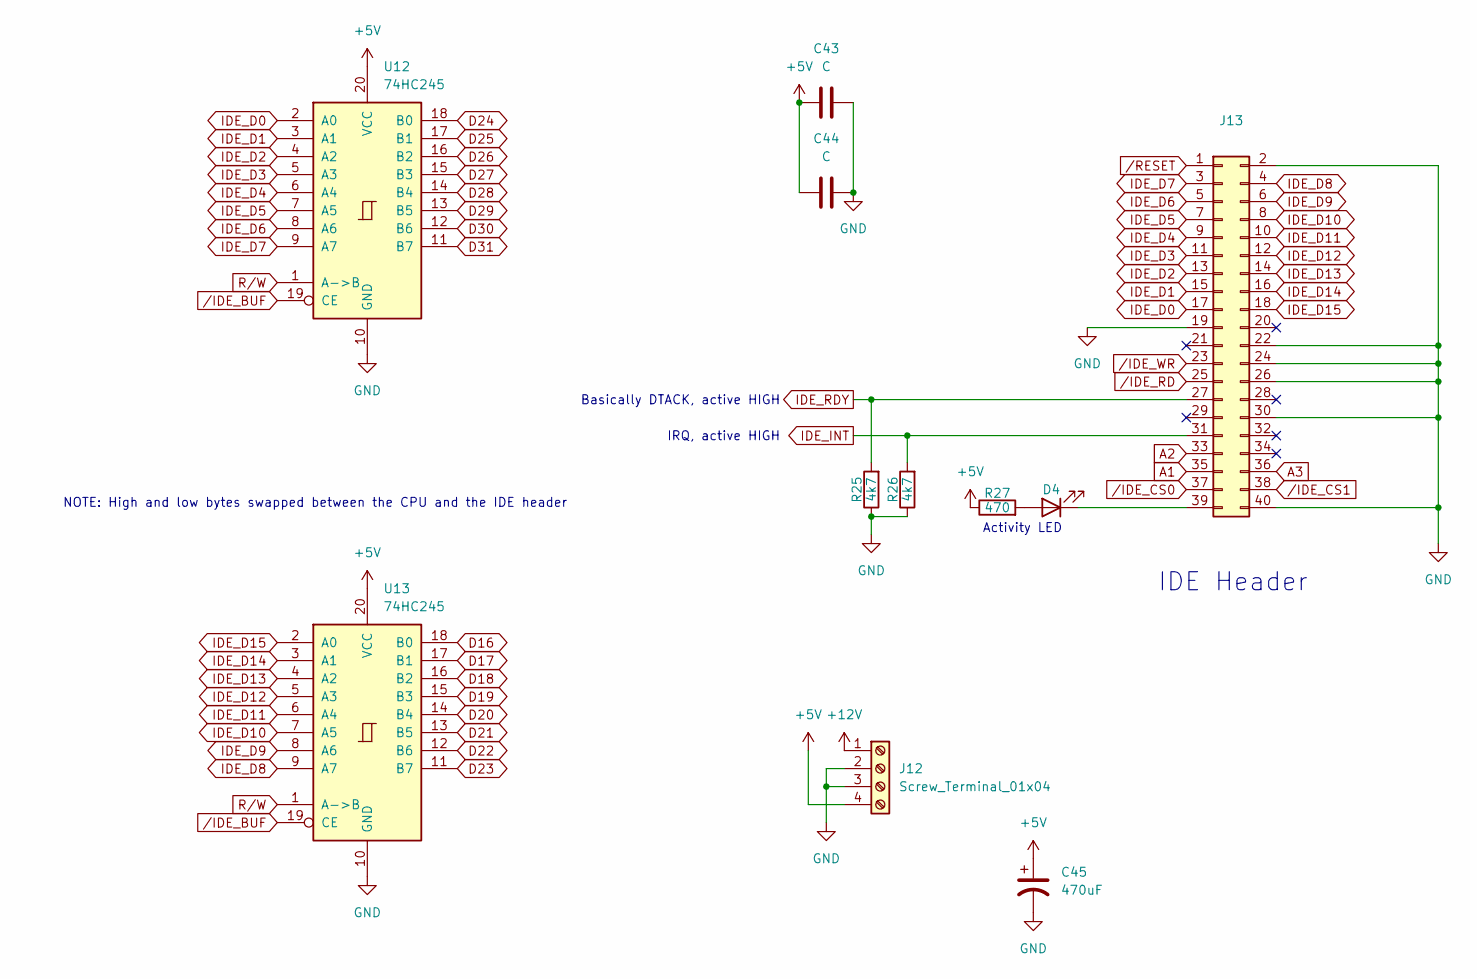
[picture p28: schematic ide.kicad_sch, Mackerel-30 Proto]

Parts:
C43, C44: C; C_Disc_D4.3mm_W1.9mm_P5.00mm
C45: 470uF; CP_Radial_D8.0mm_P3.50mm
D4: LED; LED_D5.0mm
J12: Screw_Terminal_01x04; TerminalBlock_bornier-4_P5.08mm
J13: Conn_02x20_Odd_Even; IDC-Header_2x20_P2.54mm_Vertical
R25, R26: 4k7; R_Axial_DIN0207_L6.3mm_D2.5mm_P7.62mm_Horizontal
R27: 470; R_Axial_DIN0207_L6.3mm_D2.5mm_P7.62mm_Horizontal
U12, U13: 74HC245; DIP-20_W7.62mm_Socket

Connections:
+5V: C43.1, C44.1, C45.1, J12.4, R27.1, U12.20 (VCC), U13.20 (VCC); also elsewhere on the board
+12V: J12.1; also elsewhere on the board
A1: J13.35; also elsewhere on the board
A2: J13.33; also elsewhere on the board
A3: J13.36; also elsewhere on the board
D16: U13.18 (B0); also elsewhere on the board
D17: U13.17 (B1); also elsewhere on the board
D18: U13.16 (B2); also elsewhere on the board
D19: U13.15 (B3); also elsewhere on the board
D20: U13.14 (B4); also elsewhere on the board
D21: U13.13 (B5); also elsewhere on the board
D22: U13.12 (B6); also elsewhere on the board
D23: U13.11 (B7); also elsewhere on the board
D24: U12.18 (B0); also elsewhere on the board
D25: U12.17 (B1); also elsewhere on the board
D26: U12.16 (B2); also elsewhere on the board
D27: U12.15 (B3); also elsewhere on the board
D28: U12.14 (B4); also elsewhere on the board
D29: U12.13 (B5); also elsewhere on the board
D30: U12.12 (B6); also elsewhere on the board
D31: U12.11 (B7); also elsewhere on the board
GND: C43.2, C44.2, C45.2, J12.2, J12.3, J13.2, J13.19, J13.22, J13.24, J13.26, J13.30, J13.40, R25.1, R26.1, U12.10 (GND), U13.10 (GND); also elsewhere on the board
IDE_D0: J13.17, U12.2 (A0)
IDE_D1: J13.15, U12.3 (A1)
IDE_D2: J13.13, U12.4 (A2)
IDE_D3: J13.11, U12.5 (A3)
IDE_D4: J13.9, U12.6 (A4)
IDE_D5: J13.7, U12.7 (A5)
IDE_D6: J13.5, U12.8 (A6)
IDE_D7: J13.3, U12.9 (A7)
IDE_D8: J13.4, U13.9 (A7)
IDE_D9: J13.6, U13.8 (A6)
IDE_D10: J13.8, U13.7 (A5)
IDE_D11: J13.10, U13.6 (A4)
IDE_D12: J13.12, U13.5 (A3)
IDE_D13: J13.14, U13.4 (A2)
IDE_D14: J13.16, U13.3 (A1)
IDE_D15: J13.18, U13.2 (A0)
IDE_INT: J13.31, R26.2; also elsewhere on the board
IDE_RDY: J13.27, R25.2; also elsewhere on the board
unnamed: D4.2 (A), R27.2
unnamed: D4.1 (K), J13.39
R/W: U12.1 (A->B), U13.1 (A->B); also elsewhere on the board
/IDE_BUF: U12.19 (CE), U13.19 (CE); also elsewhere on the board
/IDE_CS0: J13.37; also elsewhere on the board
/IDE_CS1: J13.38; also elsewhere on the board
/IDE_RD: J13.25; also elsewhere on the board
/IDE_WR: J13.23; also elsewhere on the board
/RESET: J13.1; also elsewhere on the board

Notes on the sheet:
Activity LED
IRQ, active HIGH
NOTE: High and low bytes swapped between the CPU and the IDE header
Basically DTACK, active HIGH
IDE Header

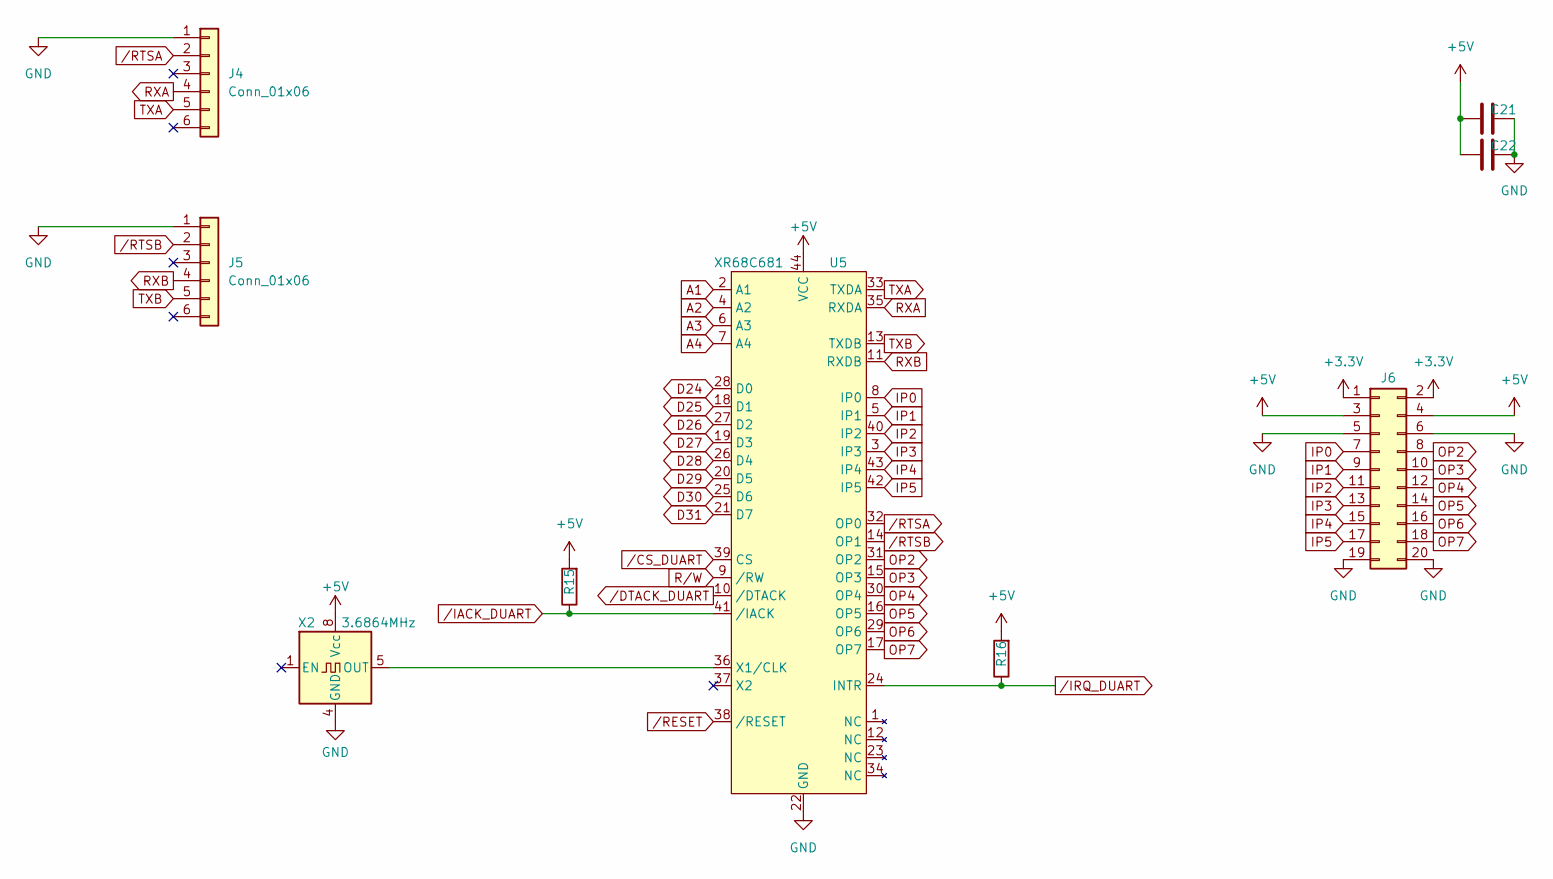
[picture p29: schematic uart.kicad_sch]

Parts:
C21, C22: 0.1uF; C_Disc_D4.3mm_W1.9mm_P5.00mm
J4, J5: Conn_01x06; PinHeader_1x06_P2.54mm_Vertical
J6: Conn_02x10_Odd_Even; PinHeader_2x10_P2.54mm_Vertical
R15, R16: R; R_Axial_DIN0207_L6.3mm_D2.5mm_P7.62mm_Horizontal
U5: XR68C681; PLCC-44_THT-Socket
X2: 3.6864MHz; Oscillator_DIP-8

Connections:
+3.3V: J6.1, J6.2; also elsewhere on the board
+5V: C21.1, C22.1, J6.3, J6.4, R15.2, R16.2, U5.44 (VCC), X2.8 (Vcc); also elsewhere on the board
A1: U5.2 (A1); also elsewhere on the board
A2: U5.4 (A2); also elsewhere on the board
A3: U5.6 (A3); also elsewhere on the board
A4: U5.7 (A4); also elsewhere on the board
D24: U5.28 (D0); also elsewhere on the board
D25: U5.18 (D1); also elsewhere on the board
D26: U5.27 (D2); also elsewhere on the board
D27: U5.19 (D3); also elsewhere on the board
D28: U5.26 (D4); also elsewhere on the board
D29: U5.20 (D5); also elsewhere on the board
D30: U5.25 (D6); also elsewhere on the board
D31: U5.21 (D7); also elsewhere on the board
GND: C21.2, C22.2, J4.1, J5.1, J6.5, J6.6, J6.19, J6.20, U5.22 (GND), X2.4 (GND); also elsewhere on the board
IP0: J6.7, U5.8 (IP0)
IP1: J6.9, U5.5 (IP1)
IP2: J6.11, U5.40 (IP2)
IP3: J6.13, U5.3 (IP3)
IP4: J6.15, U5.43 (IP4)
IP5: J6.17, U5.42 (IP5)
unnamed: U5.36 (X1/CLK), X2.5 (OUT)
OP2: J6.8, U5.31 (OP2)
OP3: J6.10, U5.15 (OP3)
OP4: J6.12, U5.30 (OP4)
OP5: J6.14, U5.16 (OP5)
OP6: J6.16, U5.29 (OP6)
OP7: J6.18, U5.17 (OP7)
RXA: J4.4, U5.35 (RXDA)
RXB: J5.4, U5.11 (RXDB)
R/W: U5.9 (/RW); also elsewhere on the board
TXA: J4.5, U5.33 (TXDA)
TXB: J5.5, U5.13 (TXDB)
/CS_DUART: U5.39 (CS); also elsewhere on the board
/DTACK_DUART: U5.10 (/DTACK); also elsewhere on the board
/IACK_DUART: R15.1, U5.41 (/IACK); also elsewhere on the board
/IRQ_DUART: R16.1, U5.24 (INTR); also elsewhere on the board
/RESET: U5.38 (/RESET); also elsewhere on the board
/RTSA: J4.2, U5.32 (OP0)
/RTSB: J5.2, U5.14 (OP1)

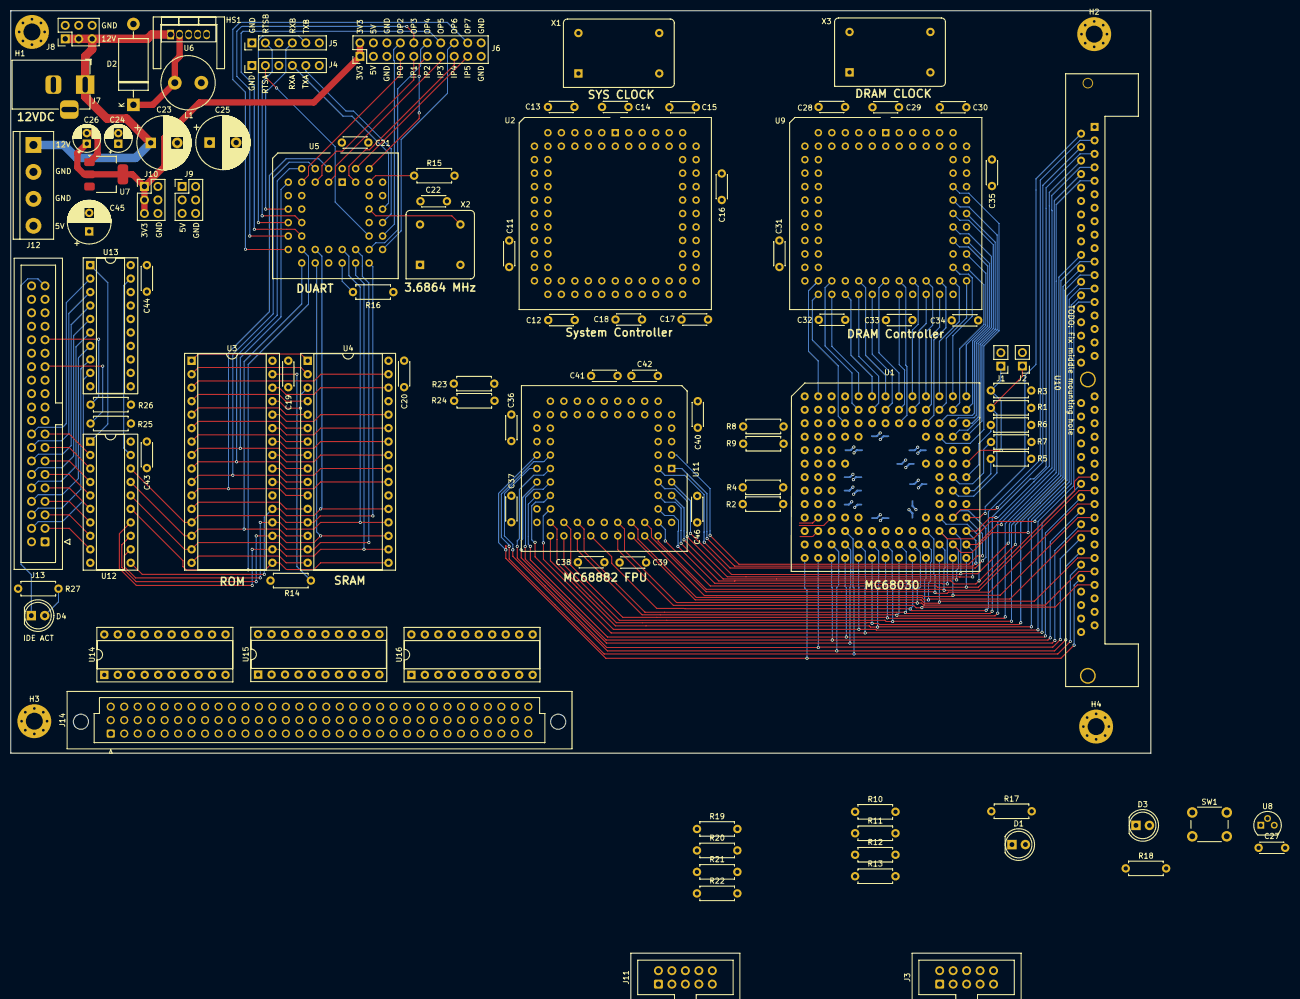
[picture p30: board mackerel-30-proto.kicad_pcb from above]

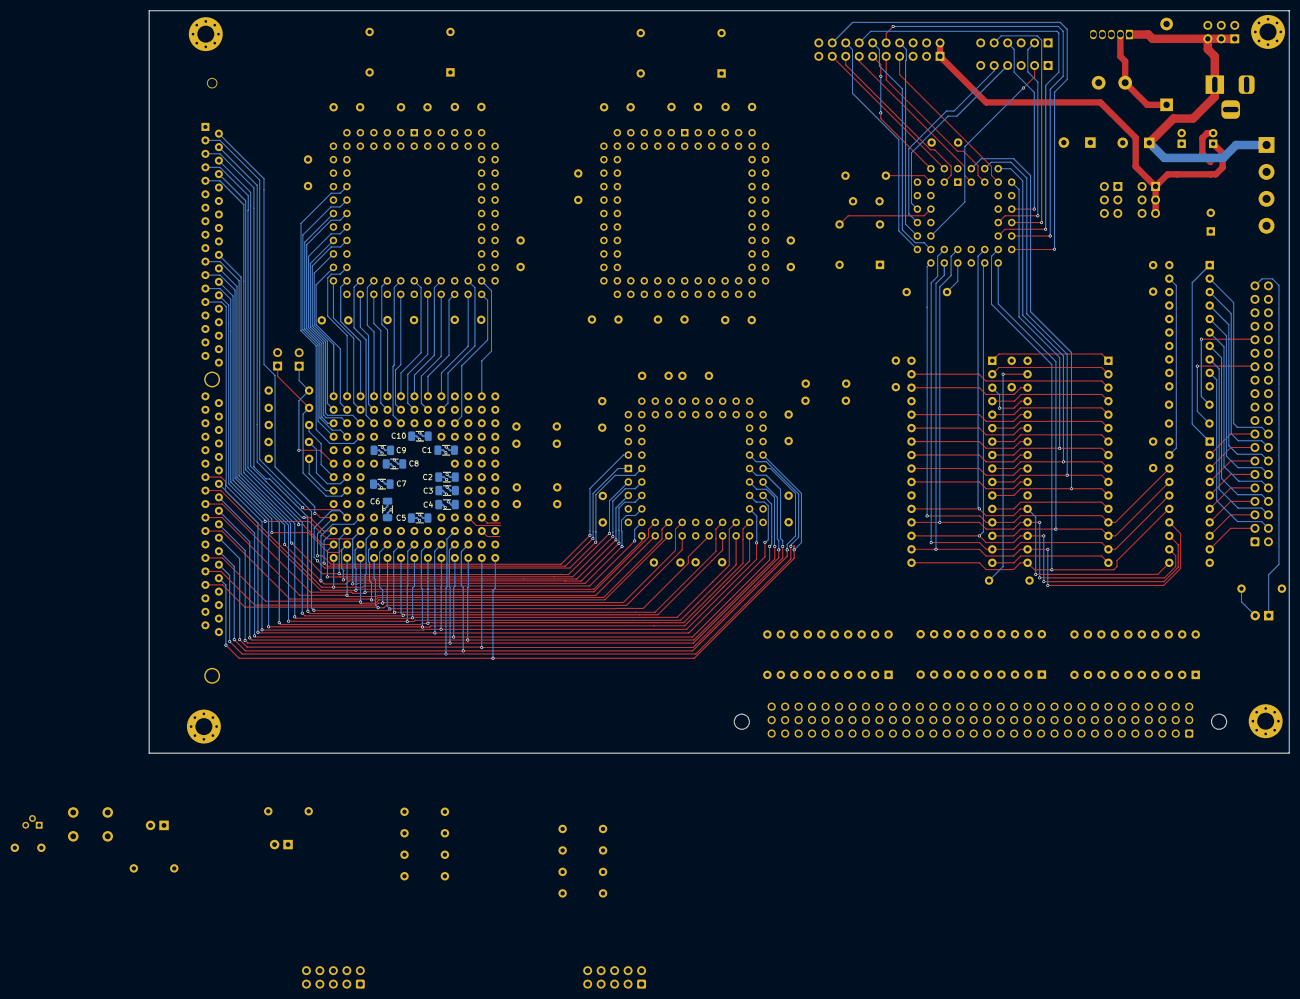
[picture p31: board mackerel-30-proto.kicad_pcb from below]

Board: 4 copper layers, 215.0 x 140.0 mm, 117 parts (10 on the bottom side), 160 nets.

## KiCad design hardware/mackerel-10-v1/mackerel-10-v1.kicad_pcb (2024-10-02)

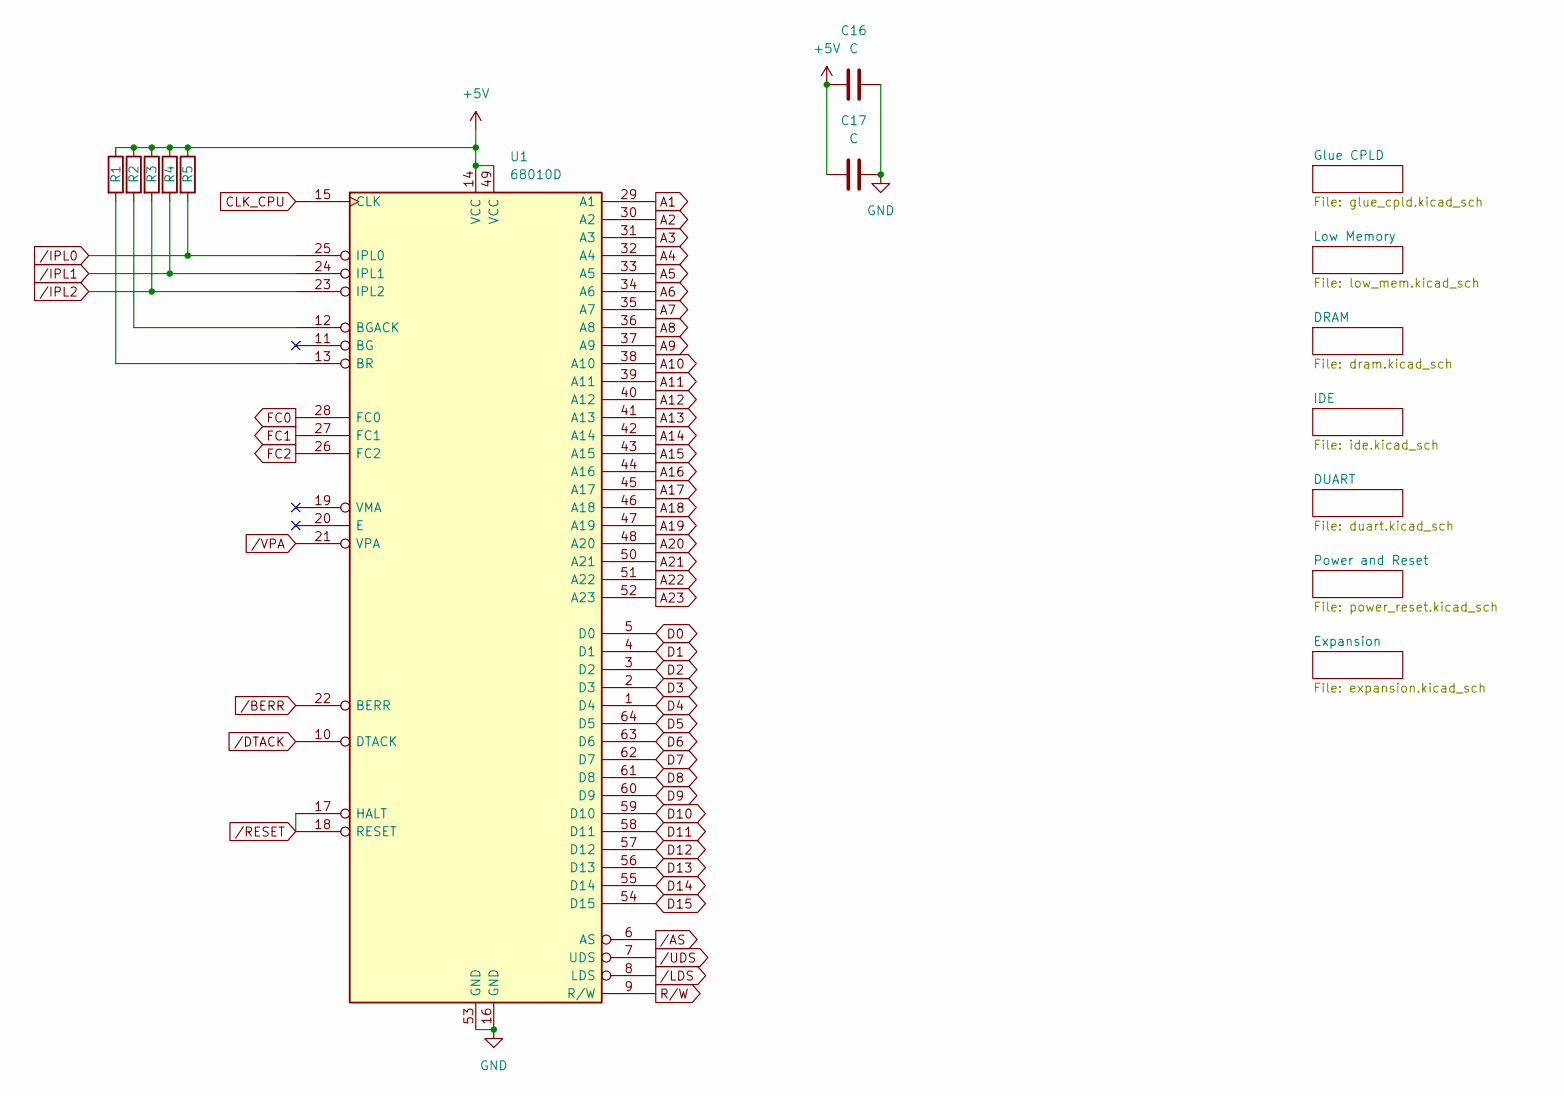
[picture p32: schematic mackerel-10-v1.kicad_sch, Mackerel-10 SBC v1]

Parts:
C16, C17: C; C_Disc_D4.3mm_W1.9mm_P5.00mm
R1, R2, R3, R4, R5: R; R_Axial_DIN0207_L6.3mm_D2.5mm_P7.62mm_Horizontal
U1: 68010D; DIP-64_W22.86mm

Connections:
+5V: C16.1, C17.1, R1.1, R2.1, R3.1, R4.1, R5.1, U1.14 (VCC), U1.49 (VCC); also elsewhere on the board
A1: U1.29 (A1); also elsewhere on the board
A2: U1.30 (A2); also elsewhere on the board
A3: U1.31 (A3); also elsewhere on the board
A4: U1.32 (A4); also elsewhere on the board
A5: U1.33 (A5); also elsewhere on the board
A6: U1.34 (A6); also elsewhere on the board
A7: U1.35 (A7); also elsewhere on the board
A8: U1.36 (A8); also elsewhere on the board
A9: U1.37 (A9); also elsewhere on the board
A10: U1.38 (A10); also elsewhere on the board
A11: U1.39 (A11); also elsewhere on the board
A12: U1.40 (A12); also elsewhere on the board
A13: U1.41 (A13); also elsewhere on the board
A14: U1.42 (A14); also elsewhere on the board
A15: U1.43 (A15); also elsewhere on the board
A16: U1.44 (A16); also elsewhere on the board
A17: U1.45 (A17); also elsewhere on the board
A18: U1.46 (A18); also elsewhere on the board
A19: U1.47 (A19); also elsewhere on the board
A20: U1.48 (A20); also elsewhere on the board
A21: U1.50 (A21); also elsewhere on the board
A22: U1.51 (A22); also elsewhere on the board
A23: U1.52 (A23); also elsewhere on the board
CLK_CPU: U1.15 (CLK); also elsewhere on the board
D0: U1.5 (D0); also elsewhere on the board
D1: U1.4 (D1); also elsewhere on the board
D2: U1.3 (D2); also elsewhere on the board
D3: U1.2 (D3); also elsewhere on the board
D4: U1.1 (D4); also elsewhere on the board
D5: U1.64 (D5); also elsewhere on the board
D6: U1.63 (D6); also elsewhere on the board
D7: U1.62 (D7); also elsewhere on the board
D8: U1.61 (D8); also elsewhere on the board
D9: U1.60 (D9); also elsewhere on the board
D10: U1.59 (D10); also elsewhere on the board
D11: U1.58 (D11); also elsewhere on the board
D12: U1.57 (D12); also elsewhere on the board
D13: U1.56 (D13); also elsewhere on the board
D14: U1.55 (D14); also elsewhere on the board
D15: U1.54 (D15); also elsewhere on the board
FC0: U1.28 (FC0); also elsewhere on the board
FC1: U1.27 (FC1); also elsewhere on the board
FC2: U1.26 (FC2); also elsewhere on the board
GND: C16.2, C17.2, U1.16 (GND), U1.53 (GND); also elsewhere on the board
unnamed: R2.2, U1.12 (BGACK)
unnamed: R1.2, U1.13 (BR)
R/W: U1.9 (R/W); also elsewhere on the board
/AS: U1.6 (AS); also elsewhere on the board
/BERR: U1.22 (BERR); also elsewhere on the board
/DTACK: U1.10 (DTACK); also elsewhere on the board
/IPL0: R5.2, U1.25 (IPL0); also elsewhere on the board
/IPL1: R4.2, U1.24 (IPL1); also elsewhere on the board
/IPL2: R3.2, U1.23 (IPL2); also elsewhere on the board
/LDS: U1.8 (LDS); also elsewhere on the board
/RESET: U1.17 (HALT), U1.18 (RESET); also elsewhere on the board
/UDS: U1.7 (UDS); also elsewhere on the board
/VPA: U1.21 (VPA); also elsewhere on the board

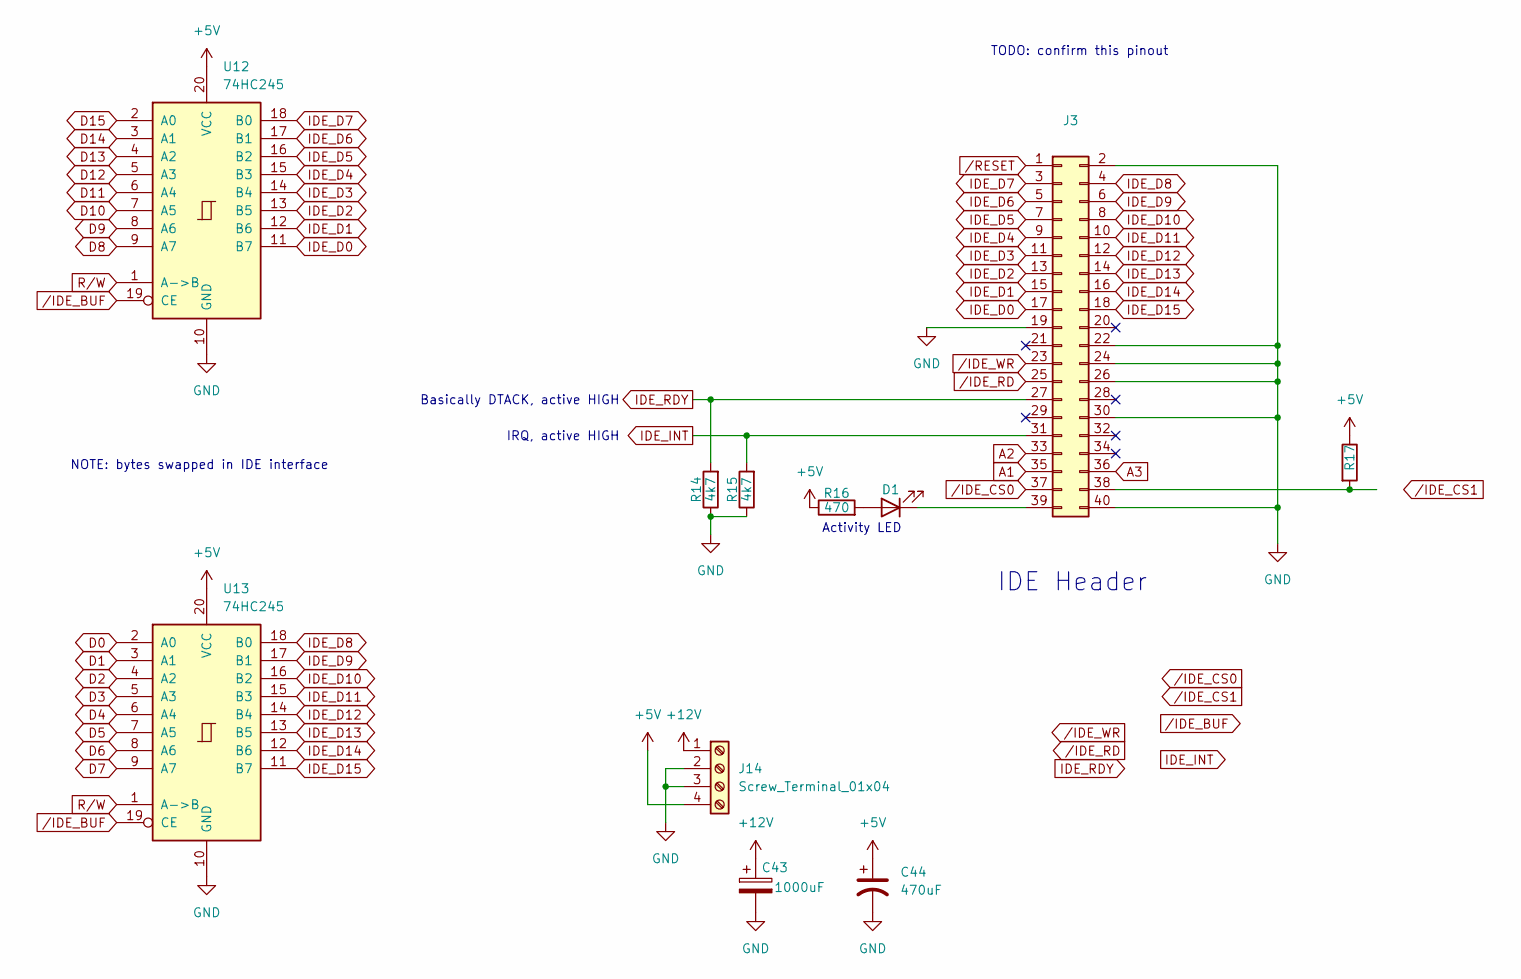
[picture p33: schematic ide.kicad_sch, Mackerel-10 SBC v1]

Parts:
C43: 1000uF; CP_Radial_D10.0mm_P5.00mm
C44: 470uF; CP_Radial_D8.0mm_P3.50mm
D1: LED; LED_D5.0mm
J3: Conn_02x20_Odd_Even; IDC-Header_2x20_P2.54mm_Vertical
J14: Screw_Terminal_01x04; TerminalBlock_bornier-4_P5.08mm
R14, R15: 4k7; R_Axial_DIN0207_L6.3mm_D2.5mm_P7.62mm_Horizontal
R16: 470; R_Axial_DIN0207_L6.3mm_D2.5mm_P7.62mm_Horizontal
R17: R; R_Axial_DIN0207_L6.3mm_D2.5mm_P7.62mm_Horizontal
U12, U13: 74HC245; DIP-20_W7.62mm_Socket

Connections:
+5V: C44.1, J14.4, R16.1, R17.1, U12.20 (VCC), U13.20 (VCC); also elsewhere on the board
+12V: C43.1, J14.1; also elsewhere on the board
A1: J3.35; also elsewhere on the board
A2: J3.33; also elsewhere on the board
A3: J3.36; also elsewhere on the board
D0: U13.2 (A0); also elsewhere on the board
D1: U13.3 (A1); also elsewhere on the board
D2: U13.4 (A2); also elsewhere on the board
D3: U13.5 (A3); also elsewhere on the board
D4: U13.6 (A4); also elsewhere on the board
D5: U13.7 (A5); also elsewhere on the board
D6: U13.8 (A6); also elsewhere on the board
D7: U13.9 (A7); also elsewhere on the board
D8: U12.9 (A7); also elsewhere on the board
D9: U12.8 (A6); also elsewhere on the board
D10: U12.7 (A5); also elsewhere on the board
D11: U12.6 (A4); also elsewhere on the board
D12: U12.5 (A3); also elsewhere on the board
D13: U12.4 (A2); also elsewhere on the board
D14: U12.3 (A1); also elsewhere on the board
D15: U12.2 (A0); also elsewhere on the board
GND: C43.2, C44.2, J3.2, J3.19, J3.22, J3.24, J3.26, J3.30, J3.40, J14.2, J14.3, R14.1, R15.1, U12.10 (GND), U13.10 (GND); also elsewhere on the board
IDE_D0: J3.17, U12.11 (B7)
IDE_D1: J3.15, U12.12 (B6)
IDE_D2: J3.13, U12.13 (B5)
IDE_D3: J3.11, U12.14 (B4)
IDE_D4: J3.9, U12.15 (B3)
IDE_D5: J3.7, U12.16 (B2)
IDE_D6: J3.5, U12.17 (B1)
IDE_D7: J3.3, U12.18 (B0)
IDE_D8: J3.4, U13.18 (B0)
IDE_D9: J3.6, U13.17 (B1)
IDE_D10: J3.8, U13.16 (B2)
IDE_D11: J3.10, U13.15 (B3)
IDE_D12: J3.12, U13.14 (B4)
IDE_D13: J3.14, U13.13 (B5)
IDE_D14: J3.16, U13.12 (B6)
IDE_D15: J3.18, U13.11 (B7)
IDE_INT: J3.31, R15.2
IDE_RDY: J3.27, R14.2
unnamed: D1.2 (A), R16.2
unnamed: D1.1 (K), J3.39
unnamed: J3.38, R17.2
R/W: U12.1 (A->B), U13.1 (A->B); also elsewhere on the board
/IDE_BUF: U12.19 (CE), U13.19 (CE)
/IDE_CS0: J3.37
/IDE_RD: J3.25
/IDE_WR: J3.23
/RESET: J3.1; also elsewhere on the board

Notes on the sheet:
IDE Header
Basically DTACK, active HIGH
NOTE: bytes swapped in IDE interface
TODO: confirm this pinout
Activity LED
IRQ, active HIGH


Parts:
C7, C8: 1000uF; CP_Radial_D10.0mm_P5.00mm
C9: C_Polarized; CP_Radial_D5.0mm_P2.50mm
C22: C; C_Disc_D4.3mm_W1.9mm_P5.00mm
D2, D4: LED; LED_D5.0mm
D3: 1N5822; D_DO-27_P15.24mm_Horizontal
H1, H2, H3, H4: MountingHole_Pad; MountingHole_3.2mm_M3_Pad_Via
HS1: Heatsink; Heatsink_Stonecold_HS-S02_13.21x9.53mm
J6: Barrel_Jack_MountingPin; BarrelJack_Horizontal
J7, J8: Conn_02x03_Odd_Even; PinHeader_2x03_P2.54mm_Vertical
L1: 100uH; L_Radial_D10.0mm_P5.00mm_Fastron_07M
R20: 1k; R_Axial_DIN0207_L6.3mm_D2.5mm_P7.62mm_Horizontal
R21, R22, R23: R; R_Axial_DIN0207_L6.3mm_D2.5mm_P7.62mm_Horizontal
SW1: SW_Push; SW_PUSH_6mm_H5mm
U15: LM2576T-5; TO-220-5_Vertical
U16: NE555P; DIP-8_W7.62mm

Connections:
+5V: C8.1, C9.1, C22.1, J7.1, J7.3, J7.5, L1.2, R20.1, R21.1, R23.1, U15.4 (FB), U16.8 (VCC); also elsewhere on the board
+12V: C7.1, J6.1, J8.1, J8.3, J8.5, U15.1 (VIN); also elsewhere on the board
GND: C7.2, C8.2, C22.2, D2.1 (K), D3.2 (A), H1.1, H2.1, H3.1, H4.1, J6.2, J7.2, J7.4, J7.6, J8.2, J8.4, J8.6, R22.2, SW1.1, U15.3 (GND), U15.5 (~ON/OFF), U16.1 (GND); also elsewhere on the board
unnamed: D2.2 (A), R20.2
unnamed: D3.1 (K), L1.1, U15.2 (OUT)
unnamed: D4.2 (A), R23.2
unnamed: R21.2, SW1.2, U16.4 (R)
unnamed: C9.2, R22.1, U16.2 (TR), U16.6 (THR)
/RESET: D4.1 (K), U16.3 (Q); also elsewhere on the board

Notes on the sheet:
TODO: power switch?


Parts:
C18, C19, C20, C21: C; C_Disc_D4.3mm_W1.9mm_P5.00mm
U3, U5: SST39SF040; DIP-32_W15.24mm
U4, U6: AS6C4008-55PCN; DIP-32_W15.24mm

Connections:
+5V: C18.1, C19.1, C20.1, C21.1, U3.31 (PGM), U3.32 (VCC), U4.32 (VCC), U5.31 (PGM), U5.32 (VCC), U6.32 (VCC); also elsewhere on the board
A1: U3.12 (A0), U4.12 (A0), U5.12 (A0), U6.12 (A0); also elsewhere on the board
A2: U3.11 (A1), U4.11 (A1), U5.11 (A1), U6.11 (A1); also elsewhere on the board
A3: U3.10 (A2), U4.10 (A2), U5.10 (A2), U6.10 (A2); also elsewhere on the board
A4: U3.9 (A3), U4.9 (A3), U5.9 (A3), U6.9 (A3); also elsewhere on the board
A5: U3.8 (A4), U4.8 (A4), U5.8 (A4), U6.8 (A4); also elsewhere on the board
A6: U3.7 (A5), U4.7 (A5), U5.7 (A5), U6.7 (A5); also elsewhere on the board
A7: U3.6 (A6), U4.6 (A6), U5.6 (A6), U6.6 (A6); also elsewhere on the board
A8: U3.5 (A7), U4.5 (A7), U5.5 (A7), U6.5 (A7); also elsewhere on the board
A9: U3.27 (A8), U4.27 (A8), U5.27 (A8), U6.27 (A8); also elsewhere on the board
A10: U3.26 (A9), U4.26 (A9), U5.26 (A9), U6.26 (A9); also elsewhere on the board
A11: U3.23 (A10), U4.23 (A10), U5.23 (A10), U6.23 (A10); also elsewhere on the board
A12: U3.25 (A11), U4.25 (A11), U5.25 (A11), U6.25 (A11); also elsewhere on the board
A13: U3.4 (A12), U4.4 (A12), U5.4 (A12), U6.4 (A12); also elsewhere on the board
A14: U3.28 (A13), U4.28 (A13), U5.28 (A13), U6.28 (A13); also elsewhere on the board
A15: U3.29 (A14), U4.3 (A14), U5.29 (A14), U6.3 (A14); also elsewhere on the board
A16: U3.3 (A15), U4.31 (A15), U5.3 (A15), U6.31 (A15); also elsewhere on the board
A17: U3.2 (A16), U4.2 (A16), U5.2 (A16), U6.2 (A16); also elsewhere on the board
A18: U3.30 (A17), U4.30 (A17), U5.30 (A17), U6.30 (A17); also elsewhere on the board
A19: U3.1 (A18), U4.1 (A18), U5.1 (A18), U6.1 (A18); also elsewhere on the board
D0: U5.13 (D0), U6.13 (DQ0); also elsewhere on the board
D1: U5.14 (D1), U6.14 (DQ1); also elsewhere on the board
D2: U5.15 (D2), U6.15 (DQ2); also elsewhere on the board
D3: U5.17 (D3), U6.17 (DQ3); also elsewhere on the board
D4: U5.18 (D4), U6.18 (DQ4); also elsewhere on the board
D5: U5.19 (D5), U6.19 (DQ5); also elsewhere on the board
D6: U5.20 (D6), U6.20 (DQ6); also elsewhere on the board
D7: U5.21 (D7), U6.21 (DQ7); also elsewhere on the board
D8: U3.13 (D0), U4.13 (DQ0); also elsewhere on the board
D9: U3.14 (D1), U4.14 (DQ1); also elsewhere on the board
D10: U3.15 (D2), U4.15 (DQ2); also elsewhere on the board
D11: U3.17 (D3), U4.17 (DQ3); also elsewhere on the board
D12: U3.18 (D4), U4.18 (DQ4); also elsewhere on the board
D13: U3.19 (D5), U4.19 (DQ5); also elsewhere on the board
D14: U3.20 (D6), U4.20 (DQ6); also elsewhere on the board
D15: U3.21 (D7), U4.21 (DQ7); also elsewhere on the board
GND: C18.2, C19.2, C20.2, C21.2, U3.16 (GND), U3.24 (OE), U4.16 (VSS), U4.24 (OE#), U5.16 (GND), U5.24 (OE), U6.16 (VSS), U6.24 (OE#); also elsewhere on the board
R/W: U4.29 (WE#), U6.29 (WE#); also elsewhere on the board
/ROM_LOWER: U5.22 (CE); also elsewhere on the board
/ROM_UPPER: U3.22 (CE); also elsewhere on the board
/SRAM_LOWER: U6.22 (CE#); also elsewhere on the board
/SRAM_UPPER: U4.22 (CE#); also elsewhere on the board

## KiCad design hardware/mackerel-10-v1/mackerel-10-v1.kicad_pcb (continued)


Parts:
C23, C24: C; C_Disc_D4.3mm_W1.9mm_P5.00mm
J4, J5: Conn_01x06; PinSocket_1x06_P2.54mm_Vertical
R18, R19: R; R_Axial_DIN0207_L6.3mm_D2.5mm_P7.62mm_Horizontal
U14: XR68C681; PLCC-44_THT-Socket
X3: 3.6864MHz; Oscillator_DIP-8

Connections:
+5V: C23.1, C24.1, R18.2, R19.2, U14.44 (VCC), X3.8 (Vcc); also elsewhere on the board
A1: U14.2 (A1); also elsewhere on the board
A2: U14.4 (A2); also elsewhere on the board
A3: U14.6 (A3); also elsewhere on the board
A4: U14.7 (A4); also elsewhere on the board
D0: U14.28 (D0); also elsewhere on the board
D1: U14.18 (D1); also elsewhere on the board
D2: U14.27 (D2); also elsewhere on the board
D3: U14.19 (D3); also elsewhere on the board
D4: U14.26 (D4); also elsewhere on the board
D5: U14.20 (D5); also elsewhere on the board
D6: U14.25 (D6); also elsewhere on the board
D7: U14.21 (D7); also elsewhere on the board
GND: C23.2, C24.2, J4.1, J5.1, U14.3 (IP3), U14.5 (IP1), U14.8 (IP0), U14.22 (GND), U14.40 (IP2), U14.42 (IP5), U14.43 (IP4), X3.4 (GND); also elsewhere on the board
unnamed: U14.36 (X1/CLK), X3.5 (OUT)
RXA: J4.4, U14.35 (RXDA)
RXB: J5.4, U14.11 (RXDB)
R/W: U14.9 (/RW); also elsewhere on the board
TXA: J4.5, U14.33 (TXDA)
TXB: J5.5, U14.13 (TXDB)
/DTACK_DUART: U14.10 (/DTACK); also elsewhere on the board
/DUART: U14.39 (CS); also elsewhere on the board
/IACK_DUART: R18.1, U14.41 (/IACK); also elsewhere on the board
/IRQ_DUART: R19.1, U14.24 (INTR); also elsewhere on the board
/RESET: U14.38 (/RESET); also elsewhere on the board
/RTSA: J4.2, U14.32 (OP0)
/RTSB: J5.2, U14.14 (OP1)


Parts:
C1, C2, C3, C4: 470uF; CP_Radial_D8.0mm_P3.50mm
C5, C6, C10, C11, C12, C13, C14, C15, C33, C34, C35, C36, C37, C38, C39, C40: C; C_Disc_D4.3mm_W1.9mm_P5.00mm
J2: Conn_02x05_Odd_Even; IDC-Header_2x05_P2.54mm_Vertical
R10, R11, R12, R13: R; R_Axial_DIN0207_L6.3mm_D2.5mm_P7.62mm_Horizontal
U7, U8, U9, U10: SIMM-30
U11: PLCC-84_THT-Socket

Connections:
+5V: C1.1, C2.1, C3.1, C4.1, C5.1, C6.1, C10.1, C11.1, C12.2, C13.2, C14.2, C15.2, C33.1, C34.1, C35.1, C36.1, C37.2, C38.2, C39.2, C40.2, J2.4, R10.1, R11.1, R12.1, U7.1 (VCC), U7.30 (VCC), U8.1 (VCC), U8.30 (VCC), U9.1 (VCC), U9.30 (VCC), U10.1 (VCC), U10.30 (VCC), U11.3 (VCCINT), U11.13 (VCCIO), U11.26 (VCCIO), U11.38 (VCCIO), U11.43 (VCCINT), U11.53 (VCCIO), U11.66 (VCCIO), U11.78 (VCCIO); also elsewhere on the board
A1: U11.45 (IO); also elsewhere on the board
A2: U11.46 (IO); also elsewhere on the board
A3: U11.48 (IO); also elsewhere on the board
A4: U11.49 (IO); also elsewhere on the board
A5: U11.50 (IO); also elsewhere on the board
A6: U11.51 (IO); also elsewhere on the board
A7: U11.52 (IO); also elsewhere on the board
A8: U11.54 (IO); also elsewhere on the board
A9: U11.55 (IO); also elsewhere on the board
A10: U11.56 (IO); also elsewhere on the board
A11: U11.57 (IO); also elsewhere on the board
A12: U11.58 (IO); also elsewhere on the board
A13: U11.60 (IO); also elsewhere on the board
A14: U11.61 (IO); also elsewhere on the board
A15: U11.63 (IO); also elsewhere on the board
A16: U11.64 (IO); also elsewhere on the board
A17: U11.65 (IO); also elsewhere on the board
A18: U11.67 (IO); also elsewhere on the board
A19: U11.68 (IO); also elsewhere on the board
A20: U11.69 (IO); also elsewhere on the board
A21: U11.70 (IO); also elsewhere on the board
A22: U11.73 (IO); also elsewhere on the board
A23: U11.74 (IO); also elsewhere on the board
CASA0: U9.2 (/CAS), U11.20 (IO)
CASA1: U10.2 (/CAS), U11.21 (IO)
CASB0: U7.2 (/CAS), U11.18 (IO)
CASB1: U8.2 (/CAS), U11.22 (IO)
CLK_ALT: U11.2 (OE2/GCLK2); also elsewhere on the board
CLK_SRC: U11.83 (GCLK1); also elsewhere on the board
D0: U7.3 (DQ0), U9.3 (DQ0); also elsewhere on the board
D1: U7.6 (DQ1), U9.6 (DQ1); also elsewhere on the board
D2: U7.10 (DQ2), U9.10 (DQ2); also elsewhere on the board
D3: U7.13 (DQ3), U9.13 (DQ3); also elsewhere on the board
D4: U7.16 (DQ4), U9.16 (DQ4); also elsewhere on the board
D5: U7.20 (DQ5), U9.20 (DQ5); also elsewhere on the board
D6: U7.23 (DQ6), U9.23 (DQ6); also elsewhere on the board
D7: U7.25 (DQ7), U9.25 (DQ7); also elsewhere on the board
D8: U8.3 (DQ0), U10.3 (DQ0); also elsewhere on the board
D9: U8.6 (DQ1), U10.6 (DQ1); also elsewhere on the board
D10: U8.10 (DQ2), U10.10 (DQ2); also elsewhere on the board
D11: U8.13 (DQ3), U10.13 (DQ3); also elsewhere on the board
D12: U8.16 (DQ4), U10.16 (DQ4); also elsewhere on the board
D13: U8.20 (DQ5), U10.20 (DQ5); also elsewhere on the board
D14: U8.23 (DQ6), U10.23 (DQ6); also elsewhere on the board
D15: U8.25 (DQ7), U10.25 (DQ7); also elsewhere on the board
GND: C1.2, C2.2, C3.2, C4.2, C5.2, C6.2, C10.2, C11.2, C12.1, C13.1, C14.1, C15.1, C33.2, C34.2, C35.2, C36.2, C37.1, C38.1, C39.1, C40.1, J2.2, J2.10, R13.2, U7.9 (GND), U7.22 (GND), U8.9 (GND), U8.22 (GND), U9.9 (GND), U9.22 (GND), U10.9 (GND), U10.22 (GND), U11.1 (GCLRn), U11.7 (GND), U11.19 (GND), U11.32 (GND), U11.42 (GND), U11.47 (GND), U11.59 (GND), U11.72 (GND), U11.82 (GND), U11.84 (OE1); also elsewhere on the board
RAMWRA: U9.21 (/WE), U10.21 (/WE), U11.80 (IO)
RAMWRB: U7.21 (/WE), U8.21 (/WE), U11.81 (IO)
RAM_A0: U7.4 (A0), U8.4 (A0), U9.4 (A0), U10.4 (A0), U11.17 (IO)
RAM_A1: U7.5 (A1), U8.5 (A1), U9.5 (A1), U10.5 (A1), U11.16 (IO)
RAM_A2: U7.7 (A2), U8.7 (A2), U9.7 (A2), U10.7 (A2), U11.15 (IO)
RAM_A3: U7.8 (A3), U8.8 (A3), U9.8 (A3), U10.8 (A3), U11.12 (IO)
RAM_A4: U7.11 (A4), U8.11 (A4), U9.11 (A4), U10.11 (A4), U11.11 (IO)
RAM_A5: U7.12 (A5), U8.12 (A5), U9.12 (A5), U10.12 (A5), U11.10 (IO)
RAM_A6: U7.14 (A6), U8.14 (A6), U9.14 (A6), U10.14 (A6), U11.9 (IO)
RAM_A7: U7.15 (A7), U8.15 (A7), U9.15 (A7), U10.15 (A7), U11.8 (IO)
RAM_A8: U7.17 (A8), U8.17 (A8), U9.17 (A8), U10.17 (A8), U11.6 (IO)
RAM_A9: U7.18 (A9), U8.18 (A9), U9.18 (A9), U10.18 (A9), U11.5 (IO)
RAM_A10: U7.19 (A10), U8.19 (A10), U9.19 (A10), U10.19 (A10), U11.4 (IO)
RAM_A11: U7.24 (A11), U8.24 (A11), U9.24 (A11), U10.24 (A11), U11.79 (IO)
RASA: U9.27 (/RAS), U10.27 (/RAS), U11.75 (IO)
RASB: U7.27 (/RAS), U8.27 (/RAS), U11.77 (IO)
R/W: U11.39 (IO); also elsewhere on the board
TCK_DRAM: J2.1, R13.1, U11.62 (TCK)
TDI_DRAM: J2.9, R12.2, U11.14 (TDI)
TDO_DRAM: J2.3, R10.2, U11.71 (TDO)
TMS_DRAM: J2.5, R11.2, U11.23 (TMS)
/AS: U11.44 (IO); also elsewhere on the board
/CS_DRAM: U11.24 (IO); also elsewhere on the board
/DTACK_DRAM: U11.25 (IO); also elsewhere on the board
/LDS: U11.40 (IO); also elsewhere on the board
/RESET: U11.76 (IO); also elsewhere on the board
/UDS: U11.41 (IO); also elsewhere on the board

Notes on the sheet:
TODO: add some test points!
TODO: add two more RAM sticks?


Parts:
J9: Conn_02x20_Odd_Even; IDC-Header_2x20_P2.54mm_Vertical

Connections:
+5V: J9.1, J9.2; also elsewhere on the board
A1: J9.13; also elsewhere on the board
A2: J9.14; also elsewhere on the board
A3: J9.15; also elsewhere on the board
A4: J9.16; also elsewhere on the board
A5: J9.17; also elsewhere on the board
A6: J9.18; also elsewhere on the board
A7: J9.19; also elsewhere on the board
A8: J9.20; also elsewhere on the board
A9: J9.23; also elsewhere on the board
A10: J9.24; also elsewhere on the board
A11: J9.25; also elsewhere on the board
A12: J9.26; also elsewhere on the board
A13: J9.27; also elsewhere on the board
A14: J9.28; also elsewhere on the board
A15: J9.29; also elsewhere on the board
D0: J9.5; also elsewhere on the board
D1: J9.6; also elsewhere on the board
D2: J9.7; also elsewhere on the board
D3: J9.8; also elsewhere on the board
D4: J9.9; also elsewhere on the board
D5: J9.10; also elsewhere on the board
D6: J9.11; also elsewhere on the board
D7: J9.12; also elsewhere on the board
GND: J9.3, J9.4, J9.21, J9.22; also elsewhere on the board

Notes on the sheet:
TODO: LDS and UDS?


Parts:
C25, C26, C27, C28, C29, C30, C31, C32, C41, C42: C; C_Disc_D4.3mm_W1.9mm_P5.00mm
J1: Conn_02x05_Odd_Even; IDC-Header_2x05_P2.54mm_Vertical
R6, R7, R8, R9: R; R_Axial_DIN0207_L6.3mm_D2.5mm_P7.62mm_Horizontal
U2: PLCC-84_THT-Socket
X1, X2: 50MHz; Oscillator_DIP-14

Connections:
+5V: C25.1, C26.1, C27.1, C28.1, C29.2, C30.2, C31.2, C32.2, C41.2, C42.2, J1.4, R6.1, R7.1, R8.1, U2.3 (VCCINT), U2.13 (VCCIO), U2.26 (VCCIO), U2.38 (VCCIO), U2.43 (VCCINT), U2.53 (VCCIO), U2.66 (VCCIO), U2.78 (VCCIO), X1.14 (Vcc), X2.14 (Vcc); also elsewhere on the board
A1: U2.18 (IO); also elsewhere on the board
A2: U2.20 (IO); also elsewhere on the board
A3: U2.21 (IO); also elsewhere on the board
A4: U2.22 (IO); also elsewhere on the board
A14: U2.17 (IO); also elsewhere on the board
A15: U2.16 (IO); also elsewhere on the board
A16: U2.15 (IO); also elsewhere on the board
A17: U2.12 (IO); also elsewhere on the board
A18: U2.11 (IO); also elsewhere on the board
A19: U2.10 (IO); also elsewhere on the board
A20: U2.9 (IO); also elsewhere on the board
A21: U2.8 (IO); also elsewhere on the board
A22: U2.6 (IO); also elsewhere on the board
A23: U2.5 (IO); also elsewhere on the board
CLK_ALT: U2.2 (OE2/GCLK2), X2.8 (OUT); also elsewhere on the board
CLK_CPU: U2.52 (IO); also elsewhere on the board
CLK_SRC: U2.83 (GCLK1), X1.8 (OUT); also elsewhere on the board
D0: U2.65 (IO); also elsewhere on the board
D1: U2.67 (IO); also elsewhere on the board
D2: U2.68 (IO); also elsewhere on the board
D3: U2.69 (IO); also elsewhere on the board
D4: U2.70 (IO); also elsewhere on the board
D5: U2.64 (IO); also elsewhere on the board
D6: U2.61 (IO); also elsewhere on the board
D7: U2.58 (IO); also elsewhere on the board
FC0: U2.40 (IO); also elsewhere on the board
FC1: U2.41 (IO); also elsewhere on the board
FC2: U2.44 (IO); also elsewhere on the board
GND: C25.2, C26.2, C27.2, C28.2, C29.1, C30.1, C31.1, C32.1, C41.1, C42.1, J1.2, J1.10, R9.2, U2.1 (GCLRn), U2.7 (GND), U2.19 (GND), U2.32 (GND), U2.42 (GND), U2.47 (GND), U2.59 (GND), U2.72 (GND), U2.82 (GND), U2.84 (OE1), X1.7 (GND), X2.7 (GND); also elsewhere on the board
R/W: U2.56 (IO); also elsewhere on the board
TCK: J1.1, R9.1, U2.62 (TCK)
TDI: J1.9, R8.2, U2.14 (TDI)
TDO: J1.3, R6.2, U2.71 (TDO)
TMS: J1.5, R7.2, U2.23 (TMS)
/AS: U2.63 (IO); also elsewhere on the board
/BERR: U2.50 (IO); also elsewhere on the board
/CS_DRAM: U2.54 (IO); also elsewhere on the board
/DTACK: U2.51 (IO); also elsewhere on the board
/DTACK_DRAM: U2.55 (IO); also elsewhere on the board
/DTACK_DUART: U2.81 (IO); also elsewhere on the board
/DUART: U2.79 (IO); also elsewhere on the board
/IACK_DUART: U2.80 (IO); also elsewhere on the board
/IPL0: U2.46 (IO); also elsewhere on the board
/IPL1: U2.45 (IO); also elsewhere on the board
/IPL2: U2.48 (IO); also elsewhere on the board
/IRQ_DUART: U2.77 (IO); also elsewhere on the board
/LDS: U2.57 (IO); also elsewhere on the board
/RESET: U2.4 (IO); also elsewhere on the board
/ROM_LOWER: U2.73 (IO); also elsewhere on the board
/ROM_UPPER: U2.75 (IO); also elsewhere on the board
/SRAM_LOWER: U2.76 (IO); also elsewhere on the board
/SRAM_UPPER: U2.74 (IO); also elsewhere on the board
/UDS: U2.60 (IO); also elsewhere on the board
/VPA: U2.49 (IO); also elsewhere on the board

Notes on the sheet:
TODO: how many address pins are actually needed for decoding?
SPI and I2C expansion
TODO: SPI and I2C headers TODO: enough room on CPLD for this logic?
TODO: GPIO with leftover pins
TODO: user LED
TODO: control lines for IDE, DRAM, and expansion


Board: 4 copper layers, 210.0 x 170.0 mm, 107 parts (0 on the bottom side), 133 nets.

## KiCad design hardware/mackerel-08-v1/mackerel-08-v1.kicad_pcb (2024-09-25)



Board: 4 copper layers, 180.0 x 120.0 mm, 85 parts (23 on the bottom side), 96 nets.

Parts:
C1, C2, C3, C4, C5, C6, C7, C8, C9, C10, C11, C12, C13, C14, C15, C16, C17: C; C_Disc_D4.3mm_W1.9mm_P5.00mm
C18, C19: 1000uF; CP_Radial_D10.0mm_P5.00mm
C20, C21, C22: C_Polarized; CP_Radial_D5.0mm_P2.50mm
D1, D2, D4: LED; LED_D5.0mm
D3: 1N5822; D_DO-27_P15.24mm_Horizontal
H1, H2, H3, H4: MountingHole; MountingHole_3.2mm_M3_Pad
HS1: Heatsink; Heatsink_Stonecold_HS-S02_13.21x9.53mm
J1: Conn_01x08; PinSocket_1x08_P2.54mm_Vertical
J2: Conn_02x09_Odd_Even; PinHeader_2x09_P2.54mm_Vertical
J3, J4: Conn_01x06; PinSocket_1x06_P2.54mm_Horizontal
J5: Barrel_Jack_MountingPin; BarrelJack_Horizontal
J6, J7, J10: Conn_02x03_Odd_Even; PinHeader_2x03_P2.54mm_Vertical
J8: Conn_02x20_Odd_Even; IDC-Header_2x20_P2.54mm_Vertical
J9: Conn_02x10_Odd_Even; IDC-Header_2x10_P2.54mm_Vertical
L1: 100uH; L_Radial_D10.0mm_P5.00mm_Fastron_07M
R1, R2, R3, R4, R5, R6, R7, R8, R9, R10, R11, R12, R13, R14, R15, R16, R17, R18, R19, R20, R21, R22, R23: R; R_1206_3216Metric_Pad1.30x1.75mm_HandSolder
SW1: SW_Push; SW_PUSH_6mm_H5mm
U1: MC68008; PLCC-52_THT-Socket
U2: 74HC595; DIP-16_W7.62mm
U3, U4, U5: ATF22V10C; DIP-24_W7.62mm
U6, U7, U8, U9, U10, U11, U12: AS6C4008-55PCN; DIP-32_W15.24mm
U13: SST39SF040; DIP_Socket-32_W11.9_W12.7_W15.24_W17.78_W18.5_3M_232-1285-0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
U14: XR68C681; PLCC-44_THT-Socket
U15: LM2576T-5; TO-220-5_Vertical
U16: NE555P; DIP-8_W7.62mm
U17: TO-252-2
X1, X2: CXO_DIP14; Oscillator_DIP-14

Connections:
+3.3V: C22.1, J2.3, J2.4, J10.1, J10.3, J10.5, U17.2 (Vout)
+5V: C1.1, C2.1, C3.1, C4.1, C5.1, C6.1, C7.1, C8.1, C9.1, C10.1, C11.1, C12.1, C13.1, C14.1, C15.1, C16.1, C17.1, C19.1, C20.1, C21.1, J1.1, J2.1, J2.2, J6.1, J6.3, J6.5, J8.1, J8.2, J9.1, J9.2, L1.2, R1.2, R2.2, R3.2, R4.2, R5.2, R6.2, R7.2, R8.1, R10.1, R11.1, R12.2, R16.2, R17.2, R18.2, R19.2, R20.1, R21.1, R23.1, U1.15 (VCC), U2.14 (SER), U2.16 (VCC), U3.24 (vcc), U4.24 (vcc), U5.24 (vcc), U6.32 (VCC), U7.32 (VCC), U8.32 (VCC), U9.32 (VCC), U10.32 (VCC), U11.32 (VCC), U12.32 (VCC), U13.31 (/WE), U13.32 (VCC), U14.44 (VCC), U15.4 (FB), U16.8 (VCC), U17.3 (Vin), X1.14 (Vcc), X2.14 (Vcc)
/Mackerel-08 DUART/USR_LED: R15.1, U14.17 (OP7)
A0: J8.13, U1.51 (A0), U6.12 (A0), U7.12 (A0), U8.12 (A0), U9.12 (A0), U10.12 (A0), U11.12 (A0), U12.12 (A0), U13.12 (A0)
A1: J8.14, U1.52 (A1), U5.10 (IN9), U6.11 (A1), U7.11 (A1), U8.11 (A1), U9.11 (A1), U10.11 (A1), U11.11 (A1), U12.11 (A1), U13.11 (A1), U14.2 (A1)
A2: J8.15, U1.1 (A2), U5.11 (IN10), U6.10 (A2), U7.10 (A2), U8.10 (A2), U9.10 (A2), U10.10 (A2), U11.10 (A2), U12.10 (A2), U13.10 (A2), U14.4 (A2)
A3: J8.16, U1.2 (A3), U5.13 (IN11), U6.9 (A3), U7.9 (A3), U8.9 (A3), U9.9 (A3), U10.9 (A3), U11.9 (A3), U12.9 (A3), U13.9 (A3), U14.6 (A3)
A4: J8.17, U1.3 (A4), U6.8 (A4), U7.8 (A4), U8.8 (A4), U9.8 (A4), U10.8 (A4), U11.8 (A4), U12.8 (A4), U13.8 (A4), U14.7 (A4)
A5: J8.18, U1.4 (A5), U6.7 (A5), U7.7 (A5), U8.7 (A5), U9.7 (A5), U10.7 (A5), U11.7 (A5), U12.7 (A5), U13.7 (A5)
A6: J8.19, U1.5 (A6), U6.6 (A6), U7.6 (A6), U8.6 (A6), U9.6 (A6), U10.6 (A6), U11.6 (A6), U12.6 (A6), U13.6 (A6)
A7: J8.20, U1.6 (A7), U6.5 (A7), U7.5 (A7), U8.5 (A7), U9.5 (A7), U10.5 (A7), U11.5 (A7), U12.5 (A7), U13.5 (A7)
A8: J8.23, U1.7 (A8), U6.27 (A8), U7.27 (A8), U8.27 (A8), U9.27 (A8), U10.27 (A8), U11.27 (A8), U12.27 (A8), U13.27 (A8)
A9: J8.24, U1.8 (A9), U6.26 (A9), U7.26 (A9), U8.26 (A9), U9.26 (A9), U10.26 (A9), U11.26 (A9), U12.26 (A9), U13.26 (A9)
A10: J8.25, U1.9 (A10), U6.23 (A10), U7.23 (A10), U8.23 (A10), U9.23 (A10), U10.23 (A10), U11.23 (A10), U12.23 (A10), U13.23 (A10)
A11: J8.26, U1.10 (A11), U6.25 (A11), U7.25 (A11), U8.25 (A11), U9.25 (A11), U10.25 (A11), U11.25 (A11), U12.25 (A11), U13.25 (A11)
A12: J8.27, U1.11 (A12), U6.4 (A12), U7.4 (A12), U8.4 (A12), U9.4 (A12), U10.4 (A12), U11.4 (A12), U12.4 (A12), U13.4 (A12)
A13: J8.28, U1.12 (A13), U3.4 (IN3/PD), U6.28 (A13), U7.28 (A13), U8.28 (A13), U9.28 (A13), U10.28 (A13), U11.28 (A13), U12.28 (A13), U13.28 (A13)
A14: J8.29, U1.14 (A14), U3.5 (IN4), U6.3 (A14), U7.3 (A14), U8.3 (A14), U9.3 (A14), U10.3 (A14), U11.3 (A14), U12.3 (A14), U13.29 (A14)
A15: J8.30, U1.16 (A15), U3.6 (IN5), U6.31 (A15), U7.31 (A15), U8.31 (A15), U9.31 (A15), U10.31 (A15), U11.31 (A15), U12.31 (A15), U13.3 (A15)
A16: J9.13, U1.18 (A16), U3.7 (IN6), U6.2 (A16), U7.2 (A16), U8.2 (A16), U9.2 (A16), U10.2 (A16), U11.2 (A16), U12.2 (A16), U13.2 (A16)
A17: J9.14, U1.19 (A17), U3.8 (IN7), U6.30 (A17), U7.30 (A17), U8.30 (A17), U9.30 (A17), U10.30 (A17), U11.30 (A17), U12.30 (A17), U13.30 (A17)
A18: J9.15, U1.20 (A18), U3.9 (IN8), U6.1 (A18), U7.1 (A18), U8.1 (A18), U9.1 (A18), U10.1 (A18), U11.1 (A18), U12.1 (A18), U13.1 (A18)
A19: J9.16, U1.21 (A19), U3.10 (IN9)
A20: J9.17, U1.22 (A20), U3.11 (IN10)
A21: J9.18, U1.13 (A21), U3.13 (IN11)
AS: U4.1 (CLK/IN0), U5.17 (IO3)
BOOT: U2.7 (QH), U3.1 (CLK/IN0)
CLK_CPU: J9.5, U1.38 (CLK), X1.8 (OUT)
D0: J8.5, U1.30 (D0), U6.13 (DQ0), U7.13 (DQ0), U8.13 (DQ0), U9.13 (DQ0), U10.13 (DQ0), U11.13 (DQ0), U12.13 (DQ0), U13.13 (D0), U14.28 (D0)
D1: J8.6, U1.29 (D1), U6.14 (DQ1), U7.14 (DQ1), U8.14 (DQ1), U9.14 (DQ1), U10.14 (DQ1), U11.14 (DQ1), U12.14 (DQ1), U13.14 (D1), U14.18 (D1)
D2: J8.7, U1.28 (D2), U6.15 (DQ2), U7.15 (DQ2), U8.15 (DQ2), U9.15 (DQ2), U10.15 (DQ2), U11.15 (DQ2), U12.15 (DQ2), U13.15 (D2), U14.27 (D2)
D3: J8.8, U1.27 (D3), U6.17 (DQ3), U7.17 (DQ3), U8.17 (DQ3), U9.17 (DQ3), U10.17 (DQ3), U11.17 (DQ3), U12.17 (DQ3), U13.17 (D3), U14.19 (D3)
D4: J8.9, U1.26 (D4), U6.18 (DQ4), U7.18 (DQ4), U8.18 (DQ4), U9.18 (DQ4), U10.18 (DQ4), U11.18 (DQ4), U12.18 (DQ4), U13.18 (D4), U14.26 (D4)
D5: J8.10, U1.25 (D5), U6.19 (DQ5), U7.19 (DQ5), U8.19 (DQ5), U9.19 (DQ5), U10.19 (DQ5), U11.19 (DQ5), U12.19 (DQ5), U13.19 (D5), U14.20 (D5)
D6: J8.11, U1.24 (D6), U6.20 (DQ6), U7.20 (DQ6), U8.20 (DQ6), U9.20 (DQ6), U10.20 (DQ6), U11.20 (DQ6), U12.20 (DQ6), U13.20 (D6), U14.25 (D6)
D7: J8.12, U1.23 (D7), U6.21 (DQ7), U7.21 (DQ7), U8.21 (DQ7), U9.21 (DQ7), U10.21 (DQ7), U11.21 (DQ7), U12.21 (DQ7), U13.21 (D7), U14.21 (D7)
E: J9.11, U1.42 (E)
FC0: U1.50 (FC0), U5.1 (CLK/IN0)
FC1: U1.49 (FC1), U5.2 (IN1)
FC2: U1.48 (FC2), U5.3 (IN2)
GND: C1.2, C2.2, C3.2, C4.2, C5.2, C6.2, C7.2, C8.2, C9.2, C10.2, C11.2, C12.2, C13.2, C14.2, C15.2, C16.2, C17.2, C18.2, C19.2, C21.2, C22.2, D1.1 (K), D2.1 (K), D3.2 (A), J1.3, J2.5, J2.6, J3.1, J4.1, J5.2, J6.2, J6.4, J6.6, J7.2, J7.4, J7.6, J8.3, J8.4, J8.21, J8.22, J8.39, J8.40, J9.3, J9.4, J9.19, J9.20, J10.2, J10.4, J10.6, R9.2, R13.1, R14.1, R22.2, SW1.1, U1.17 (GND), U1.39 (GND), U2.8 (GND), U2.13 (~OE), U3.12 (GND), U4.4 (IN3/PD), U4.10 (IN9), U4.11 (IN10), U4.12 (GND), U4.13 (IN11), U5.7 (IN6), U5.8 (IN7), U5.9 (IN8), U5.12 (GND), U6.16 (VSS), U6.24 (OE#), U7.16 (VSS), U7.24 (OE#), U8.16 (VSS), U8.24 (OE#), U9.16 (VSS), U9.24 (OE#), U10.16 (VSS), U10.24 (OE#), U11.16 (VSS), U11.24 (OE#), U12.16 (VSS), U12.24 (OE#), U13.16 (GND), U13.24 (/OE), U14.22 (GND), U15.3 (GND), U15.5 (~ON/OFF), U16.1 (GND), U17.1 (GND), X1.7 (GND), X2.7 (GND)
unnamed: D1.2 (A), R15.2
unnamed: D2.2 (A), R20.2
unnamed: D3.1 (K), L1.1, U15.2 (OUT)
unnamed: D4.2 (A), R23.2
unnamed: U14.36 (X1/CLK), X2.8 (OUT)
unnamed: R21.2, SW1.2, U16.4 (R)
unnamed: C20.2, R22.1, U16.2 (TR), U16.6 (THR)
RXA: J3.4, U14.35 (RXDA)
RXB: J4.4, U14.11 (RXDB)
SD_CD: J1.8, R19.1, U14.42 (IP5)
SD_CS: J1.7, U14.29 (OP6)
SPI_CLK: J1.4, J2.11, J2.12, U14.15 (OP3)
SPI_CS0: J2.13, U14.30 (OP4)
SPI_CS1: J2.14, U14.16 (OP5)
SPI_DI: J1.6, J2.7, J2.8, U14.31 (OP2)
SPI_DO: J1.5, J2.9, J2.10, R18.1, U14.43 (IP4)
SPI_INT0: J2.15, R16.1, U14.40 (IP2)
SPI_INT1: J2.16, R17.1, U14.3 (IP3)
TXA: J3.5, U14.33 (TXDA)
TXB: J4.5, U14.13 (TXDB)
VCC: C18.1, J5.1, J7.1, J7.3, J7.5, U15.1 (VIN)
/AS: J8.33, U1.31 (/AS), U2.11 (SRCLK), U2.12 (RCLK), U3.2 (IN1), U5.4 (IN3/PD)
/BERR: J9.12, R3.1, U1.44 (/BERR)
/BG: J9.7, U1.35 (/BG)
/BGACK: J9.6, R2.1, U1.36 (/BGACK)
/BR: J9.9, R1.1, U1.37 (/BR)
/CTSA: R13.2, U14.8 (IP0)
/CTSB: R14.2, U14.5 (IP1)
/DS: J9.8, U1.32 (/DS)
/DTACK_CPU: R9.1, U1.34 (/DTACK), U4.23 (IO9)
/DTACK_DUART: U4.6 (IN5), U14.10 (/DTACK)
/DTACK_EXP: J8.36, R8.2, U4.7 (IN6)
/DUART: U3.23 (IO9), U4.3 (IN2), U14.39 (CS)
/EXP: J8.35, U3.14 (IO0), U4.5 (IN4)
/IACK: U3.3 (IN2), U5.23 (IO9)
/IACK_DUART: R12.1, U4.9 (IN8), U5.19 (IO5), U14.41 (/IACK)
/IACK_EXP: J8.38, U4.8 (IN7), U5.18 (IO4)
/IPL0: R5.1, U1.47 (/IPL0), U5.22 (IO8)
/IPL1: R6.1, U1.45 (/IPL1), U5.21 (IO7)
/IPL2: R7.1, U1.46 (/IPL2), U5.20 (IO6)
/IRQ_DUART: R11.2, U5.5 (IN4), U14.24 (INTR)
/IRQ_EXP: J8.37, R10.2, U5.6 (IN5)
/RAM0: U3.21 (IO7), U6.22 (CE#)
/RAM1: U3.20 (IO6), U8.22 (CE#)
/RAM2: U3.19 (IO5), U10.22 (CE#)
/RAM3: U3.18 (IO4), U12.22 (CE#)
/RAM4: U3.17 (IO3), U7.22 (CE#)
/RAM5: U3.16 (IO2), U9.22 (CE#)
/RAM6: U3.15 (IO1), U11.22 (CE#)
/RESET: D4.1 (K), J2.17, J2.18, J8.31, J8.32, U1.40 (/HALT), U1.41 (/RESET), U2.10 (~SRCLR), U14.38 (/RESET), U16.3 (Q)
/ROM: U3.22 (IO8), U4.2 (IN1), U13.22 (/CE)
/RTSA: J3.2, U14.32 (OP0)
/RTSB: J4.2, U14.14 (OP1)
/RW: J8.34, U1.33 (/RW), U6.29 (WE#), U7.29 (WE#), U8.29 (WE#), U9.29 (WE#), U10.29 (WE#), U11.29 (WE#), U12.29 (WE#), U14.9 (/RW)
/VPA: J9.10, R4.1, U1.43 (/VPA)

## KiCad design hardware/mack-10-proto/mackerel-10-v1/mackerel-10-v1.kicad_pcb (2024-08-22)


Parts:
C2, C4, C5, C6, C7, C8, C9, C10, C11, C12, C13: 0.1uF; C_Disc_D4.7mm_W2.5mm_P5.00mm
D2, D4, D5: LED; LED_D5.0mm
J1: Conn_02x05_Odd_Even; IDC-Header_2x05_P2.54mm_Vertical
R1, R2, R3, R4, R5, R6, R7, R8, R9, R15, R16, R17: R; R_Axial_DIN0204_L3.6mm_D1.6mm_P5.08mm_Horizontal
U1: 68010D; DIP-64_W22.86mm
U2: PLCC-84_THT-Socket
X1: 50MHz; Oscillator_DIP-14

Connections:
+5V: C2.1, C4.1, C5.1, C6.1, C7.1, C8.1, C9.1, C10.1, C11.1, C12.1, C13.1, J1.4, R1.1, R2.1, R3.1, R4.1, R5.1, R6.1, R7.1, R8.1, U1.14 (VCC), U1.49 (VCC), U2.3 (VCCINT), U2.13 (VCCIO), U2.26 (VCCIO), U2.38 (VCCIO), U2.43 (VCCINT), U2.53 (VCCIO), U2.66 (VCCIO), U2.78 (VCCIO), X1.14 (Vcc); also elsewhere on the board
A1: U1.29 (A1), U2.24 (IO); also elsewhere on the board
A2: U1.30 (A2), U2.21 (IO); also elsewhere on the board
A3: U1.31 (A3), U2.20 (IO); also elsewhere on the board
A4: U1.32 (A4), U2.18 (IO); also elsewhere on the board
A5: U1.33 (A5); also elsewhere on the board
A6: U1.34 (A6); also elsewhere on the board
A7: U1.35 (A7); also elsewhere on the board
A8: U1.36 (A8); also elsewhere on the board
A9: U1.37 (A9); also elsewhere on the board
A10: U1.38 (A10); also elsewhere on the board
A11: U1.39 (A11); also elsewhere on the board
A12: U1.40 (A12); also elsewhere on the board
A13: U1.41 (A13); also elsewhere on the board
A14: U1.42 (A14), U2.16 (IO); also elsewhere on the board
A15: U1.43 (A15), U2.12 (IO); also elsewhere on the board
A16: U1.44 (A16), U2.10 (IO); also elsewhere on the board
A17: U1.45 (A17), U2.11 (IO); also elsewhere on the board
A18: U1.46 (A18), U2.15 (IO); also elsewhere on the board
A19: U1.47 (A19), U2.9 (IO); also elsewhere on the board
A20: U1.48 (A20), U2.64 (IO); also elsewhere on the board
A21: U1.50 (A21), U2.65 (IO); also elsewhere on the board
A22: U1.51 (A22), U2.67 (IO); also elsewhere on the board
A23: U1.52 (A23), U2.68 (IO); also elsewhere on the board
CLK_CPU: U1.15 (CLK), U2.75 (IO); also elsewhere on the board
CLK_SRC: U2.83 (GCLK1), X1.8 (OUT); also elsewhere on the board
D0: U1.5 (D0), U2.27 (IO); also elsewhere on the board
D1: U1.4 (D1), U2.29 (IO); also elsewhere on the board
D2: U1.3 (D2), U2.31 (IO); also elsewhere on the board
D3: U1.2 (D3), U2.33 (IO); also elsewhere on the board
D4: U1.1 (D4), U2.34 (IO); also elsewhere on the board
D5: U1.64 (D5), U2.30 (IO); also elsewhere on the board
D6: U1.63 (D6), U2.28 (IO); also elsewhere on the board
D7: U1.62 (D7), U2.25 (IO); also elsewhere on the board
D8: U1.61 (D8); also elsewhere on the board
D9: U1.60 (D9); also elsewhere on the board
D10: U1.59 (D10); also elsewhere on the board
D11: U1.58 (D11); also elsewhere on the board
D12: U1.57 (D12); also elsewhere on the board
D13: U1.56 (D13); also elsewhere on the board
D14: U1.55 (D14); also elsewhere on the board
D15: U1.54 (D15); also elsewhere on the board
FC0: U1.28 (FC0), U2.76 (IO)
FC1: U1.27 (FC1), U2.77 (IO)
FC2: U1.26 (FC2), U2.79 (IO)
GND: C2.2, C4.2, C5.2, C6.2, C7.2, C8.2, C9.2, C10.2, C11.2, C12.2, C13.2, D2.1 (K), D4.1 (K), D5.1 (K), J1.2, J1.10, R9.2, U1.16 (GND), U1.53 (GND), U2.1 (GCLRn), U2.2 (OE2/GCLK2), U2.7 (GND), U2.19 (GND), U2.32 (GND), U2.42 (GND), U2.47 (GND), U2.59 (GND), U2.72 (GND), U2.82 (GND), U2.84 (OE1), X1.7 (GND); also elsewhere on the board
GPIO_0: U2.46 (IO); also elsewhere on the board
GPIO_1: U2.45 (IO); also elsewhere on the board
GPIO_2: U2.48 (IO); also elsewhere on the board
GPIO_3: U2.49 (IO); also elsewhere on the board
GPIO_4: U2.50 (IO); also elsewhere on the board
GPIO_5: U2.51 (IO); also elsewhere on the board
GPIO_6: U2.52 (IO); also elsewhere on the board
GPIO_7: U2.54 (IO); also elsewhere on the board
unnamed: R15.1, U2.55 (IO)
unnamed: R16.1, U2.56 (IO)
unnamed: R17.1, U2.57 (IO)
unnamed: R2.2, U1.12 (BGACK)
unnamed: R1.2, U1.13 (BR)
R/W: U1.9 (R/W), U2.17 (IO); also elsewhere on the board
TCK: J1.1, R9.1, U2.62 (TCK)
TDI: J1.9, R8.2, U2.14 (TDI)
TDO: J1.3, R6.2, U2.71 (TDO)
TMS: J1.5, R7.2, U2.23 (TMS)
USR0: D5.2 (A), R15.2
USR1: D4.2 (A), R16.2
USR2: D2.2 (A), R17.2
/AS: U1.6 (AS), U2.69 (IO); also elsewhere on the board
/BERR: U1.22 (BERR), U2.5 (IO); also elsewhere on the board
/DTACK: U1.10 (DTACK), U2.74 (IO)
/DTACK_DUART: U2.60 (IO); also elsewhere on the board
/DTACK_EXP: U2.44 (IO); also elsewhere on the board
/DUART: U2.63 (IO); also elsewhere on the board
/EXP: U2.40 (IO); also elsewhere on the board
/IACK_DUART: U2.61 (IO); also elsewhere on the board
/IACK_EXP: U2.41 (IO); also elsewhere on the board
/IPL0: R5.2, U1.25 (IPL0), U2.80 (IO)
/IPL1: R4.2, U1.24 (IPL1), U2.81 (IO)
/IPL2: R3.2, U1.23 (IPL2), U2.4 (IO)
/IRQ_DUART: U2.58 (IO); also elsewhere on the board
/IRQ_EXP: U2.39 (IO); also elsewhere on the board
/LDS: U1.8 (LDS), U2.73 (IO); also elsewhere on the board
/RESET: U1.17 (HALT), U1.18 (RESET), U2.8 (IO); also elsewhere on the board
/ROM_LOWER: U2.36 (IO); also elsewhere on the board
/ROM_UPPER: U2.37 (IO); also elsewhere on the board
/SRAM_LOWER: U2.22 (IO); also elsewhere on the board
/SRAM_UPPER: U2.35 (IO); also elsewhere on the board
/UDS: U1.7 (UDS), U2.70 (IO); also elsewhere on the board
/VPA: U1.21 (VPA), U2.6 (IO); also elsewhere on the board


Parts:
C14, C15, C16, C17: 0.1uF; C_Disc_D4.7mm_W2.5mm_P5.00mm
U3, U5: SST39SF040; DIP-32_W15.24mm
U4, U6: AS6C4008-55PCN; DIP-32_W15.24mm
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

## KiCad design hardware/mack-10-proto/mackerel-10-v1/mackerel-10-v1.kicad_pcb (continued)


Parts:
C18, C19: 0.1uF; C_Disc_D4.7mm_W2.5mm_P5.00mm
J9, J10: Conn_01x06; PinHeader_1x06_P2.54mm_Vertical
R14: R; R_Axial_DIN0204_L3.6mm_D1.6mm_P5.08mm_Horizontal
U7: XR68C681; PLCC-44_THT-Socket
X2: 3.6864MHz; Oscillator_DIP-8

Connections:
+5V: C18.1, C19.1, R14.2, U7.44 (VCC), X2.8 (Vcc); also elsewhere on the board
A1: U7.2 (A1); also elsewhere on the board
A2: U7.4 (A2); also elsewhere on the board
A3: U7.6 (A3); also elsewhere on the board
A4: U7.7 (A4); also elsewhere on the board
D0: U7.28 (D0); also elsewhere on the board
D1: U7.18 (D1); also elsewhere on the board
D2: U7.27 (D2); also elsewhere on the board
D3: U7.19 (D3); also elsewhere on the board
D4: U7.26 (D4); also elsewhere on the board
D5: U7.20 (D5); also elsewhere on the board
D6: U7.25 (D6); also elsewhere on the board
D7: U7.21 (D7); also elsewhere on the board
GND: C18.2, C19.2, J9.1, J10.1, U7.3 (IP3), U7.5 (IP1), U7.8 (IP0), U7.22 (GND), U7.40 (IP2), U7.42 (IP5), U7.43 (IP4), X2.4 (GND); also elsewhere on the board
unnamed: U7.36 (X1/CLK), X2.5 (OUT)
RXA: J9.4, U7.35 (RXDA)
RXB: J10.4, U7.11 (RXDB)
R/W: U7.9 (/RW); also elsewhere on the board
TXA: J9.5, U7.33 (TXDA)
TXB: J10.5, U7.13 (TXDB)
/DTACK_DUART: U7.10 (/DTACK); also elsewhere on the board
/DUART: U7.39 (CS); also elsewhere on the board
/IACK_DUART: R14.1, U7.41 (/IACK); also elsewhere on the board
/IRQ_DUART: U7.24 (INTR); also elsewhere on the board
/RESET: U7.38 (/RESET); also elsewhere on the board

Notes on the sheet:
UART Headers


Board: 4 copper layers, 150.0 x 114.0 mm, 65 parts (0 on the bottom side), 98 nets.

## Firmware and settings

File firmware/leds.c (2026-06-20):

// Baremetal UART echo test: read a byte from the UART, echo it back out.
// The echo is done in C (on the 68k) -- read RBR, write THR -- NOT via the
// 16550's internal loopback. Proves the RX path and the LSR status bits.

#define GPIO_ADDR 0xFFF800

#define UART_BASE 0xFFF900
#define UART_THR  (*(volatile unsigned char *)(UART_BASE + 0))   // write: TX holding
#define UART_RBR  (*(volatile unsigned char *)(UART_BASE + 0))   // read:  RX buffer
#define UART_DLL  (*(volatile unsigned char *)(UART_BASE + 0))   // DLAB=1: divisor low
#define UART_DLM  (*(volatile unsigned char *)(UART_BASE + 2))   // DLAB=1: divisor high
#define UART_FCR  (*(volatile unsigned char *)(UART_BASE + 4))   // write: FIFO control
#define UART_LCR  (*(volatile unsigned char *)(UART_BASE + 6))
#define UART_LSR  (*(volatile unsigned char *)(UART_BASE + 10))

#define LSR_DR    0x01   // data ready: an RX byte is waiting in RBR/FIFO
#define LSR_THRE  0x20   // TX holding register empty: ok to write THR

#define MEM(address) (*(volatile unsigned char *)(address))

static void uart_init(void)
{
    UART_LCR = 0x80;   // DLAB=1 -> divisor latches visible
    UART_DLL = 41;     // 75.6MHz / (16*41) = 115244  (~115200, +0.04%)
    UART_DLM = 0;
    UART_LCR = 0x03;   // DLAB=0, 8 data bits / no parity / 1 stop (8N1)
    UART_FCR = 0x07;   // enable + clear RX & TX FIFOs
}

static void uart_putc(char c)
{
    while (!(UART_LSR & LSR_THRE))   // wait until the TX holding reg is empty
        ;
    UART_THR = c;
}

static unsigned char uart_getc(void)
{
    while (!(UART_LSR & LSR_DR))      // wait until a byte has been received
        ;
    return UART_RBR;
}

static void uart_puts(const char *s)
{
    while (*s)
        uart_putc(*s++);
}

int main(void)
{
    uart_init();
    uart_puts("\r\nMackerel-F UART echo ready\r\n");

    while (1)
    {
        unsigned char c = uart_getc();   // blocks on LSR DR, then reads RBR
        uart_putc(c);                    // echo the byte back out (echo in C)
        if (c == '\r')                   // make Enter behave on the terminal
            uart_putc('\n');
        MEM(GPIO_ADDR) = c;              // show the last received byte on the LEDs
    }

    return 0;
}

void _start(void)
{
    main();
}

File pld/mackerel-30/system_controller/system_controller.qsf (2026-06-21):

# -------------------------------------------------------------------------- #
#
# Copyright (C) 1991-2013 Altera Corporation
# Your use of Altera Corporation's design tools, logic functions 
# and other software and tools, and its AMPP partner logic 
# functions, and any output files from any of the foregoing 
# (including device programming or simulation files), and any 
# associated documentation or information are expressly subject 
# to the terms and conditions of the Altera Program License 
# Subscription Agreement, Altera MegaCore Function License 
# Agreement, or other applicable license agreement, including, 
# without limitation, that your use is for the sole purpose of 
# programming logic devices manufactured by Altera and sold by 
# Altera or its authorized distributors.  Please refer to the 
# applicable agreement for further details.
#
# -------------------------------------------------------------------------- #
#
# Quartus II 64-Bit
# Version 13.0.1 Build 232 06/12/2013 Service Pack 1 SJ Web Edition
# Date created = 19:01:53  November 22, 2024
#
# -------------------------------------------------------------------------- #
#
# Notes:
#
# 1) The default values for assignments are stored in the file:
#		system_controller_assignment_defaults.qdf
#    If this file doesn't exist, see file:
#		assignment_defaults.qdf
#
# 2) Altera recommends that you do not modify this file. This
#    file is updated automatically by the Quartus II software
#    and any changes you make may be lost or overwritten.
#
# -------------------------------------------------------------------------- #


set_global_assignment -name FAMILY MAX7000S
set_global_assignment -name DEVICE "EPM7128SLC84-15"
set_global_assignment -name TOP_LEVEL_ENTITY system_controller
set_global_assignment -name ORIGINAL_QUARTUS_VERSION "13.0 SP1"
set_global_assignment -name PROJECT_CREATION_TIME_DATE "19:01:53  NOVEMBER 22, 2024"
set_global_assignment -name LAST_QUARTUS_VERSION "13.0 SP1"
set_global_assignment -name PROJECT_OUTPUT_DIRECTORY output_files
set_global_assignment -name DEVICE_FILTER_PIN_COUNT 84
set_global_assignment -name DEVICE_FILTER_SPEED_GRADE 15
set_global_assignment -name ERROR_CHECK_FREQUENCY_DIVISOR "-1"
set_global_assignment -name MIN_CORE_JUNCTION_TEMP 0
set_global_assignment -name MAX_CORE_JUNCTION_TEMP 85
set_global_assignment -name MAX7000_DEVICE_IO_STANDARD TTL
set_location_assignment PIN_67 -to AH[31]
set_location_assignment PIN_69 -to AH[30]
set_location_assignment PIN_68 -to AH[29]
set_location_assignment PIN_70 -to AH[28]
set_location_assignment PIN_41 -to AL[3]
set_location_assignment PIN_40 -to AL[2]
set_location_assignment PIN_39 -to AL[1]
set_location_assignment PIN_37 -to AL[0]
set_location_assignment PIN_48 -to AM[19]
set_location_assignment PIN_46 -to AM[18]
set_location_assignment PIN_45 -to AM[17]
set_location_assignment PIN_44 -to AM[16]
set_location_assignment PIN_54 -to AS_n
set_location_assignment PIN_49 -to AVEC_n
set_location_assignment PIN_55 -to BERR_n
set_location_assignment PIN_61 -to CIIN_n
set_location_assignment PIN_83 -to CLK
set_location_assignment PIN_18 -to CS_DUART_n
set_location_assignment PIN_31 -to CS_ROM_n
set_location_assignment PIN_34 -to CS_SRAM_n
set_location_assignment PIN_50 -to DSACK0_n
set_location_assignment PIN_51 -to DSACK1_n
set_location_assignment PIN_56 -to DS_n
set_location_assignment PIN_63 -to FC[2]
set_location_assignment PIN_64 -to FC[1]
set_location_assignment PIN_65 -to FC[0]
set_location_assignment PIN_16 -to IACK_DUART_n
set_location_assignment PIN_75 -to IPL_n[2]
set_location_assignment PIN_76 -to IPL_n[1]
set_location_assignment PIN_77 -to IPL_n[0]
set_location_assignment PIN_4 -to RST_n
set_location_assignment PIN_60 -to RW
set_location_assignment PIN_58 -to SIZ0
set_location_assignment PIN_57 -to SIZ1
set_location_assignment PIN_52 -to STERM_n
set_location_assignment PIN_5 -to P5
set_location_assignment PIN_6 -to P6
set_location_assignment PIN_8 -to P8
set_location_assignment PIN_9 -to P9
set_location_assignment PIN_10 -to ENC_INT_n
set_global_assignment -name VERILOG_FILE irq_encoder.v
set_global_assignment -name VERILOG_FILE boot_signal.v
set_global_assignment -name VERILOG_FILE system_controller.v
set_location_assignment PIN_21 -to IRQ_DUART_n
set_location_assignment PIN_20 -to DTACK_DUART_n
set_location_assignment PIN_35 -to CS_FPU_n
set_location_assignment PIN_24 -to IDE_BUF_n
set_location_assignment PIN_33 -to DSACK0_FPU_n
set_location_assignment PIN_36 -to DSACK1_FPU_n
set_location_assignment PIN_25 -to IDE_CS0_n
set_location_assignment PIN_22 -to IDE_CS1_n
set_location_assignment PIN_27 -to IDE_INT
set_location_assignment PIN_28 -to IDE_RDY
set_location_assignment PIN_29 -to IDE_RD_n
set_location_assignment PIN_30 -to IDE_WR_n
set_location_assignment PIN_73 -to CS_DRAM_n
set_location_assignment PIN_74 -to DSACK0_DRAM_n
set_location_assignment PIN_81 -to DSACK1_DRAM_n
set_location_assignment PIN_79 -to EXP_BUF_n

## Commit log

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2022-09-10 board booting, interrupts not working
    [bootloader.c]
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2022-09-20 Correct RAM and ROM chip select pin
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2022-09-23 Fix strtok bug in load command
    [bootloader.c]
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2022-11-05 Create KiCAD project for Mackerel-08
    [mackerel_08.kicad_pcb, mackerel_08.kicad_sch]
2022-11-06 CPU and decoder board schematic in progress
    [mackerel_08.kicad_pcb, mackerel_08.kicad_sch]
2022-11-15 Stubbed out IACK and DTACK PLDs in schematic
    [mackerel_08.kicad_sch]
2022-11-16 Add memory board schematic
    [mackerel_08.kicad_sch, mackerel_mem.kicad_pcb, mackerel_mem.kicad_sch]
2022-11-16 Add ROM to schematic
    [mackerel_08.kicad_sch]
2022-11-16 Defined system bus pinout and GAL decoding schematic
    [mackerel_08.kicad_pcb, mackerel_08.kicad_sch, mackerel_mem.kicad_pcb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]
2022-11-17 Double DUART board with independent interrupt channels
    [mackerel_08.kicad_sch, mackerel_io.kicad_pcb, mackerel_io.kicad_sch]
2024-06-17 Update the memory map for ROM and RAM bases programs, fix the bootloader addresses
    [bootloader.c]
2024-06-22 clear out old design projects
    [mackerel_08.kicad_pcb, mackerel_08.kicad_sch, mackerel_io.kicad_pcb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]
2024-06-25 Stubbing out KiCAD components and schematic
    [mackerel-08-v1.kicad_pcb, mackerel-08-v1.kicad_sch]
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2024-06-27 Added most of the PLDs to the schematic
    [mackerel-08-v1.kicad_sch]
2024-06-27 Cleaned up the rest of the PLD logic equations and schematic
    [mackerel-08-v1.kicad_sch]
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2024-07-01 Fix interrupt decoding for rev0
2024-07-02 Full interrupt and IACK decoding in PLD
    [mackerel-08-v1.kicad_pcb, mackerel-08-v1.kicad_sch]
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2024-07-23 Rough layout of Mackerel-08 Rev1 PCB
    [mackerel-08-v1.kicad_pcb, mackerel-08-v1.kicad_sch]
2024-07-24 Mackerel-08 PCB Rev1 mostly routed
    [mackerel-08-v1.kicad_sch]
2024-07-25 SPI and DUART schematic work, Rough sketch of Mackerel-30
    [mackerel-08-duart.kicad_sch, mackerel-08-memory.kicad_sch, mackerel-08-power-reset.kicad_sch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]
2024-07-25 Clean up the schematic, ready for final routing
    [mackerel-08-duart.kicad_sch, mackerel-08-memory.kicad_sch, mackerel-08-power-reset.kicad_sch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]
2024-07-26 Mackerel-08 v1 is fully routed, needs graphics, labels, and cleanup
    [mackerel-08-duart.kicad_sch, mackerel-08-power-reset.kicad_sch, mackerel-08-v1.kicad_pcb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]
2024-07-26 Mackerel-08 SVC v1 labeled and ready for final checks
    [mackerel-08-memory.kicad_sch, mackerel-08-v1.kicad_pcb, mackerel-08-v1.kicad_sch]
2024-07-26 Final touches on Mackerel-08 v1
    [mackerel-08-v1.kicad_pcb, mackerel-30-itx.kicad_sch]
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2024-07-31 Start of Mackerel-10 hardware schematic
    [dram.kicad_sch, duart.kicad_sch, low_mem.kicad_sch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]
2024-08-02 Symbol and footprint for SIMM-30 DRAM stubbed out
    [dram.kicad_sch, mackerel-10-v1.kicad_pcb, mackerel-10-v1.kicad_sch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]
2024-08-08 Trying to figure out Mackerel-10 components
    [dram.kicad_sch, duart.kicad_sch, ide.kicad_sch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]
2024-08-13 More progress on Mackerel-10 schematic and PCB
    [dram.kicad_sch, duart.kicad_sch, ide.kicad_sch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]
2024-08-15 Fixed most of the problems with rev 1
    [mackerel-08-duart.kicad_sch, mackerel-08-power-reset.kicad_sch, mackerel-08-v1.kicad_pcb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]
2024-08-19 Mack-08 1.1 schematic fixes done, needs final routing
    [mackerel-08-duart.kicad_sch, mackerel-08-expansion.kicad_sch, mackerel-08-memory.kicad_sch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]
2024-08-19 Rough layout of simplified Mack-10 prototype
    [dram.kicad_sch, duart.kicad_sch, ide.kicad_sch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]
2024-08-20 Mack-08 rev 1.1 routed
    [mackerel-08-duart.kicad_sch, mackerel-08-expansion.kicad_sch, mackerel-08-power-reset.kicad_sch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]
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2024-08-22 Mack-10 proto routed except for expansion headers
    [duart.kicad_sch, expansion.kicad_sch, low_mem.kicad_sch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]
2024-08-22 Mack-10 proto fully routed
    [expansion.kicad_sch, mackerel-10-v1.kicad_pcb, mackerel-10-v1.kicad_sch]
2024-08-22 Mack-10 proto routed and passing DRC
    [duart.kicad_sch, expansion.kicad_sch, mackerel-10-v1.kicad_pcb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]
2024-08-22 Mackerel-10 proto board ready for manufacturing
    [duart.kicad_sch, expansion.kicad_sch, low_mem.kicad_sch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]
2024-08-29 Mackerel-08 rev 1.1 release
    [mackerel-08-duart.kicad_sch, mackerel-08-expansion.kicad_sch, mackerel-08-memory.kicad_sch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]
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2024-09-01 Bootloader prints the correct board name
    [bootloader.c, mackerel.h]
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2024-09-01 Fix SD card select pin for Mackerel-08 rev 1.1
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2024-09-04 Schematic in progress for Mack-10 DRAM board
    [mackerel-10-dram.kicad_pcb, mackerel-10-dram.kicad_sch]
2024-09-06 Cleaned up the DRAM verilog and routed most of the PCB
    [mackerel-10-dram.kicad_pcb, mackerel-10-dram.kicad_sch]
2024-09-15 Update CPLD pin assignments for DRAM breakout PCB
    [mackerel-10-dram.kicad_pcb, mackerel-10-dram.kicad_sch]
2024-09-17 Revert "Update memory map to include DRAM"
    This reverts commit 58ddbbdab17f9018403703d69255f81a645bad25.
    [mackerel.h]
2024-09-20 Stub out IDE breakout schematic
    [mackerel-10-ide.kicad_pcb, mackerel-10-ide.kicad_sch]
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2024-09-24 Move Mackerel-10 protoboards into their own folder
    [duart.kicad_sch, expansion.kicad_sch, low_mem.kicad_sch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]
2024-09-24 Cleanup and new project for Mackerel-10 v1
    [mackerel-10-v1.kicad_pcb, mackerel-10-v1.kicad_sch, mackerel-30-itx.kicad_pcb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]
2024-09-24 Stubbed out mack-10 v1 design
    [dram.kicad_sch, duart.kicad_sch, expansion.kicad_sch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]
2024-09-25 Add Mackerel-08 BOM list
    [mackerel-08-duart.kicad_sch, mackerel-08-expansion.kicad_sch, mackerel-08-memory.kicad_sch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]
2024-09-25 Rough layout of components on PCB
    [dram.kicad_sch, duart.kicad_sch, expansion.kicad_sch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]
2024-09-26 Settled on mini ITX form factor
    [dram.kicad_sch, duart.kicad_sch, expansion.kicad_sch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]
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2024-10-05 Fix SIMM-30 footprint
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2024-10-09 Minor fixes to Mackerel-10 v1 PCB
2024-10-11 Wired most of the control signals for the CPU and DRAM
    [dram.kicad_sch, fpu.kicad_sch, ide.kicad_sch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]
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2024-10-18 Fully DRAM, fixed interrupts
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2024-10-19 IDE interrupts broken
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2024-10-22 Move power-on reset and reset switch handling to CPLD
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2024-10-23 Fix IDE buffer direction and add CS1 pin
    [ide.kicad_sch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]
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2024-10-24 Rearranged power and reset on PCB
    [mackerel-10-v1.kicad_sch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]
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2024-10-29 Mostly fixed the SIMM-72 footprint
    [fpu.kicad_sch, ide.kicad_sch, mackerel-30-proto.kicad_pcb]
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2024-10-29 Add DS1233 for reset
    [dram.kicad_sch, fpu.kicad_sch, ide.kicad_sch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]
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2024-11-02 Rough routing of data bus to FPU and RAM
    [dram.kicad_sch, expansion.kicad_sch, fpu.kicad_sch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]
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2024-11-05 Roughly routed all but expansion and reset
    [dram.kicad_sch, mackerel-30-proto.kicad_sch]
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2024-11-17 Fix name of Mackerel-10 v1.2 schematic
2024-11-17 Replace some function calls with macros in the SPI code
    [spi.c]
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2024-11-24 Fix memory maps for Mack-30
    [bootloader.c, mackerel.h]
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2024-11-26 Fix gcc CPU flags for the different Mackerel hardware revisions
    [mackerel.h]
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2025-01-04 Correct CAS pins are selected based on SIZ and A0/A1 lines
    [bootloader.c]
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2025-09-21 Fixed DRAM controller CAS timing and updated Mack-30 to load and run programs from DRAM
    [bootloader.c, mackerel.h]
2025-09-27 Much faster IDE load times using a lookup table for the bit reverse bug in Mackerel-30
    [bootloader.c]
2025-10-09 Speed up IDE bit reversing, add Linux bootinfo before jumping to Linux kernel
    [bootloader.c]
2025-10-10 Fixed DUART interrupt handling on Mackerel-30
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2025-10-12 Fixed bootloader commandline for console
    [bootloader.c]
2026-05-22 Fixed bootloader bug where any non-printable character registered as backspace
    [bootloader.c]
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2026-05-25 Properly terminate coprocessor cycles with a BERR so the CPU doesn't stall out
2026-05-26 Add timeouts and busy/error checking to bootloader IDE calls
    [bootloader.c]
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2026-06-19 Mackerel-F: Fix SPI pin renaming in constraints file
    [bootloader.c]
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2026-07-05 Mackerel-30: Fix SPI ethernet pin naming for W5500
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
